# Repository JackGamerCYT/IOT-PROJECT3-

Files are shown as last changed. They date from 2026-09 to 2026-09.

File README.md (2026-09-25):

# ⚡ Smart Energy Monitoring & Intelligent Load Management — IoT Project 03

Hệ thống IoT end-to-end: ESP32-S3 đo dòng DC bằng ACS712, tính công suất và điện năng, tự sa thải tải ưu tiên thấp khi vượt ngưỡng đỉnh, gửi dữ liệu qua MQTT về backend FastAPI + cơ sở dữ liệu chuỗi thời gian, hiển thị trên dashboard web thời gian thực kèm trợ lý dữ liệu.

```
 [Adapter 12V]─[cầu chì 2A]─┬─[LM2596 → 5V]──> ESP32-S3, ACS712, relay, OLED, DS3231
                            └─[ACS712 IP+→IP−]─┬─[Relay1]── Quạt 12V  (ưu tiên CAO)
                                               └─[Relay2]── LED 12V   (ưu tiên THẤP)
 ESP32-S3: đo 4 khối/giây · điều khiển cục bộ 2 s/lần · RTC giữ giờ · đệm 600 bản ghi khi mất mạng
      │ MQTT 1883   smartenergy/node9988/{telemetry,status,state,event,cmd,ack}
      ▼
 Broker MQTT ──WSS 8884──> Dashboard (Vercel): realtime, gửi lệnh, đo độ trễ
      │ MQTT 1883
      ▼
 Backend FastAPI (Render 24/7 hoặc laptop) ── SQLite / PostgreSQL(Neon) ── REST /api/*
                                            └── Trợ lý dữ liệu /api/chat
```

## 1. Đáp ứng yêu cầu đề 3

| Yêu cầu trong đề | Cách làm | Ở đâu |
|---|---|---|
| Đo dòng cách ly, điện áp thấp | ACS712-05B, tải DC 12 V, không chạm điện lưới | §3 |
| ≥ 2 tải điều khiển được | Quạt 12 V (ưu tiên cao) + LED 12 V (ưu tiên thấp) | §3 |
| Ghi rõ định mức và bảo vệ | Cầu chì 2 A, diode flyback, relay 10 A/30 VDC, phân áp ADC | `docs/WIRING.md` |
| Telemetry dòng + công suất/điện năng, nêu công thức, đơn vị, tần số | Trung bình 64 mẫu/250 ms, công suất TB 2 s, tích lũy Wh | §4.1 |
| MQTT topic có cấu trúc, QoS, availability | 6 topic, LWT retained | §5 |
| Time-series DB + REST lịch sử/cấu hình | SQLite hoặc PostgreSQL, 5 bảng, 12 endpoint | §6, §7 |
| Dashboard: công suất tức thời, điện năng tích lũy, lịch sử, chi phí, trạng thái tải, cảnh báo | `index.html` | §7 |
| Quản lý tải theo ưu tiên, khôi phục khi an toàn **ổn định** | Máy trạng thái 3 điều kiện + dự báo công suất | §4.2 |
| Phân biệt trạng thái **yêu cầu** và **đã xác nhận** | `cmd_id` → `ack`, UI hiện Yêu cầu / Xác nhận / độ trễ / timeout | §4.3 |
| **Nâng cao**: phát hiện đỉnh, ngân sách điện năng ngày | `peak_today_w`, `ALARM_OVER_LIMIT`, `budget_wh`, `BUDGET_WARN/EXCEEDED` | §4.2 |
| Hành vi an toàn khi mất mạng | Kết nối lại không chặn, SAFE MODE, RTC giữ giờ, đệm và gửi bù | §4.4 |
| Thí nghiệm: sai số, độ trễ, managed/unmanaged, mất kết nối | `/api/stats`, xuất CSV, bảng kịch bản | §10 |

## 2. Cấu trúc repo

```
firmware/esp32_firmware/
  esp32_firmware.ino        Firmware v20 (ESP32-S3 + ACS712 + relay; DS3231/OLED tuỳ chọn)
  secrets.example.h         Copy thành secrets.h, điền WiFi (đã .gitignore)
backend/
  main.py                   FastAPI + MQTT ingest + SQLite/PostgreSQL + trợ lý dữ liệu
  requirements.txt
index.html                  Dashboard, đặt ở GỐC repo để Vercel phục vụ ngay tại "/"
tools/device_simulator.py   Giả lập ESP32 để test khi chưa có phần cứng
docs/
  WIRING.md                 Sơ đồ đấu nối, an toàn, quy trình hàn
  BAO_CAO_IOT_PROJECT03.docx  Báo cáo đồ án 14 đề mục
  PINOUT.xlsx               Bảng chân + danh mục linh kiện
  TRANG_THAI_TRIEN_KHAI.md  Hiện trạng deploy, cách kiểm chứng, việc còn lại
  KHAC_PHUC_SU_CO.md        Web không nhận dữ liệu: cách đọc Serial và tìm nguyên nhân
render.yaml                 Cấu hình deploy backend lên Render
PUSH.md                     Hướng dẫn đẩy code lên GitHub
```

## 3. Phần cứng

| Linh kiện | Chân | ESP32-S3 | Ghi chú |
|---|---|---|---|
| ACS712-05B | OUT | **GPIO 1** qua phân áp 10 kΩ/20 kΩ | 185 mV/A, 2.5 V tại 0 A |
| Relay 2CH (active LOW) | IN1 / IN2 | **GPIO 12 / 13** | Quạt / LED |
| DS3231 (0x68) | SDA / SCL | **GPIO 8 / 9** | Giữ giờ khi mất WiFi |
| SSD1306 (0x3C) | SDA / SCL | **GPIO 8 / 9** | Chung bus I2C với DS3231 |
| Buzzer qua S8050 | — | **GPIO 14** | `-1` nếu không lắp |
| LM2596 | OUT | 5 V / GND | Chỉnh 5.00 V trước khi cắm chip |

Chi tiết đấu nối, mạch động lực, an toàn: `docs/WIRING.md`.

## 4. Firmware v20

### 4.1 Đo lường
- Mỗi 250 ms đọc 64 mẫu `analogReadMilliVolts()` (dùng hiệu chuẩn eFuse của chip), lấy trung bình → `V_out = mV / DIVIDER_RATIO`
- `I [A] = (V_out − V_zero) / 185`; nếu `I < 0.04 A` coi bằng 0 (nhiễu nền). `V_zero` calib lúc khởi động khi 2 tải tắt, hoặc bằng lệnh `calibrate`
- `P [W] = 12 V × I` (điện áp coi là hằng, đo kiểm bằng VOM — ghi trong phần hạn chế)
- `E [Wh] += P × Δt/3600` mỗi khối, lưu Flash mỗi 60 s, reset lúc 0h theo giờ địa phương
- `power_w` gửi lên là **trung bình 2 s** (8 khối); telemetry và vòng điều khiển cùng chu kỳ 2 s

### 4.2 Máy trạng thái quản lý tải
```
LED_ON ──(P > P_peak liên tục ≥ 4 s)──> SHED_PEAK
SHED_PEAK ──(P < P_peak − H liên tục ≥ 15 s  VÀ  LED đã tắt ≥ 20 s
             VÀ  P + P_LED_ước_lượng < P_peak)──> LED_ON
LED_ON ──(E_hôm_nay ≥ ngân sách)──> SHED_BUDGET ──(sang ngày mới)──> LED_ON
LED đã tắt mà vẫn vượt ngưỡng ≥ 10 s → ALARM_OVER_LIMIT + buzzer (quạt ưu tiên cao KHÔNG bị cắt)
```
`P_LED_ước_lượng` được học từ bước nhảy công suất mỗi lần LED đổi trạng thái, nhờ vậy thiết bị không khôi phục khi biết chắc sẽ vượt ngưỡng lại. Ba điều kiện cùng lúc (trễ theo công suất, thời gian tắt tối thiểu, dự báo) là cơ chế chống đóng cắt liên tục.

### 4.3 Lệnh và xác nhận
Web/backend publish `cmd` kèm `cmd_id`. ESP32 áp dụng, publish `ack` chứa `cmd_id` và **trạng thái thực tế** sau khi áp dụng. Dashboard hiển thị riêng "Yêu cầu" và "Xác nhận", đo độ trễ, báo timeout sau 5 s. Bật/tắt tay khi đang AUTO sẽ chuyển thiết bị về MANUAL và sinh sự kiện `MANUAL_OVERRIDE`.

### 4.4 Khi mất mạng
- Kết nối lại WiFi/MQTT không chặn vòng lặp chính → đo và điều khiển vẫn chạy
- Mất broker > 30 s → `safe_mode = true`, tự bật quản lý tải cục bộ dù đang MANUAL
- DS3231 giữ giờ, nên bản ghi vẫn có mốc thời gian đúng; NTP → RTC mỗi 10 phút khi online
- Bộ đệm vòng 600 bản ghi (~20 phút). Có mạng lại thì gửi bù 5 gói/200 ms, gói bù có cờ `"buffered": true` và backend dùng `ts` của thiết bị làm mốc thời gian
- Kết nối lại sinh sự kiện `RECOVERED` kèm thời gian mất kết nối và số gói gửi bù

### 4.5 Nạp firmware
1. Arduino IDE, board **ESP32S3 Dev Module**
2. Library Manager cài **2 thư viện**: `PubSubClient` và `ArduinoJson`
3. Copy `secrets.example.h` → `secrets.h`, điền WiFi
4. Firmware mặc định `USE_RTC 0` / `USE_OLED 0` — chạy được khi **chưa gắn** DS3231 và OLED. Khi nào gắn thì đổi thành `1` và cài thêm `RTClib`, `Adafruit SSD1306`, `Adafruit GFX Library`
5. Có lắp phân áp thì đặt `DIVIDER_RATIO = 0.6667`
6. Upload, mở Serial 115200, **giữ 2 tải tắt** trong 1 giây đầu để calib điểm 0

## 5. Đặc tả MQTT

Gốc topic `smartenergy/<device_id>/`, mặc định `device_id = node9988`.

| Topic | Hướng | QoS / retain | Nội dung |
|---|---|---|---|
| `telemetry` | ESP32 → | 0 | số liệu đo, 2 s/lần |
| `status` | ESP32 → | LWT QoS 1, retained | `online` / `offline` |
| `state` | ESP32 → | retained | cấu hình + trạng thái tải |
| `event` | ESP32 → | 0 | `{type, detail, power_w, limit_w, ts}` |
| `cmd` | web/backend → ESP32 | 1 | `{cmd_id, ts, src, fan?, led?, auto_mode?, peak_limit_w?, hysteresis_w?, budget_wh?, calibrate?, reset_energy?}` |
| `ack` | ESP32 → | 0 | `{cmd_id, cmd_ts, ok, error?, ...state}` |

```json
{"dev":"node9988","ts":1789550319106,"seq":42,"current_a":0.352,"power_w":4.224,
 "energy_today_wh":0.0931,"energy_total_wh":1.204,"peak_today_w":4.301,
 "fan":true,"led":true,"led_shed":"NONE","auto_mode":true,"safe_mode":false,
 "peak_limit_w":3.5,"hysteresis_w":0.5,"budget_wh":0,"led_est_w":1.8,
 "alarm_over":false,"alarm_budget":false,"sensor_mv":2565.1,"zero_mv":2500.0,
 "rssi":-55,"uptime_s":84,"time_src":"ntp","rtc":true,"buffered_count":0}
```

Lý do chọn QoS: telemetry QoS 0 vì gói sau thay gói trước và mất gói được phát hiện qua `seq`; lệnh QoS 1 để không mất lệnh. PubSubClient chỉ publish được QoS 0, nên độ tin cậy của lệnh được bảo đảm ở tầng ứng dụng bằng ACK + timeout 5 s (ghi trong phần hạn chế).

Các loại sự kiện: `SHED`, `RESTORE`, `ALARM_OVER_LIMIT`, `ALARM_CLEAR`, `BUDGET_WARN`, `BUDGET_EXCEEDED`, `MANUAL_OVERRIDE`, `RECOVERED`.

## 6. Cơ sở dữ liệu

Backend tự chọn: có biến `DATABASE_URL` → PostgreSQL (Neon), không có → SQLite. Schema giống nhau, tạo tự động lần chạy đầu.

| Bảng | Cột chính |
|---|---|
| `telemetry` | ts_device, ts_server, seq, current_a, power_w, energy_today_wh, energy_total_wh, peak_today_w, fan, led, led_shed, auto_mode, safe_mode, peak_limit_w, hysteresis_w, budget_wh, alarm_over, alarm_budget, sensor_mv, rssi |
| `events` | ts_device, ts_server, type, detail, power_w, limit_w |
| `availability` | ts_server, status |
| `commands` | cmd_id, source, payload, ts_client, ts_seen_server, ts_ack_server, ack_ok, ack_error, ack_state, latency_ms |
| `settings` | tariff_vnd_per_kwh |

Dữ liệu cũ hơn `RETENTION_DAYS` (mặc định 60) được xóa tự động mỗi 6 giờ.

## 7. REST API (tài liệu tự sinh tại `/docs`)

| Method | Path | Mô tả |
|---|---|---|
| GET | `/api/health` | Trạng thái backend, broker, loại CSDL |
| GET | `/api/status` | Telemetry mới nhất, online/offline, độ tươi dữ liệu, Wh và chi phí hôm nay |
| GET | `/api/history?minutes=&bucket_s=` | Chuỗi thời gian đã gộp (trung bình/đỉnh) |
| GET | `/api/energy/daily?days=` | Wh, đỉnh, chi phí theo ngày |
| GET | `/api/events`, `/api/availability`, `/api/commands` | Nhật ký |
| POST | `/api/command` | `{"fan":true,"wait_ack_s":3}` → trả `requested` và `confirmed` |
| POST | `/api/config` | Ngưỡng, dải trễ, ngân sách, chế độ auto |
| GET/PUT | `/api/settings` | Đơn giá điện |
| GET | `/api/stats?minutes=` | Đỉnh, Wh, thời gian vượt ngưỡng, số lần đóng cắt, tỉ lệ nhận gói, độ trễ |
| POST | `/api/chat` | Trợ lý dữ liệu (§8) |
| GET | `/api/export/{bảng}.csv` | Xuất dữ liệu cho báo cáo |

Khi đặt biến `API_KEY`, mọi POST/PUT phải kèm header `X-API-Key`.

## 8. Trợ lý dữ liệu (chatbot)

Chạy hoàn toàn cục bộ, không gọi API bên ngoài: câu hỏi được chuẩn hoá (bỏ dấu), phân loại ý định bằng biểu thức chính quy, rồi **truy vấn thẳng cơ sở dữ liệu** và ghép câu trả lời từ số liệu thật. Vì không sinh văn bản tự do nên không có nguy cơ bịa số.

Ví dụ hỏi được: *hôm nay dùng bao nhiêu điện*, *tiền điện 7 ngày qua*, *đỉnh công suất hôm nay*, *sa thải tải mấy lần*, *thiết bị offline lúc nào*, *lệnh điều khiển gần đây*, *trạng thái hiện tại*, *so sánh theo ngày*.

Ra lệnh được: *bật quạt*, *tắt đèn*, *bật chế độ tự động*, *đặt ngưỡng 3.5 W*, *đặt ngân sách 20 Wh*. Những câu này **không tự thực thi**: backend trả về trường `action`, dashboard hiện nút "Xác nhận gửi lệnh", người dùng bấm thì mới gọi `/api/command`. Đây là ràng buộc an toàn bắt buộc khi cho ngôn ngữ tự nhiên điều khiển relay.

## 9. Chạy và triển khai

### 9.1 Chạy trên máy (phát triển và demo)
```bash
cd backend
pip install -r requirements.txt
python main.py                       # http://localhost:8000
python ../tools/device_simulator.py  # tuỳ chọn: giả lập ESP32 khi chưa có mạch
```

### 9.2 Hiện trạng triển khai (cập nhật 23/09/2026)

| Thành phần | Địa chỉ | Trạng thái |
|---|---|---|
| Backend + REST API | https://smart-energy-backend-rrvs.onrender.com | Đang chạy, `"db":"postgres"`, `"mqtt_connected":true` |
| Cơ sở dữ liệu | Neon PostgreSQL (pooled, Singapore) | Đã nối, bảng tạo tự động |
| Broker | broker.hivemq.com — TCP 1883 (thiết bị/backend), WSS 8884 (web) | Công khai, không xác thực |
| Dashboard | Vercel, deploy từ `index.html` ở gốc repo | Đang chạy |
| Repo | https://github.com/JackGamerCYT/IOT-PROJECT3- | — |

Kiểm tra nhanh toàn tuyến: `/api/health` → `/api/status` → `/api/history?minutes=10` → `/api/export/telemetry.csv?minutes=60` → SQL Editor trên Neon.

### 9.3 Các bước triển khai lại từ đầu: Neon + Render + Vercel
1. **Neon**: tạo project, copy chuỗi **pooled connection** (`...-pooler...?sslmode=require`)
2. **Render**: New → Blueprint → chọn repo (đã có `render.yaml`) → điền `DATABASE_URL` và `API_KEY` → Apply. Mở `<url>/api/health`, phải thấy `"db":"postgres"` và `"mqtt_connected":true`
3. **Vercel**: Add New → Project → Import repo → Framework Preset = Other, Root Directory để trống, Build/Output Command để trống → Deploy (file `index.html` nằm ngay ở gốc repo nên Vercel phục vụ được luôn)
4. Sửa `const DEFAULT_API = '...'` trong `index.html` thành URL Render rồi push lại; dán `API_KEY` vào ô API Key trên dashboard
5. **Chống ngủ**: gói free của Render tắt service sau ~15 phút không có request, kéo theo mất kết nối MQTT. Tạo job trên cron-job.org gọi `<url>/api/health` mỗi 10 phút

Vì sao cần Render: Vercel chỉ chạy hàm serverless sống vài giây mỗi request, không giữ được kết nối MQTT liên tục để hứng telemetry. Kiến trúc vì vậy tách **worker ingest** (Render) khỏi **giao diện** (Vercel).

Biến môi trường backend: `DATABASE_URL`, `API_KEY`, `MQTT_HOST`, `MQTT_PORT`, `MQTT_USER`, `MQTT_PASS`, `DEVICE_ID`, `TZ_OFFSET_H`, `RETENTION_DAYS`, `PORT`.

## 10. Kịch bản thí nghiệm

| # | Thí nghiệm | Cách làm | Số liệu thu |
|---|---|---|---|
| E1 | Sai số đo | Đồng hồ vạn năng/DC meter nối tiếp, 4 trường hợp: không tải, quạt, LED, cả hai; mỗi trường hợp 30 mẫu | Sai số tuyệt đối và %, độ lệch chuẩn |
| E2 | Độ trễ thiết bị → dashboard | Bật tải, đọc ô "Thiết bị → Dashboard" và `latency_device_to_backend_ms` | Trung bình, p95, max |
| E3 | Độ trễ lệnh → xác nhận | Bấm BẬT/TẮT 30 lần | Trung bình, p95, số lệnh timeout |
| E4 | Unmanaged vs managed | 10 phút AUTO tắt với cả 2 tải bật, ngưỡng 3.5 W → `/api/stats`; lặp lại với AUTO bật | Đỉnh W, Wh, `over_limit_duration_s`, `led_switch_count` |
| E5 | Chống đóng cắt liên tục | Đặt ngưỡng sát tổng công suất, so sánh với cấu hình `hysteresis_w = 0.1`, `MIN_OFF_MS = 0` | Số lần đóng cắt trong 10 phút |
| E6 | Mất mạng | Tắt router 60 s khi đang vượt ngưỡng | Thời điểm OFFLINE (LWT), LED vẫn bị cắt cục bộ, sự kiện `RECOVERED`, số gói gửi bù, khoảng trống dữ liệu |
| E7 | Ngân sách ngày | Đặt `budget_wh` nhỏ (0.5 Wh) | Thời điểm `BUDGET_WARN`/`BUDGET_EXCEEDED`, LED bị cắt |
| E8 | Độ trôi của RTC | So giờ DS3231 với NTP sau 24 giờ | Sai lệch giây/ngày |

## 11. Hạn chế và bảo mật

- Broker HiveMQ công khai không có xác thực: ai biết topic đều đọc và gửi lệnh được. Khắc phục bằng HiveMQ Cloud/EMQX có TLS + tài khoản (firmware và backend đã có sẵn `MQTT_USER`/`MQTT_PASS`) và ACL tách quyền topic `cmd`
- `API_KEY` chỉ bảo vệ REST API, không bảo vệ topic MQTT
- Không đo điện áp thật, giả định 12 V cố định; ACS712 5 A có độ phân giải hạn chế với tải nhỏ. Muốn chính xác hơn dùng INA219/INA226 đo cả V và I
- Một cảm biến đo tổng dòng nên công suất từng tải chỉ là ước lượng từ bước nhảy khi đóng cắt
- ESP32 chỉ publish QoS 0; bộ đệm offline nằm trong RAM nên mất khi reset (có thể nâng cấp sang LittleFS)

## 12. Thành viên

| STT | Họ tên | MSSV | Nhiệm vụ |
|---|---|---|---|
| 1 | Đặng Đình Mạnh | 24119055 | |
| 2 | | | |
| 3 | | | |
| 4 | | | |

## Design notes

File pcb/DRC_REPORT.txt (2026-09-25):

KHONG CO LOI - khoang cach toi thieu 0.4 mm

--- THONG MACH ---
Tat ca net lien mach.

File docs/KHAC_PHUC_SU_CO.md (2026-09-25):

# Web không nhận dữ liệu — cách tìm nguyên nhân

Trước hết cần hiểu: **web chỉ hiển thị, nó không tự tạo ra dữ liệu.** Chuỗi phải thông suốt:

```
ESP32 publish  →  broker.hivemq.com  →  (1) trình duyệt qua WSS 8884
                                      →  (2) backend Render qua TCP 1883 → Neon
```

Nếu ESP32 không publish thì cả web lẫn backend đều trống, badge **Thiết bị** đứng ở `?`.

## Bước 1 — Mở Serial Monitor, đọc 3 dòng đầu

Arduino IDE → Tools → Serial Monitor → **115200 baud** → nhấn nút EN trên ESP32 để khởi động lại.

Firmware v20 in ra ngay khi khởi động:

```
==========================================================
  SMART ENERGY v20  -  IoT PROJECT 03
  Device ID : node9988
  Broker    : broker.hivemq.com:1883
  Telemetry : smartenergy/node9988/telemetry
  ...
```

**Không thấy gì** → chọn sai cổng COM, sai baud, hoặc firmware chưa nạp được. Nạp lại, nhớ chọn board **ESP32S3 Dev Module**.

**Thấy topic là `smartenergy_node9988/telemetry`** (có gạch dưới, không có dấu `/` sau smartenergy) → bạn đang chạy **firmware cũ**. Đây là nguyên nhân phổ biến nhất: topic cũ khác topic web đang nghe nên hai bên không gặp nhau. Nạp lại file `firmware/esp32_firmware/esp32_firmware.ino` mới.

## Bước 2 — Đọc dòng CHẨN ĐOÁN, cứ 5 giây một lần

| Dòng trên Serial | Nghĩa là | Cách sửa |
|---|---|---|
| `WiFi "YOUR_WIFI": KHONG TIM THAY TEN WIFI` | Chưa tạo file `secrets.h` | Copy `secrets.example.h` thành `secrets.h`, điền đúng tên và mật khẩu WiFi, nạp lại |
| `SAI MAT KHAU WIFI` | Sai mật khẩu | Sửa `secrets.h` |
| `KHONG TIM THAY TEN WIFI` dù đã điền đúng | ESP32 chỉ bắt được WiFi **2.4 GHz** | Đổi sang băng tần 2.4 GHz, hoặc phát 4G từ điện thoại |
| `WiFi OK, IP 192.168.x.x ... MQTT chua noi duoc` | Vào mạng được nhưng không ra broker | Xem bước 3 |
| `MQTT loi rc=-2 (KHONG KET NOI DUOC TCP)` | Mạng chặn cổng 1883 | Mạng trường hay chặn. Phát 4G điện thoại thử lại |
| `>>> MQTT DA KET NOI <<<` | Đã lên broker | Sang bước 4 |

## Bước 3 — Mạng trường chặn cổng 1883

Đây là tình huống rất hay gặp ở mạng WiFi trường học. Cách kiểm tra nhanh: phát 4G từ điện thoại, đổi `secrets.h` sang WiFi đó, nạp lại. Nếu chạy được thì chắc chắn do mạng cũ chặn.

Lúc demo trước lớp nên chủ động dùng 4G điện thoại cho ESP32, đừng phụ thuộc WiFi trường.

## Bước 4 — MQTT đã kết nối mà web vẫn trống

Serial sẽ in mỗi 2 giây:

```
[#12 14:32:05] 2501.3mV I=0.000A P=0.00W E=0.000Wh | FAN:OFF LED:OFF(NONE) | MANUAL | MQTT:DA GUI buf=0
```

- `MQTT:DA GUI` → ESP32 đang phát thật. Nếu web vẫn trống thì lỗi nằm ở phía web:
  - Mở trang Vercel, nhìn badge **MQTT** trên đầu trang. Nếu đỏ thì trình duyệt không nối được broker (mạng chặn cổng 8884 hoặc dùng mạng công ty). Thử mở bằng 4G điện thoại.
  - Kéo xuống khung **MQTT LOG** ở cuối trang, nó in ra đúng topic đang nghe. So với dòng `Telemetry :` trên Serial, **hai chuỗi phải giống hệt nhau từng ký tự**.
- `MQTT:CHUA GUI` → mất kết nối broker giữa chừng, quay lại bước 2.

## Bước 5 — Kiểm tra bằng backend

Mở `https://smart-energy-backend-rrvs.onrender.com/api/status`

- `"latest": null` → backend chưa nhận gói nào. ESP32 chưa publish, hoặc publish sai topic.
- Có dữ liệu nhưng web trống → lỗi hiển thị phía trình duyệt, không phải phần cứng.

Backend nghe cùng một broker nhưng qua cổng 1883 từ máy chủ Render, không bị mạng trường ảnh hưởng. Nên nếu backend thấy dữ liệu mà trình duyệt không thấy, gần như chắc chắn mạng chỗ bạn chặn cổng 8884.

## Chưa gắn OLED và DS3231 thì sao?

Không sao cả. Firmware v20 đã đặt sẵn:

```cpp
#define USE_RTC  0
#define USE_OLED 0
```

Với cấu hình này chỉ cần **2 thư viện**: `PubSubClient` và `ArduinoJson`. Không cần RTClib, Adafruit SSD1306, Adafruit GFX — thiếu chúng là lỗi biên dịch chứ không phải lỗi chạy, và cũng là một nguyên nhân khiến "nạp mãi không được".

Mất RTC thì giờ lấy từ NTP khi có mạng; lúc mất mạng thiết bị vẫn cắt tải bình thường, chỉ là dữ liệu đệm không có mốc thời gian nên bỏ qua. Mất OLED thì chỉ mất phần hiển thị tại chỗ.

Khi nào mua module về, đổi hai dòng đó thành `1`, cài đủ 5 thư viện, nối SDA→GPIO 8, SCL→GPIO 9, VCC→3V3, GND→GND rồi nạp lại.

## Phần cứng tối thiểu để web chạy

Chỉ cần: **ESP32-S3 + cáp USB + WiFi**. Không cần ACS712, không cần relay, không cần OLED.

Firmware vẫn publish đều 2 giây một gói, chỉ là dòng điện đọc ra 0 A. Đủ để chứng minh toàn tuyến ESP32 → broker → backend → Neon → web hoạt động. Cắm thêm cảm biến và relay sau.

## Không có mạch thì test bằng giả lập

Trên laptop, tại thư mục dự án:

```powershell
pip install paho-mqtt
python tools/device_simulator.py
```

Giả lập gửi đúng topic và đúng định dạng như ESP32 thật. Nếu **giả lập hiện lên web mà ESP32 thì không**, lỗi chắc chắn nằm ở ESP32 hoặc mạng của nó, không phải ở web hay backend. Đây là phép thử phân định nhanh nhất.

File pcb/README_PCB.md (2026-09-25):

# Mạch in 1 lớp cho Project 03 — hướng dẫn ủi đồng

Board **100 × 80 mm**, **chỉ 1 lớp đồng mặt dưới (BOTTOM)**, toàn bộ linh kiện là loại **cắm (through-hole)**, module relay **để ngoài**, trên mạch chỉ có hàng rào cắm.

File trong thư mục này:

| File | Dùng để làm gì |
|---|---|
| `BOTTOM_mirrored_iron.pdf` | **Bản in để ủi** — đã lật gương sẵn, tỉ lệ 1:1 |
| `BOTTOM_normal_check.pdf` | Bản không lật, dùng đối chiếu khi dò mạch bằng đồng hồ |
| `TOP_placement.pdf` | Sơ đồ cắm linh kiện, nhìn từ mặt linh kiện |
| `smart_energy.kicad_pcb` | Mở bằng KiCad 7/8/9 nếu muốn sửa |
| `make_pcb.py` | Script sinh lại toàn bộ (sửa toạ độ rồi chạy `python3 make_pcb.py`) |
| `ASSEMBLY_SHEET.pdf` | **Phiếu lắp ráp 3 trang**: sơ đồ vị trí, thứ tự lắp có ô tick, bảng đấu dây ra module ngoài, danh sách đo kiểm |
| `BOM_DRILL.md` | Danh sách linh kiện + mũi khoan |
| `DRC_REPORT.txt` | Kết quả tự kiểm tra khoảng cách và thông mạch |

Thông số thiết kế: đường tín hiệu 0.6 mm, đường nguồn 1.0 mm, khe cách điện tối thiểu 0.4 mm, phủ đồng GND toàn mặt dưới, pad 2.0 mm (domino 2.6 mm).

Vùng phủ đồng GND có **thermal relief**: mỗi chân GND nối với vùng đồng bằng 4 nan rộng 0.9 mm thay vì dính liền cả mảng. Nhờ vậy mỏ hàn không bị hút nhiệt, mối hàn ăn thiếc dễ hơn nhiều. Script cũng tự bỏ các mảnh đồng mảnh hơn 0.6 mm và các mảnh đồng cô lập không nối GND, nên bản in không còn sợi đồng vụn khó ăn mòn.

## 1. Bảng nối chân

| Rào | Chân trên mạch | Nối tới |
|---|---|---|
| **J1** (1×22) | hàng **trái** ESP32-S3 DevKitC-1 | 3V3, IO8, IO9, IO12, IO13, IO14, 5V, GND |
| **J3** (1×22) | hàng **phải** ESP32-S3 DevKitC-1 | IO1 (ADC), GND |
| **J4** (1×4) | 3V3 · SDA · SCL · GND | module DS3231 |
| **J5** (1×4) | 3V3 · SDA · SCL · GND | module OLED SSD1306 |
| **J6** (1×5) | IN1 · IN2 · 3V3 · 5V · GND | **module relay 2 kênh để ngoài** |
| **J7** (1×3) | 5V · OUT · GND | module ACS712-05B |
| **J9** | GND · 12V+ | nguồn adapter 12 V vào |
| **F1** | IN · OUT | cầu chì 2 A (đế 5×20 hoặc đoạn dây) |
| **J8** | 12V+ · GND | 12 V **đã qua cầu chì**, đi ra ACS712 IP+ và cọc COM của relay |
| **J10** | IN+ · IN− | ngõ vào module LM2596 |
| **J11** | OUT+ · OUT− | ngõ ra 5 V của LM2596 |

Cách đấu module relay: tháo jumper JD-VCC trên module, nối **JD-VCC ↔ chân 5V của J6**, **VCC ↔ chân 3V3 của J6**, GND/IN1/IN2 theo tên. Nhờ vậy cuộn dây relay chạy 5 V còn opto chạy mức 3.3 V của ESP32, tắt dứt khoát.

Mạch động lực (12 V qua ACS712 rồi qua tiếp điểm relay tới quạt và đèn) đi **dây ngoài**, không chạy trên mạch in. Trên board chỉ có dòng nuôi mạch điều khiển, nên đường 12 V rộng 1 mm là đủ.

## 2. Hai dây nối trên mặt linh kiện (JW1, JW2)

Mạch 1 lớp không tránh được vài chỗ giao nhau. Thiết kế này chỉ cần **2 đoạn dây đồng** hàn ở **mặt linh kiện**:

- **JW1** — nối GND bắc qua đường 5 V, dài 4.8 mm
- **JW2** — nối GND bắc qua hai đường IN1/IN2, dài 7 mm

Dùng chân điện trở cắt ra là vừa. Thiếu 2 dây này thì phần GND của DS3231, OLED, relay và tụ lọc sẽ hở mạch.

## 3. Quy trình ủi đồng

1. **In** file `BOTTOM_mirrored_iron.pdf` bằng máy in laser lên giấy in chuyển nhiệt (hoặc giấy ảnh bóng). Trong hộp thoại in phải chọn **Scale 100% / Actual size**, tuyệt đối không chọn Fit to page. In xong đo lại board trên giấy phải đúng 100 × 80 mm.
2. **Cắt phíp** đồng 1 mặt đúng 100 × 80 mm, chà mặt đồng bằng giấy nhám mịn rồi lau cồn cho sạch dầu mỡ.
3. **Ủi**: úp mặt mực xuống đồng, bàn ủi để mức cotton (khoảng 160–180 °C), ủi đều 5–8 phút, miết kỹ mép board.
4. **Ngâm nước** ấm 10 phút rồi bóc giấy thật từ từ. Chỗ nào mực thiếu thì tô lại bằng bút lông dầu.
5. **Ăn mòn**: FeCl₃ hoặc hỗn hợp HCl + H₂O₂ (3:1), lắc nhẹ 10–20 phút. **Đeo găng và kính, làm nơi thoáng.**
6. **Rửa sạch**, lau mực bằng cồn hoặc axeton.
7. **Khoan**: mũi 0.9 mm cho điện trở/transistor, 1.0 mm cho hàng rào và tụ, 1.3 mm cho domino và cầu chì, 3.2 mm cho 4 lỗ bắt ốc.
8. **Kiểm tra trước khi hàn**: đồng hồ nấc thông mạch, đo 12V–GND, 5V–GND, 3V3–GND, **không được kêu**. Soi đèn tìm đường đứt hoặc dính.
9. **Hàn** theo thứ tự: dây nối JW1/JW2 → điện trở, diode → transistor, tụ → hàng rào → domino → cuối cùng là cầu chì và còi.
10. **Chỉnh LM2596 ra đúng 5.00 V trước khi cắm ESP32.** Cấp 12 V vào J9, đo tại J11 OUT+ và GND.

## 4. Kiểm tra sau khi hàn

| Bước | Cách đo | Đạt khi |
|---|---|---|
| Ngắn mạch nguồn | Đo trở giữa 12V–GND, 5V–GND, 3V3–GND khi chưa cắm module | Không kêu tít, trở > vài trăm Ω |
| Điện áp | Cấp 12 V, đo J11 OUT+ | 5.00 V ± 0.05 |
| 3V3 | Cắm ESP32, đo chân 3V3 của J4 | 3.3 V |
| I2C | Đo thông mạch J4.SDA ↔ J5.SDA ↔ chân IO8 của J1 | Kêu tít |
| Relay | Đo J6.IN1 ↔ IO12 của J1, J6.IN2 ↔ IO13 | Kêu tít |
| ADC | Đo J7.OUT ↔ R1, và R1 ↔ IO1 của J3 | Kêu tít |
| GND | Đo GND của J4, J5, J6, J7 với GND của J9 | Tất cả đều thông (nhờ JW1, JW2) |

## 5. Ghi chú thiết kế

- Cầu phân áp **R1 10 kΩ / R2 20 kΩ** hạ mức ra của ACS712 từ 0–5 V xuống 0–3.33 V cho ADC. Sau khi lắp nhớ đặt `DIVIDER_RATIO = 0.6667` trong firmware.
- **C2 100 nF** song song R2 lọc nhiễu cho đường ADC, **C1 100 µF** lọc 5 V, **C3 100 nF** lọc 3V3.
- **Q1 S8050** lái còi, **R3 1 kΩ** hạn dòng cực nền. Chân theo thứ tự **E–B–C** từ trên xuống, mặt phẳng quay ra ngoài board; kiểm tra lại datasheet transistor bạn mua.
- LM2596 lấy nguồn **trước** ACS712, nên dòng của mạch điều khiển không bị tính vào phép đo tải.
- Thứ tự chân của J1/J3 lấy theo tài liệu ESP32-S3-DevKitC-1 v1.1 của Espressif. Nếu board bạn mua khác thứ tự, sửa `J1_NETS`/`J3_NETS` trong `make_pcb.py` rồi chạy lại script.

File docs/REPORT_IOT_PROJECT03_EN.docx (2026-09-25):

HO CHI MINH CITY UNIVERSITY OF TECHNOLOGY AND EDUCATION

FACULTY OF ELECTRICAL AND ELECTRONICS ENGINEERING

FINAL COURSE PROJECT REPORT

COURSE: IOT FOUNDATIONS AND APPLICATIONS

PROJECT 03: SMART ENERGY MONITORING AND INTELLIGENT LOAD MANAGEMENT

Team members:

Dang Dinh Manh – 24119055

……………………… – …………

……………………… – …………

……………………… – …………

Supervisor: ………………………

Ho Chi Minh City, September 2026

# TABLE OF CONTENTS

(Open in Word, right-click the table of contents, choose Update Field → Update entire table to generate page numbers.)

# 1. INTRODUCTION AND PROBLEM STATEMENT

Household and small laboratory electrical demand frequently exceeds a safe threshold for short intervals when several appliances run at the same time. The consequences are nuisance breaker trips, wasted energy and shortened wiring life. Users, however, rarely know how much power they are drawing at a given moment, or which device should be disconnected before the limit is crossed.

This project builds a complete IoT system that addresses the problem at a safe model scale: it measures the current and power of two 12 V DC loads in real time, stores the history in a time-series database, displays it on a web interface, automatically sheds the low-priority load when demand exceeds a peak limit, and restores it only when conditions have been stably safe.

Specific objectives:

- Measure current and power with a quantified error; raw ADC counts are not accepted as a final measurement.
- Transmit data over MQTT with a structured topic hierarchy and detect device online/offline state through the Last Will and Testament mechanism.
- Store time-series data and expose REST APIs for history, configuration and statistics.
- Manage loads by priority, with an anti-chattering mechanism, and keep operating when the network is lost.
- Provide a real-time dashboard that clearly separates the requested state from the state the device has actually confirmed.
- Add an advanced component: peak demand detection and a daily energy budget.

Scope: the entire power circuit operates at 12 VDC and no part touches the mains supply, in accordance with the safety requirement of the assignment.

# 2. REQUIREMENTS AND THEORETICAL BACKGROUND

## 2.1. Requirement mapping

Requirement | Implementation in this project
Isolated, low-voltage current measurement | ACS712-05B Hall-effect sensor, 12 V DC loads
At least two controllable loads | 12 V fan (high priority) and 12 V LED lamp (low priority)
MQTT with structured topics, QoS, availability | Six topics under smartenergy/node9988, retained LWT
Time-series database and REST API | SQLite or PostgreSQL, five tables, twelve endpoints
Dashboard with full metrics and alarms | Real-time web interface, charts, event log
Priority-based load management, anti-chattering | State machine with hysteresis, minimum time and power prediction
Requested state distinct from acknowledged state | cmd_id and ack message pair
Advanced component | Peak demand detection and daily energy budget
Safe behaviour during network loss | Local safe mode, RTC timekeeping, store-and-forward buffer

Table 2.1. Mapping between assignment requirements and the implemented solution

## 2.2. Hall-effect current sensing

The ACS712 routes the load current through an integrated copper conduction path. The magnetic field produced is proportional to the current, is sensed by a Hall element and converted into an output voltage. The 5 A variant has a sensitivity of 185 mV/A and an output of half the supply voltage at zero current, that is 2.5 V on a 5 V rail. The conduction path is galvanically isolated from the signal circuit with a nominal withstand voltage of 2.1 kV, which is why this device satisfies the isolated-measurement requirement of the assignment.

I [A] = (V_out - V_zero) / 0.185

V_out : voltage at the sensor OUT pin (V)

V_zero: output voltage at zero current, obtained by calibration

Because the load is DC, the mean of many samples reflects the true load current and no RMS computation is required. Conversely, applying an RMS formula to a noisy DC signal adds the noise in quadrature and biases the result upwards; this was an actual defect found and corrected during development, described in chapter 12.

## 2.3. Power and energy

P [W] = U x I (U = 12 V, treated as constant)

E [Wh] = sum of P x dt / 3600

Cost = E/1000 x tariff [currency per kWh]

The backend recomputes energy by trapezoidal integration over the telemetry series in order to cross-check the accumulator kept on the device. Gaps longer than ten seconds are excluded from the integral so that a loss of connectivity does not produce a fabricated value.

## 2.4. Hysteresis control and anti-chattering theory

A controller with a single threshold oscillates continuously whenever the measured quantity sits near that threshold. The classical remedy is a hysteresis band: shed the load when P exceeds P_peak but restore it only when P falls below P_peak minus H. For this system hysteresis alone is still insufficient, because restoring the load itself raises the demand and may immediately exceed the limit again. The project therefore applies three simultaneous conditions: a hysteresis band in power, a minimum dwell time, and a prediction step for the demand after restoration.

## 2.5. The MQTT protocol

MQTT is a publish/subscribe protocol over TCP, well suited to embedded devices because of its small packets and long-lived connections. It defines three quality-of-service levels: QoS 0 delivers at most once, QoS 1 at least once and QoS 2 exactly once. The Last Will and Testament mechanism lets the broker publish a predefined message when it loses contact with a device, so failures are detected without polling. The retained flag makes a newly subscribed client receive the most recent message on a topic immediately.

# 3. SYSTEM ARCHITECTURE

[12V adapter]-[2A fuse]-+-[LM2596 -> 5V]-> ESP32-S3, ACS712,

| relays, OLED, DS3231

+-[ACS712]-+-[Relay 1]- 12V fan (HIGH priority)

+-[Relay 2]- 12V LED (LOW priority)

ESP32-S3: 4 sample blocks/s, local control loop every 2 s,

RTC timekeeping, 600-record store-and-forward buffer

| MQTT 1883 smartenergy/node9988/{telemetry,status,state,event,cmd,ack}

v

MQTT broker --WSS 8884--> Dashboard (Vercel): live data, commands,

latency measurement

| MQTT 1883

v

FastAPI backend (Render, 24/7) -- SQLite / PostgreSQL (Neon)

-- REST /api/* + data assistant /api/chat

Figure 3.1. Overall system architecture

The system has four layers. The device layer (ESP32-S3) performs measurement and real-time control; every switching decision is taken here, so protection does not depend on the network. The communication layer is the MQTT broker, which mediates between device, backend and interface. The data layer is the FastAPI backend: it subscribes to every topic, writes to the database and exposes REST APIs. The application layer is the web dashboard, which receives live values directly from the broker over WebSocket Secure and fetches history from the REST API.

One design point deserves emphasis. The dashboard is deployed on Vercel, a platform that serves static files and serverless functions whose lifetime is a few seconds per request. Such a platform cannot hold a persistent MQTT connection to ingest telemetry, so the ingest process must run on an always-on service (Render, or a local computer). Separating the ingest worker from the interface is therefore a technical consequence, not an arbitrary choice.

Main data flow: the ESP32 measures and publishes telemetry every two seconds; the backend writes it into the telemetry table with two timestamps, the instant the device created the packet and the instant the server received it, which makes end-to-end latency measurable. The control flow runs in the opposite direction: the dashboard or the REST API publishes a command on the cmd topic, the device applies it and publishes an ack message; the backend records both the command and the acknowledgement and computes the latency between them.

# 4. HARDWARE

## 4.1. Bill of materials

No. | Component | Key specification | Role
1 | ESP32-S3 DevKitC-1 N16R8 | Xtensa LX7 dual-core 240 MHz, Wi-Fi, 12-bit ADC | Main controller
2 | ACS712-05B | ±5 A, 185 mV/A, 2.1 kV isolation | Load current sensing
3 | 2-channel 5 V relay module | Opto-isolated, active low, 10 A/30 VDC contacts | Load switching
4 | LM2596 buck converter | 4–35 V in, 5.0 V out, 3 A | Supply for the control circuit
5 | DS3231 | I2C RTC, ±2 ppm, battery backup | Timekeeping without network
6 | SSD1306 OLED | 0.96 inch, 128×64, I2C | Local display
7 | 12 V DC fan | about 0.2–0.4 A | Load 1, high priority
8 | 12 V LED bar | about 0.1–0.3 A | Load 2, low priority
9 | 12 V – 2 A adapter | | Main supply
10 | 2 A fuse, 1N4007 diode, 10 kΩ/20 kΩ resistors | | Protection and ADC divider

Table 4.1. Bill of materials

## 4.2. Pin assignment

Component | Pin | ESP32-S3 | Function
ACS712 | OUT (through 10 kΩ/20 kΩ divider) | GPIO 1 (ADC1_CH0) | Analogue current signal
Relay module | IN1 | GPIO 12 | Load 1 – 12 V fan
Relay module | IN2 | GPIO 13 | Load 2 – 12 V LED
DS3231 (0x68) | SDA / SCL | GPIO 8 / GPIO 9 | Real-time clock
SSD1306 (0x3C) | SDA / SCL | GPIO 8 / GPIO 9 | Display, shared I2C bus
Buzzer via S8050 | Base through 1 kΩ | GPIO 14 | Over-limit alarm
LM2596 | OUT+ / OUT− | 5V / GND | 5 V supply

Table 4.2. Pin connection table

## 4.3. Protection design and engineering decisions

- A 10 kΩ/20 kΩ divider at the ACS712 output: at 5 A the sensor output reaches 3.43 V, beyond the safe ADC range of the ESP32-S3. The ratio of 0.667 maps the 0–5 V range onto 0–3.33 V.
- A 2 A fuse on the +12 V line, placed ahead of the sensor, protects the entire power circuit.
- A 1N4007 diode in reverse parallel with the fan suppresses the back-EMF produced when the inductive load is switched off.
- Relay contacts rated 10 A/30 VDC, many times the actual load current of under 1 A, provide a wide safety margin.
- Removing the JD-VCC jumper on the relay module and supplying VCC from 3.3 V ensures the ESP32 logic high fully turns the optocoupler off.
- The ESP32-S3 was chosen over the classic ESP32 because GPIO 12 on the latter is the MTDI strapping pin; a high level at boot selects the wrong flash voltage and prevents start-up.
- The LM2596 is fed upstream of the sensor so that the control circuit current is not counted in the load measurement.

# 5. PROTOCOL AND NETWORKING

## 5.1. Topic hierarchy and quality of service

Topic | Direction | QoS / retain | Content
smartenergy/node9988/telemetry | Device → system | QoS 0 | Measurements, every 2 s
smartenergy/node9988/status | Device → system | QoS 1, retained, LWT | online / offline
smartenergy/node9988/state | Device → system | retained | Configuration and load state
smartenergy/node9988/event | Device → system | QoS 0 | Shedding, restoration, alarms
smartenergy/node9988/cmd | Web/backend → device | QoS 1 | Commands carrying cmd_id
smartenergy/node9988/ack | Device → system | QoS 0 | Command acknowledgement and actual state

Table 5.1. MQTT topic specification

Telemetry uses QoS 0 because each message completely supersedes the previous one; loss is detected through the monotonically increasing seq field, which also yields a packet success rate without the handshake overhead of QoS 1. Commands are subscribed at QoS 1. The PubSubClient library on the ESP32 only publishes at QoS 0, so command reliability is guaranteed at application level by the cmd_id/ack pair with a five second timeout; this is a known limitation stated in chapter 13.

## 5.2. Message format

{"dev":"node9988","ts":1789550319106,"seq":42,

"current_a":0.352,"power_w":4.224,"energy_today_wh":0.0931,

"energy_total_wh":1.204,"peak_today_w":4.301,

"fan":true,"led":true,"led_shed":"NONE","auto_mode":true,"safe_mode":false,

"peak_limit_w":3.5,"hysteresis_w":0.5,"budget_wh":0,"led_est_w":1.8,

"alarm_over":false,"alarm_budget":false,"sensor_mv":2565.1,"zero_mv":2500.0,

"diff_mv":65.1,"rssi":-55,"uptime_s":84,"time_src":"ntp","buffered_count":0}

The ts field is Unix time in milliseconds, taken from NTP or from the DS3231. Every message carries the device identifier, so the system scales to multiple nodes without changing the structure.

## 5.3. Availability detection

On connection the device registers an "offline" will on the status topic with the retained flag, then publishes "online" itself. If the device loses power or drops off the network, the broker publishes "offline" once the fifteen second keepalive expires, so the dashboard and the backend learn exactly when the device stopped working. The dashboard additionally tracks data freshness: if no new packet arrives within six seconds, that is three telemetry periods, it displays a stale-data warning.

# 6. BACKEND AND DATA

## 6.1. Database schema

Table | Main columns | Purpose
telemetry | ts_device, ts_server, seq, current_a, power_w, energy_today_wh, peak_today_w, fan, led, led_shed, auto_mode, safe_mode, peak_limit_w, alarm_over, sensor_mv, rssi | Measurement time series
events | ts_device, ts_server, type, detail, power_w, limit_w | Shedding, restoration, alarms
availability | ts_server, status | Online/offline history
commands | cmd_id, source, payload, ts_client, ts_seen_server, ts_ack_server, ack_ok, latency_ms | Command log and acknowledgement latency
settings | key, value | Electricity tariff

Table 6.1. Database schema

The backend supports SQLite (local development) and PostgreSQL (the Neon service for 24/7 deployment) simultaneously. The data access layer converts the syntax between the two engines, so a single code base runs in both environments. Data older than the configured retention period is purged every six hours.

## 6.2. REST endpoints

Endpoint | Function
GET /api/status | Latest telemetry, availability, data freshness, energy and cost for the day
GET /api/history?minutes=&bucket_s= | Aggregated time series, capped at 300 points
GET /api/energy/daily?days= | Energy, peak and cost per day
GET /api/events | /api/availability | /api/commands | Logs
POST /api/command | Send a command, wait for acknowledgement, return requested and confirmed state
POST /api/config | Peak limit, hysteresis, budget, automatic mode
GET /api/stats?minutes= | Statistics for the experimental chapter
POST /api/chat | Data assistant
GET /api/export/{table}.csv | Data export for the report

Table 6.2. REST API list

The /api/stats endpoint aggregates, over a time window: peak power, mean power, energy, total time above the limit, load switching count, packet success rate derived from gaps in seq, and both device-to-server and command-to-acknowledgement latency as mean, 95th percentile and maximum. This is exactly the data set used in the experimental chapter.

# 7. APPLICATION AND USER INTERFACE

The dashboard is a single web page. It receives live values directly from the broker over WebSocket Secure and fetches history from the REST API, so the interface keeps showing real-time data even when the backend is temporarily unavailable; only the history section is lost.

- Six metric cards: instantaneous power with its limit, current, energy for the day with a budget progress bar, estimated cost, peak power for the day, and load management mode.
- A real-time chart with a selectable window of 1, 5, 15 or 60 minutes and three series: power, peak limit and current; power on the left axis in watts, current on the right axis in amperes.
- A load control panel that separates the requested state from the state confirmed by the device, with acknowledgement latency and a timeout warning.
- A configuration panel: automatic mode, peak limit, hysteresis, daily budget, zero-point calibration, energy reset and electricity tariff.
- An alarm and event log that merges live messages with history fetched from the backend.
- A history panel: power charts over 1 hour, 6 hours, 24 hours and 7 days, plus a bar chart of daily energy for the last seven days, refreshed automatically every thirty seconds.
- An experiment panel: latency in both directions, packet success rate, unacknowledged command count, a statistics button and CSV export.
- A data assistant and an MQTT log window for troubleshooting during the live demonstration.

The local OLED shows the time from the DS3231, power, current, energy for the day, the state of both loads, Wi-Fi and MQTT icons and the number of buffered records. This demonstrates during the presentation that the device operates independently of the network.

## 7.1. Data assistant

The assistant runs entirely inside the backend. A question is normalised by stripping Vietnamese diacritics, classified into an intent by regular expressions, and then answered by querying the database directly and formatting the real figures. Because no free text is generated, there is no possibility of fabricated numbers, unlike an approach based on a large language model.

For control phrasings the system does not execute anything by itself; it returns an action descriptor, the interface shows a confirmation button, and only a user click sends the command. This is a mandatory safety constraint when natural language is allowed to operate relays.

## 7.2. Backend ingest code

The backend subscribes to all six topics. For telemetry messages the noteworthy detail is the handling of buffered packets: a packet carrying the "buffered" flag uses the device timestamp as its storage timestamp, so data forwarded after a network outage lands at the correct position on the history chart instead of piling up at the moment of reception.

def on_message(client, userdata, msg):

ts = now_ms()

kind = msg.topic.rsplit("/", 1)[-1]

raw = msg.payload.decode("utf-8", "replace")

try:

if kind == "status":

status = raw.strip().lower()

if status != live["status"]:

exec_("INSERT INTO availability(ts_server,status) VALUES(?,?)", (ts, status))

live.update(status=status, status_ts=ts)

return

data = json.loads(raw)

if kind == "telemetry":

vals = [int(v) if isinstance(v, bool) else v for v in (data.get(c) for c in TEL_COLS)]

# Gói gửi bù sau khi mất mạng: lấy mốc thời gian của thiết bị làm ts_server

ts_row = int(data["ts"]) if data.get("buffered") and data.get("ts") else ts

exec_(f"INSERT INTO telemetry(dev,ts_device,ts_server,seq,{','.join(TEL_COLS)}) "

f"VALUES(?,?,?,?,{','.join('?' * len(TEL_COLS))})",

(data.get("dev"), data.get("ts") or None, ts_row, data.get("seq"), *vals))

if not data.get("buffered") and live["status"] != "online":

live.update(status="online", status_ts=ts)

elif kind == "state":

live["state"] = data

elif kind == "event":

exec_("INSERT INTO events(dev,ts_device,ts_server,type,detail,power_w,limit_w) VALUES(?,?,?,?,?,?,?)",

(data.get("dev"), data.get("ts") or None, ts, data.get("type"), data.get("detail"),

data.get("power_w"), data.get("limit_w")))

elif kind == "cmd":

cidv = data.get("cmd_id") or f"anon-{ts}"

db.insert_ignore("commands", ["cmd_id", "dev", "source", "payload", "ts_client", "ts_seen_server"],

(cidv, DEVICE_ID, data.get("src", "unknown"), raw, data.get("ts"), ts), "cmd_id")

exec_("UPDATE commands SET ts_seen_server=COALESCE(ts_seen_server,?) WHERE cmd_id=?", (ts, cidv))

elif kind == "ack":

cidv = data.get("cmd_id", "")

row = q("SELECT ts_seen_server FROM commands WHERE cmd_id=?", (cidv,), one=True)

lat = ts - row["ts_seen_server"] if row and row["ts_seen_server"] else None

exec_("UPDATE commands SET ts_ack_server=?, ack_ok=?, ack_error=?, ack_state=?, latency_ms=? WHERE cmd_id=?",

(ts, int(bool(data.get("ok"))), data.get("error"), raw, lat, cidv))

live["state"] = {k: v for k, v in data.items() if k not in ("cmd_id", "cmd_ts", "ok", "error")}

if cidv in ack_waiters:

ack_waiters[cidv].set()

except Exception as e:

print(f"[MQTT] bad message on {msg.topic}: {e} | {raw[:120]}")

## 7.3. Database access layer

The DB class lets the same source run on SQLite during development and on PostgreSQL in production by translating parameter markers and conditional insert syntax:

class DB:

def __init__(self, url: str, sqlite_path: str):

self.pg = url.startswith(("postgres://", "postgresql://"))

if self.pg:

import psycopg

from psycopg.rows import dict_row

from psycopg_pool import ConnectionPool

self.pool = ConnectionPool(url, min_size=1, max_size=5, timeout=15,

kwargs={"row_factory": dict_row, "autocommit": True})

self.pool.wait(timeout=30)

print(f"[DB] PostgreSQL: {url.split('@')[-1].split('?')[0]}")

else:

self.conn = sqlite3.connect(sqlite_path, check_same_thread=False)

self.conn.row_factory = sqlite3.Row

self.lock = threading.Lock()

print(f"[DB] SQLite: {sqlite_path}")

def _sql(self, sql: str) -> str:

return sql.replace("?", "%s") if self.pg else sql

def query(self, sql, args=(), one=False):

if self.pg:

with self.pool.connection() as c:

rows = c.execute(self._sql(sql), args).fetchall()

else:

with self.lock:

rows = [dict(r) for r in self.conn.execute(sql, args).fetchall()]

return (rows[0] if rows else None) if one else rows

def execute(self, sql, args=()):

if self.pg:

with self.pool.connection() as c:

c.execute(self._sql(sql), args)

else:

with self.lock:

self.conn.execute(sql, args)

self.conn.commit()

def insert_ignore(self, table, cols, args, key):

ph = ",".join("?" * len(cols))

tail = f" ON CONFLICT ({key}) DO NOTHING" if self.pg else ""

head = "INSERT INTO" if self.pg else "INSERT OR IGNORE INTO"

self.execute(f"{head} {table}({','.join(cols)}) VALUES({ph}){tail}", args)

def upsert_setting(self, key, value):

if self.pg:

self.execute("INSERT INTO settings VALUES(?,?) ON CONFLICT (key) DO UPDATE SET value=EXCLUDED.value", (key, value))

else:

self.execute("INSERT OR REPLACE INTO settings VALUES(?,?)", (key, value))

def init_schema(self):

## 7.4. Real-time chart code

The browser keeps a WebSocket connection to the broker and appends a point as soon as a message arrives, rather than polling the server. The buffer is trimmed by time rather than by point count, so changing the display window does not distort the horizontal axis:

function rtRedraw() {

const cut = Date.now() - RT_WINDOW_MIN * 60000;

while (rtBuf.length && rtBuf[0].t < cut) rtBuf.shift();

while (rtBuf.length > RT_MAX_POINTS) rtBuf.shift();

rt.data.labels = rtBuf.map(d => timeStr(d.t));

rt.data.datasets[0].data = rtBuf.map(d => d.p);

rt.data.datasets[1].data = rtBuf.map(d => d.lim);

rt.data.datasets[2].data = rtBuf.map(d => d.i);

rt.update('none');

$('rt-n').textContent = rtBuf.length;

}

function rtPush(t, p, limit, i) {

rtBuf.push({ t, p, lim: limit, i });

if (!S.paused) rtRedraw();

}

$('rt-range').onchange = e => {

RT_WINDOW_MIN = Number(e.target.value);

rtBuf.length = 0; // nạp lại từ backend cho đủ cửa sổ mới

if (S.apiOk) prefillChart(); else rtRedraw();

};

$('rt-pause').onclick = () => {

# 8. CONTROL AND SYSTEM INTELLIGENCE

## 8.1. Priority-based load shedding algorithm

Every 2 seconds, with P the 2-second mean power:

IF managed AND LED is on AND (P > P_peak continuously >= 4 s)

-> SHED the LED, state SHED_PEAK, emit event SHED

ELSE IF managed AND LED is off AND state = SHED_PEAK

AND (P < P_peak - H continuously >= 15 s)

AND (LED has been off >= 20 s)

AND (P + estimated P_LED < P_peak)

-> RESTORE the LED, emit event RESTORE

IF LED is off AND P still > P_peak continuously >= 10 s

-> ALARM_OVER_LIMIT + buzzer (the high-priority fan is never shed)

The three restoration conditions complement one another. The hysteresis band prevents oscillation caused by measurement noise around the threshold. The minimum dwell time prevents oscillation caused by rapidly varying loads. The prediction condition is the most important: the power of the LED lamp is estimated from the power step observed each time the lamp changes state, using an exponential moving average with weights 0.7 and 0.3. If the present demand plus the estimated lamp power exceeds the limit, the system does not restore, because it knows the load would have to be shed again immediately.

The fan is the high-priority load and is never shed automatically. When demand remains above the limit after the lamp has been shed, the system raises an alarm and leaves the decision to the operator instead of disconnecting an important appliance on its own.

## 8.2. Advanced component: peak detection and daily energy budget

The device continuously records the peak power of the day and publishes it in telemetry. When demand stays above the limit while the low-priority load has already been shed, the system raises a peak alarm, that is, it detects a situation in which the available shedding measure is insufficient.

The daily energy budget allows a watt-hour quota per day. At eighty per cent of the quota the system issues an early warning. Once the quota is exceeded the low-priority load is shed and is only re-enabled on the following day. This policy is fully explainable in terms of rules, which makes it convenient to defend and to verify, unlike a black-box approach.

## 8.3. Requested state versus confirmed state

Every command carries a randomly generated cmd_id. The device applies the command and then publishes an ack message containing the same cmd_id together with the actual state of both relays after application. The interface displays two separate lines, measures the latency with the browser clock and reports an error if no acknowledgement arrives within five seconds. This mechanism exposes the true nature of a distributed system: a command that has been sent is not a command that has been executed.

One case deserves attention: a user switching a load by hand while automatic mode is active. The device switches to manual mode and emits a MANUAL_OVERRIDE event, rather than letting two mechanisms fight over the same relay.

## 8.4. Measurement code

The following function runs four times per second on the ESP32. Three technical points are worth noting: averaging 64 samples to suppress noise, taking the absolute value of the deviation so that the measurement does not depend on the sensor wiring polarity, and automatically re-calibrating the zero point while both loads are off.

void measureBlock() {

unsigned long now = millis();

float dt_h = (last_block ? (now - last_block) : BLOCK_MS) / 3600000.0;

last_block = now;

last_mv = readMvAvg(SAMPLES_PER_BLOCK);

diff_mv = last_mv - zero_mv;

// TRỊ TUYỆT ĐỐI: tải một chiều, nếu lỡ đấu ngược IP+/IP- thì vẫn đo đúng độ lớn

float i = fabs(diff_mv) / ACS_MV_PER_A;

if (i < I_DEADBAND_A) i = 0;

current_a = i;

power_w = V_NOMINAL * current_a;

// TỰ HIỆU CHỈNH ĐIỂM 0: khi cả 2 tải đang TẮT, kéo zero_mv bám theo mức thực tế

// (bù trôi do đổi nguồn USB <-> LM2596, do nhiệt độ). Hằng số thời gian ~12 giây.

if (!fan_on && !led_on) {

if (!zero_track_ms) zero_track_ms = now;

if (now - zero_track_ms > 3000 && fabs(diff_mv) < 400)

zero_mv += (last_mv - zero_mv) * 0.02f;

} else {

zero_track_ms = 0;

}

energy_today_wh += power_w * dt_h;

energy_total_wh += power_w * dt_h;

sum_block_p += power_w; n_block++;

The absolute value arises from a real defect: the first version wrote "if (i < deadband) i = 0", which forced every negative value to zero. When the IP+ and IP− terminals of the sensor were connected the other way round, the output voltage fell below the 2.5 V reference, the computed current became negative and was discarded entirely; the system reported 0 A while the load was running. Chapter 12 records the full account.

The automatic zero tracking addresses reference drift when the supply changes. Measurements recorded a drift of about 30 mV between USB powering and LM2596 powering, equivalent to an error of 0.17 A if left uncompensated.

## 8.5. Load management state machine code

void controlStep() {

unsigned long now = millis();

if (learn_pending && now - led_switch_ms >= TELEMETRY_MS) {

float delta = fabs(demand_w - p_before_switch);

if (delta > 0.2) led_est_w = (led_est_w <= 0) ? delta : 0.7 * led_est_w + 0.3 * delta;

learn_pending = false;

}

bool over = demand_w > peak_limit_w;

bool safe = demand_w < peak_limit_w - hysteresis_w;

over_since = over ? (over_since ? over_since : now) : 0;

safe_since = safe ? (safe_since ? safe_since : now) : 0;

if (demand_w > peak_today_w) peak_today_w = demand_w;

long k = todayKey();

if (k && k != day_key) {

if (day_key) { energy_today_wh = 0; peak_today_w = 0; budget_warned = false; alarm_budget = false; }

day_key = k;

if (led_shed == SHED_BUDGET && (auto_mode || safe_mode)) switchLed(true, SHED_NONE);

}

bool managed = auto_mode || safe_mode;

if (budget_wh > 0) {

if (!budget_warned && energy_today_wh >= 0.8 * budget_wh) { budget_warned = true; publishEvent("BUDGET_WARN", "80% ngan sach ngay"); }

if (!alarm_budget && energy_today_wh >= budget_wh) { alarm_budget = true; publishEvent("BUDGET_EXCEEDED", "vuot ngan sach ngay"); }

}

if (managed && alarm_budget && led_on) {

switchLed(false, SHED_BUDGET);

publishEvent("SHED", "LED - vuot ngan sach ngay");

}

if (managed && led_on && over_since && now - over_since >= T_OVER_MS) {

switchLed(false, SHED_PEAK);

publishEvent("SHED", "LED - vuot nguong dinh");

} else if (managed && !led_on && led_shed == SHED_PEAK && !alarm_budget &&

safe_since && now - safe_since >= T_SAFE_MS &&

now - led_switch_ms >= MIN_OFF_MS &&

demand_w + led_est_w < peak_limit_w) {

switchLed(true, SHED_NONE);

publishEvent("RESTORE", "LED - dieu kien an toan on dinh");

}

bool should_alarm = over_since && now - over_since >= T_ALARM_MS && !led_on;

if (should_alarm && !alarm_over) { alarm_over = true; publishEvent("ALARM_OVER_LIMIT", "van vuot nguong sau khi sa thai"); }

if (!over && alarm_over) { alarm_over = false; publishEvent("ALARM_CLEAR", "cong suat da ve duoi nguong"); }

buzzer(alarm_over);

## 8.6. Command acknowledgement code

The device receives a command, applies it, then publishes an acknowledgement carrying the same command identifier and the actual state of both relays:

void onMqtt(char* topic, byte* payload, unsigned int len) {

StaticJsonDocument<512> in;

if (deserializeJson(in, (const char*)payload, len)) return;

char cmd_id[40] = "";

strlcpy(cmd_id, in["cmd_id"] | "", sizeof(cmd_id));

uint64_t t_cmd = in["ts"] | (uint64_t)0;

bool ok = true; String err = "";

if (in["fan"].is<bool>() || in["led"].is<bool>()) {

if (auto_mode) { auto_mode = false; publishEvent("MANUAL_OVERRIDE", "lenh tay -> chuyen MANUAL"); }

if (in["fan"].is<bool>()) { fan_on = in["fan"]; setRelay(PIN_RELAY_FAN, fan_on); }

if (in["led"].is<bool>()) switchLed(in["led"].as<bool>(), SHED_NONE);

}

if (in["auto_mode"].is<bool>()) auto_mode = in["auto_mode"];

if (!in["peak_limit_w"].isNull()) {

float v = in["peak_limit_w"]; if (v >= 0.5 && v <= 60) peak_limit_w = v; else { ok = false; err += "peak_limit_w ngoai [0.5,60]; "; }

}

if (!in["hysteresis_w"].isNull()) {

float v = in["hysteresis_w"]; if (v >= 0.1 && v <= 10) hysteresis_w = v; else { ok = false; err += "hysteresis_w ngoai [0.1,10]; "; }

}

if (!in["budget_wh"].isNull()) {

float v = in["budget_wh"]; if (v >= 0 && v <= 10000) { budget_wh = v; alarm_budget = false; budget_warned = false; }

else { ok = false; err += "budget_wh ngoai [0,10000]; "; }

}

if (in["reset_energy"] == true) { energy_today_wh = 0; peak_today_w = 0; alarm_budget = false; budget_warned = false; }

if (in["calibrate"] == true) {

if (fan_on || led_on) { ok = false; err += "tat ca 2 tai truoc khi calib; "; } else calibrateZero();

}

prefs.putFloat("limit", peak_limit_w); prefs.putFloat("hyst", hysteresis_w);

prefs.putFloat("budget", budget_wh); prefs.putBool("auto", auto_mode);

StaticJsonDocument<512> ack;

ack["cmd_id"] = cmd_id; ack["cmd_ts"] = t_cmd; ack["ok"] = ok;

if (!ok) ack["error"] = err;

fillState(ack);

publishJson(T_ACK, ack);

publishState();

Serial.printf("[CMD] id=%s ok=%d %s\n", cmd_id, ok, err.c_str());

# 9. SECURITY AND RELIABILITY

## 9.1. Behaviour during network loss

- Wi-Fi and MQTT reconnection never blocks the main loop; measurement and control keep running on their two-second cycle while reconnection is attempted.
- If the broker is unreachable for more than thirty seconds the device enters safe mode: local load management is activated even if the device was in manual mode.
- The DS3231 keeps time without Wi-Fi, so records created during an outage carry correct timestamps; when the network returns, NTP time is written back to the RTC every ten minutes.
- A 600-record circular buffer, about twenty minutes, stores data during an outage and forwards it at five packets per 200 ms on reconnection. Forwarded packets carry the buffered flag and the backend uses the device timestamp, so the history chart is not distorted.
- Reconnection emits a RECOVERED event carrying the outage duration and the number of forwarded packets, which is used as evidence in the experiments.
- Critical configuration is stored in flash, so thresholds and mode survive a power cycle.

## 9.2. Security

Threat | Impact | Current mitigation | Planned improvement
A stranger publishes on the cmd topic | Unauthorised load switching | Hard-to-guess topic name; every command is logged with its source | Authenticated broker with per-topic ACL
Telemetry eavesdropping | Usage patterns disclosed | No personal data in the messages | MQTT over TLS on port 8883
Arbitrary REST calls | Remote configuration changes | X-API-Key header required on every POST and PUT | Per-user authentication, separate view and control rights
Wi-Fi password exposed in source | Unauthorised access to the local network | Moved to secrets.h and excluded from Git | Provisioning through a first-boot access point
The assistant misreads an intent | Unintended switching | Manual confirmation required before any command is sent | Per-user audit log

Table 9.1. Risk analysis and mitigations

The main security limitation is the public broker without authentication. This was a conscious choice so that the system works under the network conditions available at the university, and the source is already prepared for a switch to an authenticated broker through configuration only.

# 10. EXPERIMENTAL METHOD

ID | Experiment | Procedure | Quantities collected
E1 | Measurement error | A reference ammeter in series; four cases: no load, fan, lamp, both; 30 samples each | Absolute and percentage error, standard deviation
E2 | Device to dashboard latency | Compare the packet timestamp with the display instant over 100 consecutive packets | Mean, 95th percentile, maximum
E3 | Command to acknowledgement latency | Thirty on/off operations, read from the interface and the commands table | Mean, 95th percentile, timeouts
E4 | Managed versus unmanaged operation | Two ten-minute runs with identical loads and limit, automatic mode off then on | Peak power, energy, time above limit, switching count
E5 | Anti-chattering | Set the limit close to the combined load; compare the full configuration against one without hysteresis and minimum time | Switching operations per ten minutes
E6 | Network loss and recovery | Disconnect the router for sixty seconds while above the limit | Offline detection instant, local behaviour, forwarded packets, residual data gap
E7 | Daily energy budget | Set a small quota and observe the warning and shedding behaviour | Time of the 80 % warning and of the quota breach
E8 | RTC drift | Compare DS3231 time against NTP after 24 hours | Seconds of drift per day

Table 10.1. Experiment matrix

Instrumentation: the interface displays latency and packet success rate directly; the /api/stats endpoint aggregates them over a window; CSV export allows the raw data to be reprocessed in a spreadsheet. Every figure in the results chapter comes from these three sources and none is entered by hand.

# 11. RESULTS AND DISCUSSION

The tables below are completed after running the experiments on the physical prototype.

## 11.1. Measurement error (E1)

Case | Reference (A) | System (A) | Error (A) | Error (%) | Std. dev. (A)
No load
Fan only
LED lamp only
Both loads

Table 11.1. Measurement error results

## 11.2. Latency (E2, E3)

Metric | Samples | Mean (ms) | 95th percentile (ms) | Maximum (ms)
Device → backend
Device → dashboard
Command → acknowledgement

Table 11.2. Latency results

## 11.3. Managed versus unmanaged operation (E4)

Metric over 10 minutes | Unmanaged | Managed | Difference
Peak power (W)
Energy consumed (Wh)
Time above limit (s)
Load switching operations
Packet success rate (%)

Table 11.3. Effectiveness of load management

## 11.4. Anti-chattering (E5) and network loss (E6)

Configuration | Switching operations / 10 min | Comment
All three conditions (H = 0.5 W, 15 s, 20 s, with prediction)
Single threshold, no hysteresis, no minimum time

Table 11.4. Effectiveness of the anti-chattering mechanism

Observation (E6) | Result
Offline detected after disconnection (s)
Local shedding behaviour during the outage
Records forwarded after recovery
Residual gap on the chart (s)
Time from reconnection to continuous data (s)

Table 11.5. Network loss experiment results

## 11.5. Discussion

The discussion should answer four questions: whether the measurement error is small enough relative to the control threshold; whether the end-to-end latency is compatible with the two-second control cycle; by what percentage load management reduces the time spent above the limit compared with unmanaged operation; and how the system behaves when the network is lost. If the measurement error exceeds roughly one tenth of the threshold, the voltage divider, the quality of the 5 V rail and the zero-point calibration should be reviewed.

# 12. DEVELOPMENT PROCESS AND DEFECTS RESOLVED

The system went through several rounds of debugging. This chapter records the defects with technical value, because they illustrate the characteristic traps of a multi-layer IoT system: a fault rarely sits in one place, it hides at the boundary between layers.

Defect | Symptom | Root cause | Resolution
Chart never plotted | Metric cards updated but the curve stayed flat at zero | chart.data.datasets.data written instead of datasets[0].data; the exception was swallowed by a try/catch block | Fixed the array index and moved to a time-based buffer
Current always zero | Loads were running but power read 0 W | A clamp forced negative values to zero, so a reversed IP+/IP− connection discarded the entire measurement | Take the absolute value of the voltage deviation
Zero point drift | Sensor read 2499 mV while the stored zero was 2530 mV | The reference level changed when the supply moved from USB to the LM2596 | Automatic zero tracking while both loads are off, time constant of twelve seconds
Protection stopped during outage | Load shedding ceased when the broker was unreachable | The reconnection routine used a blocking loop with delay, which stalled the control loop | Non-blocking reconnection; the control loop was decoupled from network tasks
Fundamentally wrong current computation | Readings biased high at small loads | An RMS formula applied to a DC signal adds noise in quadrature | Use the sample mean, which is correct for a DC load
Device and web never met | Both reported a successful broker connection yet no data appeared | The old topic tree used an underscore while the new one used a slash | A single topic tree, with the topic name printed to the serial port for comparison
Web deployment returned 404 | The deployed page would not open | The interface file lived in a subdirectory while the platform looked for it at the repository root | Moved the interface file to the repository root
Continuous switching | The auxiliary load cycled rapidly around the threshold | A single threshold; after restoration the limit was exceeded again immediately | Three simultaneous conditions: hysteresis, minimum time, predicted power after restoration

Table 12.1. Defects found and how they were resolved

The lesson is that in a distributed system a layer reporting success does not mean the system is working. The device reported a successful publish, the browser reported a successful connection, yet with two different topic names the data could never meet. The team therefore added observation points at every layer: the topic name printed to the serial port, the data freshness indicator on the interface, the backend status endpoint, and direct database queries.

# 13. LIMITATIONS

- The public MQTT broker has no authentication; anyone who knows the topic names can read the data and send commands.
- The supply voltage is assumed to be a constant 12 V rather than measured, so the accuracy of the power figure depends on the stability of the supply.
- The 5 A ACS712 has limited resolution for loads below about 0.3 A; an INA219 or INA226 would perform considerably better in that range.
- A single sensor measures the total current, so the power of an individual load is only an estimate derived from the step observed at switching.
- The PubSubClient library only publishes at QoS 0; command reliability relies on the application-level acknowledgement mechanism.
- The offline buffer lives in RAM and is lost on reset; it could be upgraded to LittleFS storage.
- The free tier of the hosting service suspends the instance without traffic, so a periodic keep-alive task is required and short data gaps remain possible.

# 14. CONCLUSION

The project delivers a complete IoT system for energy monitoring and intelligent load management, working end to end from the sensor to the web interface. It measures current and power with a documented calibration procedure, transmits data over MQTT with a structured topic hierarchy and availability detection, stores history in a time-series database with REST access, and provides a real-time dashboard that distinguishes requested state from confirmed state.

The most substantial technical contribution lies in control and reliability. The restoration mechanism based on three simultaneous conditions, including a prediction of the power after restoration, fully resolves the continuous switching that a single threshold cannot address. Decoupling the local control loop from network tasks, combined with a real-time clock and a store-and-forward buffer, preserves both the safety function and data integrity during a network outage.

Future work: migrate to an authenticated broker with TLS; replace the ACS712 with an INA226 to measure both voltage and current at higher resolution; extend the design to several measurement nodes with load coordination between them; and add short-term load forecasting so that shedding becomes anticipatory rather than reactive.

# 15. REFERENCES

[1] Allegro MicroSystems, "ACS712: Fully Integrated, Hall Effect-Based Linear Current Sensor IC", Datasheet, Rev. 18.

[2] Espressif Systems, "ESP32-S3 Technical Reference Manual", 2024.

[3] Espressif Systems, "ESP32-S3 Series Datasheet — ADC Characteristics and Calibration", 2024.

[4] Espressif Systems, "ESP32-S3-DevKitC-1 v1.1 User Guide", esp-dev-kits documentation.

[5] OASIS, "MQTT Version 5.0 — OASIS Standard", 2019.

[6] Analog Devices, "DS3231 Extremely Accurate I2C-Integrated RTC/TCXO/Crystal", Datasheet.

[7] Solomon Systech, "SSD1306 Advance Information — 128x64 Dot Matrix OLED/PLED Driver".

[8] S. Ramirez, "FastAPI Documentation", https://fastapi.tiangolo.com

[9] Eclipse Foundation, "Eclipse Paho MQTT Python Client Documentation".

[10] N. O'Leary, "PubSubClient — Arduino Client for MQTT", https://pubsubclient.knolleary.net

[11] B. Blanchon, "ArduinoJson Documentation", https://arduinojson.org

[12] K. Ogata, "Modern Control Engineering", 5th ed., Prentice Hall, 2010 (on-off control and hysteresis).

# 16. TEAM CONTRIBUTIONS

No. | Full name | Student ID | Responsibilities | Contribution
1 | Dang Dinh Manh | 24119055 | Circuit design, ESP32-S3 firmware, load management algorithm
2 | | | FastAPI backend, database, service deployment
3 | | | Web dashboard, data assistant, user interface
4 | | | Experiments, error and latency measurement, report writing

Table 16.1. Task allocation

Full source code: https://github.com/JackGamerCYT/IOT-PROJECT3-

# APPENDIX A. COMPLETE ESP32-S3 FIRMWARE SOURCE

File firmware/esp32_firmware/esp32_firmware.ino. Built with the Arduino IDE, board ESP32S3 Dev Module, two libraries: PubSubClient and ArduinoJson. Wi-Fi credentials live in a separate secrets.h file and are therefore absent from the public repository.

1 | /*

2 | * =====================================================================================

3 | * PROJECT 03 - SMART ENERGY MONITORING & INTELLIGENT LOAD MANAGEMENT

4 | * Firmware v21 - ESP32-S3 (N16R8)

5 | *

6 | * v19 thêm so với v17/v18:

7 | * - DS3231 (I2C): giữ giờ khi mất WiFi; NTP -> RTC khi online, RTC -> hệ thống khi offline

8 | * - SSD1306 OLED 128x64 (I2C): hiện giờ, công suất, điện năng, trạng thái tải, mạng

9 | * - Bộ đệm vòng 600 bản ghi (~20 phút): mất broker thì lưu lại, có mạng gửi bù

10 | * (gói gửi bù có "buffered":true, backend dùng ts thiết bị làm mốc thời gian)

11 | *

12 | * Thư viện cần cài (Library Manager):

13 | * PubSubClient · ArduinoJson · RTClib · Adafruit SSD1306 · Adafruit GFX Library

14 | * Không lắp module nào thì đặt USE_RTC / USE_OLED = 0, firmware vẫn chạy đầy đủ.

15 | * =====================================================================================

16 | */

17 |

18 | #define ARDUINOJSON_USE_LONG_LONG 1

19 |

20 | // ======================================================

21 | // CHUA GAN DS3231 / OLED thi de nguyen 0 (chi can 2 thu vien PubSubClient + ArduinoJson).

22 | // Khi nao gan module roi thi doi thanh 1 va cai them RTClib, Adafruit SSD1306, Adafruit GFX.

23 | // ======================================================

24 | #define USE_RTC 0

25 | #define USE_OLED 0

26 |

27 | #include <WiFi.h>

28 | #include <PubSubClient.h>

29 | #include <ArduinoJson.h>

30 | #include <Preferences.h>

31 | #include <time.h>

32 | #include <sys/time.h>

33 | #if USE_RTC || USE_OLED

34 | #include <Wire.h>

35 | #endif

36 | #if USE_RTC

37 | #include <RTClib.h>

38 | #endif

39 | #if USE_OLED

40 | #include <Adafruit_GFX.h>

41 | #include <Adafruit_SSD1306.h>

42 | #endif

43 |

44 | // -------------------------------------------------------------------------------------

45 | // 1. BÍ MẬT (tạo secrets.h cạnh file .ino, KHÔNG commit)

46 | // -------------------------------------------------------------------------------------

47 | #if __has_include("secrets.h")

48 | #include "secrets.h"

49 | #else

50 | #define WIFI_SSID "YOUR_WIFI"

51 | #define WIFI_PASSWORD "YOUR_PASSWORD"

52 | #define MQTT_USER ""

53 | #define MQTT_PASS ""

54 | #endif

55 |

56 | // -------------------------------------------------------------------------------------

57 | // 2. MQTT - cây topic: smartenergy/<device_id>/<kênh>

58 | // -------------------------------------------------------------------------------------

59 | const char* DEVICE_ID = "node9988";

60 | const char* MQTT_BROKER = "broker.hivemq.com";

61 | const int MQTT_PORT = 1883;

62 |

63 | const char* T_TELEMETRY = "smartenergy/node9988/telemetry";

64 | const char* T_STATUS = "smartenergy/node9988/status";

65 | const char* T_STATE = "smartenergy/node9988/state";

66 | const char* T_EVENT = "smartenergy/node9988/event";

67 | const char* T_CMD = "smartenergy/node9988/cmd";

68 | const char* T_ACK = "smartenergy/node9988/ack";

69 |

70 | // -------------------------------------------------------------------------------------

71 | // 3. PHẦN CỨNG

72 | // -------------------------------------------------------------------------------------

73 | const int PIN_ACS712 = 1; // ADC1_CH0, nên qua cầu phân áp 10k/20k

74 | const int PIN_RELAY_FAN = 12; // Tải 1 - Quạt 12V (ưu tiên CAO), relay active LOW

75 | const int PIN_RELAY_LED = 13; // Tải 2 - LED 12V (ưu tiên THẤP), relay active LOW

76 | const int PIN_BUZZER = 14; // -1 nếu không lắp

77 | const int PIN_I2C_SDA = 8; // DS3231 + SSD1306 dùng chung

78 | const int PIN_I2C_SCL = 9;

79 | const uint8_t ADDR_OLED = 0x3C;

80 |

81 | const float ACS_MV_PER_A = 185.0;

82 | const float DIVIDER_RATIO = 1.0; // 0.6667 nếu dùng phân áp 10k (trên) / 20k (dưới)

83 | const float V_NOMINAL = 12.0;

84 | const float I_DEADBAND_A = 0.04;

85 |

86 | // -------------------------------------------------------------------------------------

87 | // 4. THÔNG SỐ ĐO / ĐIỀU KHIỂN

88 | // -------------------------------------------------------------------------------------

89 | const unsigned long BLOCK_MS = 250;

90 | const int SAMPLES_PER_BLOCK = 64;

91 | const unsigned long TELEMETRY_MS = 2000;

92 | const unsigned long T_OVER_MS = 4000;

93 | const unsigned long T_SAFE_MS = 15000;

94 | const unsigned long MIN_OFF_MS = 20000;

95 | const unsigned long T_ALARM_MS = 10000;

96 | const unsigned long OFFLINE_SAFE_MS = 30000;

97 | const unsigned long SAVE_MS = 60000;

98 | const unsigned long OLED_MS = 500;

99 | const int BUF_SIZE = 600; // ~20 phút dữ liệu đệm

100 |

101 | float peak_limit_w = 3.0;

102 | float hysteresis_w = 0.5;

103 | float budget_wh = 0.0;

104 | bool auto_mode = false;

105 |

106 | // -------------------------------------------------------------------------------------

107 | // 5. BIẾN TRẠNG THÁI

108 | // -------------------------------------------------------------------------------------

109 | enum ShedReason { SHED_NONE = 0, SHED_PEAK, SHED_BUDGET };

110 | const char* shedName(int r) { return r == SHED_PEAK ? "PEAK" : r == SHED_BUDGET ? "BUDGET" : "NONE"; }

111 |

112 | bool fan_on = false, led_on = false;

113 | int led_shed = SHED_NONE;

114 | unsigned long led_switch_ms = 0;

115 |

116 | float zero_mv = 2500.0, last_mv = 0, diff_mv = 0;

117 | unsigned long zero_track_ms = 0;

118 | float current_a = 0, power_w = 0, demand_w = 0;

119 | double sum_block_p = 0; int n_block = 0;

120 | double energy_today_wh = 0, energy_total_wh = 0;

121 | float peak_today_w = 0;

122 | long day_key = 0;

123 |

124 | unsigned long over_since = 0, safe_since = 0;

125 | float led_est_w = 0, p_before_switch = -1;

126 | bool learn_pending = false;

127 | bool alarm_over = false, alarm_budget = false, budget_warned = false;

128 |

129 | bool safe_mode = false;

130 | unsigned long mqtt_lost_ms = 0;

131 | unsigned long last_block = 0, last_tele = 0, last_save = 0, last_mqtt_try = 0,

132 | last_wifi_try = 0, last_oled = 0, last_flush = 0;

133 | unsigned long seq = 0;

134 |

135 | // Bộ đệm vòng khi mất kết nối

136 | struct Rec { uint32_t ts; float i, p, e; uint8_t flags; };

137 | Rec buf[BUF_SIZE];

138 | int buf_head = 0, buf_count = 0;

139 |

140 | bool have_rtc = false, have_oled = false;

141 | const char* time_src = "none";

142 |

143 | WiFiClient net;

144 | PubSubClient mqtt(net);

145 | Preferences prefs;

146 | String client_id;

147 | #if USE_RTC

148 | RTC_DS3231 rtc;

149 | #endif

150 | #if USE_OLED

151 | Adafruit_SSD1306 oled(128, 64, &Wire, -1);

152 | #endif

153 |

154 | // -------------------------------------------------------------------------------------

155 | uint64_t epochMs() {

156 | struct timeval tv; gettimeofday(&tv, nullptr);

157 | if (tv.tv_sec < 1700000000) return 0;

158 | return (uint64_t)tv.tv_sec * 1000ULL + tv.tv_usec / 1000;

159 | }

160 | uint32_t epochS() { time_t t = time(nullptr); return t > 1700000000 ? (uint32_t)t : 0; }

161 |

162 | long todayKey() {

163 | time_t now = time(nullptr); if (now < 1700000000) return 0;

164 | struct tm t; localtime_r(&now, &t);

165 | return (t.tm_year + 1900) * 10000L + (t.tm_mon + 1) * 100L + t.tm_mday;

166 | }

167 | void clockStr(char* out, size_t n) {

168 | time_t now = time(nullptr);

169 | if (now < 1700000000) { snprintf(out, n, "--:--:--"); return; }

170 | struct tm t; localtime_r(&now, &t);

171 | snprintf(out, n, "%02d:%02d:%02d", t.tm_hour, t.tm_min, t.tm_sec);

172 | }

173 |

174 | const char* mqttErr(int rc) {

175 | switch (rc) {

176 | case -4: return "het thoi gian cho broker tra loi";

177 | case -3: return "mat ket noi mang";

178 | case -2: return "KHONG KET NOI DUOC TCP (mang chan cong 1883?)";

179 | case -1: return "broker tu choi / ngat ket noi";

180 | case 0: return "OK";

181 | case 1: return "broker khong ho tro phien ban MQTT";

182 | case 2: return "client_id bi tu choi";

183 | case 3: return "broker dang ban";

184 | case 4: return "sai user/password";

185 | case 5: return "khong duoc phep ket noi";

186 | default: return "khong ro";

187 | }

188 | }

189 |

190 | const char* wifiErr(int st) {

191 | switch (st) {

192 | case WL_NO_SSID_AVAIL: return "KHONG TIM THAY TEN WIFI (sai SSID?)";

193 | case WL_CONNECT_FAILED: return "SAI MAT KHAU WIFI";

194 | case WL_CONNECTION_LOST: return "mat song";

195 | case WL_DISCONNECTED: return "dang ket noi...";

196 | case WL_IDLE_STATUS: return "dang cho";

197 | case WL_CONNECTED: return "da ket noi";

198 | default: return "khong ro";

199 | }

200 | }

201 |

202 | void setRelay(int pin, bool on) { digitalWrite(pin, on ? LOW : HIGH); }

203 | void buzzer(bool on) { if (PIN_BUZZER >= 0) digitalWrite(PIN_BUZZER, on ? HIGH : LOW); }

204 |

205 | void publishJson(const char* topic, JsonDocument& doc, bool retained = false) {

206 | if (!mqtt.connected()) return;

207 | char b[768];

208 | size_t n = serializeJson(doc, b, sizeof(b));

209 | mqtt.publish(topic, (const uint8_t*)b, n, retained);

210 | }

211 |

212 | void publishEvent(const char* type, const char* detail) {

213 | Serial.printf("[EVENT] %s %s | P=%.2fW limit=%.2fW\n", type, detail, demand_w, peak_limit_w);

214 | StaticJsonDocument<384> d;

215 | d["dev"] = DEVICE_ID; d["ts"] = epochMs(); d["type"] = type; d["detail"] = detail;

216 | d["power_w"] = demand_w; d["limit_w"] = peak_limit_w; d["energy_today_wh"] = energy_today_wh;

217 | publishJson(T_EVENT, d);

218 | }

219 |

220 | void fillState(JsonDocument& d) {

221 | d["dev"] = DEVICE_ID; d["ts"] = epochMs();

222 | d["fan"] = fan_on; d["led"] = led_on; d["led_shed"] = shedName(led_shed);

223 | d["auto_mode"] = auto_mode; d["safe_mode"] = safe_mode;

224 | d["peak_limit_w"] = peak_limit_w; d["hysteresis_w"] = hysteresis_w; d["budget_wh"] = budget_wh;

225 | }

226 | void publishState() { StaticJsonDocument<384> d; fillState(d); publishJson(T_STATE, d, true); }

227 |

228 | void switchLed(bool on, int reason) {

229 | if (on == led_on) { led_shed = on ? SHED_NONE : reason; return; }

230 | p_before_switch = demand_w; learn_pending = true;

231 | led_on = on; led_shed = on ? SHED_NONE : reason; led_switch_ms = millis();

232 | setRelay(PIN_RELAY_LED, on);

233 | publishState();

234 | }

235 |

236 | // -------------------------------------------------------------------------------------

237 | // 6. ĐỒNG HỒ THỜI GIAN THỰC

238 | // -------------------------------------------------------------------------------------

239 | void initRTC() {

240 | #if USE_RTC

241 | if (!rtc.begin(&Wire)) { Serial.println("[RTC] khong tim thay DS3231"); return; }

242 | have_rtc = true;

243 | if (rtc.lostPower()) Serial.println("[RTC] mat nguon, gio chua dung - se chinh lai khi co NTP");

244 | DateTime n = rtc.now();

245 | if (n.unixtime() > 1700000000) { // lấy giờ RTC làm giờ hệ thống ngay khi khởi động

246 | struct timeval tv; tv.tv_sec = (time_t)n.unixtime(); tv.tv_usec = 0;

247 | settimeofday(&tv, nullptr);

248 | time_src = "rtc";

249 | Serial.printf("[RTC] gio tu DS3231: %04d-%02d-%02d %02d:%02d:%02d\n",

250 | n.year(), n.month(), n.day(), n.hour(), n.minute(), n.second());

251 | }

252 | #endif

253 | }

254 |

255 | void syncRtcFromNtp() {

256 | #if USE_RTC

257 | if (!have_rtc) return;

258 | uint32_t s = epochS();

259 | if (!s) return;

260 | DateTime cur = rtc.now();

261 | long diff = (long)cur.unixtime() - (long)s;

262 | if (diff > 2 || diff < -2) { // lệch quá 2 s mới ghi lại

263 | rtc.adjust(DateTime(s));

264 | Serial.println("[RTC] da dong bo DS3231 theo NTP");

265 | }

266 | #endif

267 | }

268 |

269 | // -------------------------------------------------------------------------------------

270 | // 7. OLED

271 | // -------------------------------------------------------------------------------------

272 | void initOLED() {

273 | #if USE_OLED

274 | if (!oled.begin(SSD1306_SWITCHCAPVCC, ADDR_OLED)) { Serial.println("[OLED] khong tim thay SSD1306"); return; }

275 | have_oled = true;

276 | oled.clearDisplay(); oled.setTextColor(SSD1306_WHITE); oled.setTextSize(1);

277 | oled.setCursor(0, 24); oled.println(" SMART ENERGY v19"); oled.display();

278 | #endif

279 | }

280 |

281 | void drawOLED() {

282 | #if USE_OLED

283 | if (!have_oled) return;

284 | char t[16]; clockStr(t, sizeof(t));

285 | oled.clearDisplay();

286 |

287 | oled.setTextSize(1); oled.setCursor(0, 0); oled.print(t);

288 | oled.setCursor(70, 0);

289 | oled.print(WiFi.status() == WL_CONNECTED ? "W" : "-");

290 | oled.print(mqtt.connected() ? "M" : "-");

291 | if (buf_count) { oled.print(" B"); oled.print(buf_count); }

292 | else { oled.print(auto_mode ? " AUT" : " MAN"); }

293 |

294 | oled.drawFastHLine(0, 10, 128, SSD1306_WHITE);

295 |

296 | oled.setTextSize(2); oled.setCursor(0, 15);

297 | oled.print(demand_w, 2); oled.setTextSize(1); oled.print(" W");

298 |

299 | oled.setCursor(0, 34);

300 | oled.print(current_a, 3); oled.print("A ");

301 | oled.print(energy_today_wh, 2); oled.print("Wh");

302 |

303 | oled.setCursor(0, 45);

304 | oled.print("Lim "); oled.print(peak_limit_w, 1); oled.print("W");

305 | if (alarm_over) oled.print(" !OVER");

306 | else if (alarm_budget) oled.print(" !BUDG");

307 | else if (safe_mode) oled.print(" SAFE");

308 |

309 | oled.setCursor(0, 56);

310 | oled.print("FAN:"); oled.print(fan_on ? "ON " : "OFF");

311 | oled.print(" LED:"); oled.print(led_on ? "ON" : "OFF");

312 | if (!led_on && led_shed != SHED_NONE) { oled.print("/"); oled.print(shedName(led_shed)); }

313 | oled.display();

314 | #endif

315 | }

316 |

317 | // -------------------------------------------------------------------------------------

318 | // 8. ĐO LƯỜNG

319 | // -------------------------------------------------------------------------------------

320 | float readMvAvg(int n) {

321 | uint32_t s = 0;

322 | for (int i = 0; i < n; i++) s += analogReadMilliVolts(PIN_ACS712);

323 | return (float)s / n / DIVIDER_RATIO;

324 | }

325 |

326 | void calibrateZero() {

327 | float s = 0;

328 | for (int i = 0; i < 20; i++) { s += readMvAvg(50); delay(10); }

329 | zero_mv = s / 20.0;

330 | Serial.printf("[CAL] zero = %.1f mV (ly thuyet ~2500 mV khi VCC = 5.0 V)\n", zero_mv);

331 | }

332 |

333 | void measureBlock() {

334 | unsigned long now = millis();

335 | float dt_h = (last_block ? (now - last_block) : BLOCK_MS) / 3600000.0;

336 | last_block = now;

337 |

338 | last_mv = readMvAvg(SAMPLES_PER_BLOCK);

339 | diff_mv = last_mv - zero_mv;

340 |

341 | // TRỊ TUYỆT ĐỐI: tải một chiều, nếu lỡ đấu ngược IP+/IP- thì vẫn đo đúng độ lớn

342 | float i = fabs(diff_mv) / ACS_MV_PER_A;

343 | if (i < I_DEADBAND_A) i = 0;

344 | current_a = i;

345 | power_w = V_NOMINAL * current_a;

346 |

347 | // TỰ HIỆU CHỈNH ĐIỂM 0: khi cả 2 tải đang TẮT, kéo zero_mv bám theo mức thực tế

348 | // (bù trôi do đổi nguồn USB <-> LM2596, do nhiệt độ). Hằng số thời gian ~12 giây.

349 | if (!fan_on && !led_on) {

350 | if (!zero_track_ms) zero_track_ms = now;

351 | if (now - zero_track_ms > 3000 && fabs(diff_mv) < 400)

352 | zero_mv += (last_mv - zero_mv) * 0.02f;

353 | } else {

354 | zero_track_ms = 0;

355 | }

356 |

357 | energy_today_wh += power_w * dt_h;

358 | energy_total_wh += power_w * dt_h;

359 | sum_block_p += power_w; n_block++;

360 | }

361 |

362 | // -------------------------------------------------------------------------------------

363 | // 9. MÁY TRẠNG THÁI QUẢN LÝ TẢI (chạy cả khi mất mạng)

364 | // -------------------------------------------------------------------------------------

365 | void controlStep() {

366 | unsigned long now = millis();

367 |

368 | if (learn_pending && now - led_switch_ms >= TELEMETRY_MS) {

369 | float delta = fabs(demand_w - p_before_switch);

370 | if (delta > 0.2) led_est_w = (led_est_w <= 0) ? delta : 0.7 * led_est_w + 0.3 * delta;

371 | learn_pending = false;

372 | }

373 |

374 | bool over = demand_w > peak_limit_w;

375 | bool safe = demand_w < peak_limit_w - hysteresis_w;

376 | over_since = over ? (over_since ? over_since : now) : 0;

377 | safe_since = safe ? (safe_since ? safe_since : now) : 0;

378 | if (demand_w > peak_today_w) peak_today_w = demand_w;

379 |

380 | long k = todayKey();

381 | if (k && k != day_key) {

382 | if (day_key) { energy_today_wh = 0; peak_today_w = 0; budget_warned = false; alarm_budget = false; }

383 | day_key = k;

384 | if (led_shed == SHED_BUDGET && (auto_mode || safe_mode)) switchLed(true, SHED_NONE);

385 | }

386 |

387 | bool managed = auto_mode || safe_mode;

388 |

389 | if (budget_wh > 0) {

390 | if (!budget_warned && energy_today_wh >= 0.8 * budget_wh) { budget_warned = true; publishEvent("BUDGET_WARN", "80% ngan sach ngay"); }

391 | if (!alarm_budget && energy_today_wh >= budget_wh) { alarm_budget = true; publishEvent("BUDGET_EXCEEDED", "vuot ngan sach ngay"); }

392 | }

393 | if (managed && alarm_budget && led_on) {

394 | switchLed(false, SHED_BUDGET);

395 | publishEvent("SHED", "LED - vuot ngan sach ngay");

396 | }

397 |

398 | if (managed && led_on && over_since && now - over_since >= T_OVER_MS) {

399 | switchLed(false, SHED_PEAK);

400 | publishEvent("SHED", "LED - vuot nguong dinh");

401 | } else if (managed && !led_on && led_shed == SHED_PEAK && !alarm_budget &&

402 | safe_since && now - safe_since >= T_SAFE_MS &&

403 | now - led_switch_ms >= MIN_OFF_MS &&

404 | demand_w + led_est_w < peak_limit_w) {

405 | switchLed(true, SHED_NONE);

406 | publishEvent("RESTORE", "LED - dieu kien an toan on dinh");

407 | }

408 |

409 | bool should_alarm = over_since && now - over_since >= T_ALARM_MS && !led_on;

410 | if (should_alarm && !alarm_over) { alarm_over = true; publishEvent("ALARM_OVER_LIMIT", "van vuot nguong sau khi sa thai"); }

411 | if (!over && alarm_over) { alarm_over = false; publishEvent("ALARM_CLEAR", "cong suat da ve duoi nguong"); }

412 | buzzer(alarm_over);

413 | }

414 |

415 | // -------------------------------------------------------------------------------------

416 | // 10. TELEMETRY + BỘ ĐỆM OFFLINE

417 | // -------------------------------------------------------------------------------------

418 | void bufferPush() {

419 | uint32_t ts = epochS();

420 | if (!ts) return; // không có mốc thời gian đáng tin thì không đệm

421 | buf[buf_head] = { ts, current_a, demand_w, (float)energy_today_wh,

422 | (uint8_t)((fan_on ? 1 : 0) | (led_on ? 2 : 0) | (auto_mode ? 4 : 0) | (safe_mode ? 8 : 0)) };

423 | buf_head = (buf_head + 1) % BUF_SIZE;

424 | if (buf_count < BUF_SIZE) buf_count++;

425 | }

426 |

427 | void bufferFlush(int max_msgs) {

428 | while (buf_count > 0 && max_msgs-- > 0 && mqtt.connected()) {

429 | int idx = (buf_head - buf_count + BUF_SIZE) % BUF_SIZE;

430 | Rec& r = buf[idx];

431 | StaticJsonDocument<384> d;

432 | d["dev"] = DEVICE_ID; d["ts"] = (uint64_t)r.ts * 1000ULL; d["buffered"] = true;

433 | d["current_a"] = serialized(String(r.i, 3));

434 | d["power_w"] = serialized(String(r.p, 3));

435 | d["energy_today_wh"] = serialized(String(r.e, 4));

436 | d["fan"] = (bool)(r.flags & 1); d["led"] = (bool)(r.flags & 2);

437 | d["auto_mode"] = (bool)(r.flags & 4); d["safe_mode"] = (bool)(r.flags & 8);

438 | d["peak_limit_w"] = peak_limit_w;

439 | publishJson(T_TELEMETRY, d);

440 | buf_count--;

441 | }

442 | }

443 |

444 | void publishTelemetry() {

445 | seq++;

446 | StaticJsonDocument<768> d;

447 | d["dev"] = DEVICE_ID; d["ts"] = epochMs(); d["seq"] = seq;

448 | d["current_a"] = serialized(String(current_a, 3));

449 | d["power_w"] = serialized(String(demand_w, 3));

450 | d["energy_today_wh"] = serialized(String(energy_today_wh, 4));

451 | d["energy_total_wh"] = serialized(String(energy_total_wh, 3));

452 | d["peak_today_w"] = serialized(String(peak_today_w, 3));

453 | d["fan"] = fan_on; d["led"] = led_on; d["led_shed"] = shedName(led_shed);

454 | d["auto_mode"] = auto_mode; d["safe_mode"] = safe_mode;

455 | d["peak_limit_w"] = peak_limit_w; d["hysteresis_w"] = hysteresis_w; d["budget_wh"] = budget_wh;

456 | d["led_est_w"] = serialized(String(led_est_w, 2));

457 | d["alarm_over"] = alarm_over; d["alarm_budget"] = alarm_budget;

458 | d["sensor_mv"] = serialized(String(last_mv, 1)); d["zero_mv"] = serialized(String(zero_mv, 1));

459 | d["diff_mv"] = serialized(String(diff_mv, 1));

460 | d["rssi"] = WiFi.RSSI(); d["uptime_s"] = millis() / 1000;

461 | d["time_src"] = time_src; d["rtc"] = have_rtc; d["buffered_count"] = buf_count;

462 | bool sent = mqtt.connected();

463 | publishJson(T_TELEMETRY, d);

464 |

465 | char t[16]; clockStr(t, sizeof(t));

466 | Serial.printf("[#%lu %s] %.1fmV (lech %+.1fmV) I=%.3fA P=%.2fW E=%.3fWh | FAN:%s LED:%s(%s) | %s%s | MQTT:%s buf=%d\n",

467 | seq, t, last_mv, diff_mv, current_a, demand_w, energy_today_wh, fan_on ? "ON" : "OFF", led_on ? "ON" : "OFF",

468 | shedName(led_shed), auto_mode ? "AUTO" : "MANUAL", safe_mode ? " SAFE" : "",

469 | sent ? "DA GUI" : "CHUA GUI", buf_count);

470 | }

471 |

472 | // -------------------------------------------------------------------------------------

473 | // 11. XỬ LÝ LỆNH

474 | // -------------------------------------------------------------------------------------

475 | void onMqtt(char* topic, byte* payload, unsigned int len) {

476 | StaticJsonDocument<512> in;

477 | if (deserializeJson(in, (const char*)payload, len)) return;

478 |

479 | char cmd_id[40] = "";

480 | strlcpy(cmd_id, in["cmd_id"] | "", sizeof(cmd_id));

481 | uint64_t t_cmd = in["ts"] | (uint64_t)0;

482 | bool ok = true; String err = "";

483 |

484 | if (in["fan"].is<bool>() || in["led"].is<bool>()) {

485 | if (auto_mode) { auto_mode = false; publishEvent("MANUAL_OVERRIDE", "lenh tay -> chuyen MANUAL"); }

486 | if (in["fan"].is<bool>()) { fan_on = in["fan"]; setRelay(PIN_RELAY_FAN, fan_on); }

487 | if (in["led"].is<bool>()) switchLed(in["led"].as<bool>(), SHED_NONE);

488 | }

489 | if (in["auto_mode"].is<bool>()) auto_mode = in["auto_mode"];

490 | if (!in["peak_limit_w"].isNull()) {

491 | float v = in["peak_limit_w"]; if (v >= 0.5 && v <= 60) peak_limit_w = v; else { ok = false; err += "peak_limit_w ngoai [0.5,60]; "; }

492 | }

493 | if (!in["hysteresis_w"].isNull()) {

494 | float v = in["hysteresis_w"]; if (v >= 0.1 && v <= 10) hysteresis_w = v; else { ok = false; err += "hysteresis_w ngoai [0.1,10]; "; }

495 | }

496 | if (!in["budget_wh"].isNull()) {

497 | float v = in["budget_wh"]; if (v >= 0 && v <= 10000) { budget_wh = v; alarm_budget = false; budget_warned = false; }

498 | else { ok = false; err += "budget_wh ngoai [0,10000]; "; }

499 | }

500 | if (in["reset_energy"] == true) { energy_today_wh = 0; peak_today_w = 0; alarm_budget = false; budget_warned = false; }

501 | if (in["calibrate"] == true) {

502 | if (fan_on || led_on) { ok = false; err += "tat ca 2 tai truoc khi calib; "; } else calibrateZero();

503 | }

504 |

505 | prefs.putFloat("limit", peak_limit_w); prefs.putFloat("hyst", hysteresis_w);

506 | prefs.putFloat("budget", budget_wh); prefs.putBool("auto", auto_mode);

507 |

508 | StaticJsonDocument<512> ack;

509 | ack["cmd_id"] = cmd_id; ack["cmd_ts"] = t_cmd; ack["ok"] = ok;

510 | if (!ok) ack["error"] = err;

511 | fillState(ack);

512 | publishJson(T_ACK, ack);

513 | publishState();

514 | Serial.printf("[CMD] id=%s ok=%d %s\n", cmd_id, ok, err.c_str());

515 | }

516 |

517 | // -------------------------------------------------------------------------------------

518 | // 12. MẠNG (không chặn)

519 | // -------------------------------------------------------------------------------------

520 | void networkTask() {

521 | unsigned long now = millis();

522 |

523 | static unsigned long last_diag = 0;

524 | if (!mqtt.connected() && now - last_diag > 5000) { // nhac trang thai moi 5 giay

525 | last_diag = now;

526 | if (WiFi.status() != WL_CONNECTED)

527 | Serial.printf("[CHAN DOAN] WiFi \"%s\": %s (ma %d)\n", WIFI_SSID,

528 | wifiErr(WiFi.status()), WiFi.status());

529 | else

530 | Serial.printf("[CHAN DOAN] WiFi OK, IP %s, RSSI %d dBm | MQTT chua noi duoc %s:%d\n",

531 | WiFi.localIP().toString().c_str(), WiFi.RSSI(), MQTT_BROKER, MQTT_PORT);

532 | }

533 |

534 | if (WiFi.status() != WL_CONNECTED) {

535 | if (now - last_wifi_try > 15000) {

536 | last_wifi_try = now; WiFi.disconnect(); WiFi.begin(WIFI_SSID, WIFI_PASSWORD);

537 | Serial.println("[NET] Thu ket noi WiFi lai...");

538 | }

539 | } else if (!mqtt.connected()) {

540 | if (now - last_mqtt_try > 5000) {

541 | last_mqtt_try = now;

542 | bool auth = strlen(MQTT_USER) > 0;

543 | bool c = mqtt.connect(client_id.c_str(), auth ? MQTT_USER : nullptr, auth ? MQTT_PASS : nullptr,

544 | T_STATUS, 1, true, "offline");

545 | if (c) {

546 | mqtt.publish(T_STATUS, "online", true);

547 | mqtt.subscribe(T_CMD, 1);

548 | if (safe_mode) {

549 | char b[80];

550 | snprintf(b, sizeof(b), "mat ket noi %lus, gui bu %d goi", (now - mqtt_lost_ms) / 1000, buf_count);

551 | safe_mode = false; publishEvent("RECOVERED", b);

552 | }

553 | mqtt_lost_ms = 0;

554 | publishState();

555 | Serial.printf("[NET] >>> MQTT DA KET NOI. Publish len: %s <<<\n", T_TELEMETRY);

556 | } else {

557 | Serial.printf("[NET] MQTT loi rc=%d (%s)\n", mqtt.state(), mqttErr(mqtt.state()));

558 | }

559 | }

560 | }

561 |

562 | if (mqtt.connected()) {

563 | mqtt.loop();

564 | if (buf_count && now - last_flush > 200) { last_flush = now; bufferFlush(5); } // gửi bù từ từ

565 | } else {

566 | if (!mqtt_lost_ms) mqtt_lost_ms = now ? now : 1;

567 | if (!safe_mode && now - mqtt_lost_ms > OFFLINE_SAFE_MS) {

568 | safe_mode = true;

569 | Serial.println("[SAFE] Mat broker > 30s -> quan ly tai cuc bo, bat dau dem du lieu");

570 | }

571 | }

572 |

573 | // NTP -> RTC mỗi 10 phút khi online

574 | static unsigned long last_sync = 0;

575 | if (WiFi.status() == WL_CONNECTED && epochS() && (!last_sync || now - last_sync > 600000)) {

576 | last_sync = now; time_src = "ntp"; syncRtcFromNtp();

577 | }

578 | }

579 |

580 | // -------------------------------------------------------------------------------------

581 | void setup() {

582 | Serial.begin(115200);

583 | delay(500);

584 | pinMode(PIN_RELAY_FAN, OUTPUT); setRelay(PIN_RELAY_FAN, false);

585 | pinMode(PIN_RELAY_LED, OUTPUT); setRelay(PIN_RELAY_LED, false);

586 | if (PIN_BUZZER >= 0) { pinMode(PIN_BUZZER, OUTPUT); buzzer(false); }

587 |

588 | analogReadResolution(12);

589 | analogSetPinAttenuation(PIN_ACS712, ADC_11db);

590 |

591 | #if USE_RTC || USE_OLED

592 | Wire.begin(PIN_I2C_SDA, PIN_I2C_SCL);

593 | Wire.setClock(400000);

594 | initRTC();

595 | initOLED();

596 | #endif

597 |

598 | prefs.begin("energy", false);

599 | peak_limit_w = prefs.getFloat("limit", peak_limit_w);

600 | hysteresis_w = prefs.getFloat("hyst", hysteresis_w);

601 | budget_wh = prefs.getFloat("budget", budget_wh);

602 | auto_mode = prefs.getBool("auto", auto_mode);

603 | energy_today_wh = prefs.getDouble("e_today", 0);

604 | energy_total_wh = prefs.getDouble("e_total", 0);

605 | day_key = prefs.getLong("day", 0);

606 |

607 | Serial.println("\n==========================================================");

608 | Serial.println(" SMART ENERGY v21 - IoT PROJECT 03");

609 | Serial.printf(" Device ID : %s\n", DEVICE_ID);

610 | Serial.printf(" Broker : %s:%d\n", MQTT_BROKER, MQTT_PORT);

611 | Serial.printf(" Telemetry : %s\n", T_TELEMETRY);

612 | Serial.printf(" Status : %s\n", T_STATUS);

613 | Serial.printf(" Lenh : %s\n", T_CMD);

614 | Serial.printf(" WiFi SSID : %s\n", WIFI_SSID);

615 | Serial.printf(" RTC: %s | OLED: %s\n", USE_RTC ? "BAT" : "TAT", USE_OLED ? "BAT" : "TAT");

616 | Serial.println(" Topic tren web PHAI trung voi dong Telemetry o tren!");

617 | Serial.println("==========================================================");

618 | Serial.println("Giu 2 tai TAT trong 1 giay de calib diem 0...");

619 | calibrateZero();

620 |

621 | uint64_t mac = ESP.getEfuseMac();

622 | client_id = String("SE_") + DEVICE_ID + "_" + String((uint32_t)(mac & 0xFFFFFFFF), HEX);

623 |

624 | WiFi.mode(WIFI_STA);

625 | WiFi.setAutoReconnect(true);

626 | WiFi.begin(WIFI_SSID, WIFI_PASSWORD);

627 | last_wifi_try = millis();

628 | configTime(7 * 3600, 0, "pool.ntp.org", "time.google.com");

629 |

630 | mqtt.setServer(MQTT_BROKER, MQTT_PORT);

631 | mqtt.setBufferSize(1024);

632 | mqtt.setKeepAlive(15);

633 | mqtt.setSocketTimeout(3);

634 | mqtt.setCallback(onMqtt);

635 | }

636 |

637 | void loop() {

638 | unsigned long now = millis();

639 |

640 | if (now - last_block >= BLOCK_MS) measureBlock();

641 |

642 | if (now - last_tele >= TELEMETRY_MS) {

643 | last_tele = now;

644 | demand_w = n_block ? sum_block_p / n_block : 0;

645 | sum_block_p = 0; n_block = 0;

646 | controlStep(); // điều khiển cục bộ trước

647 | if (mqtt.connected()) publishTelemetry();

648 | else bufferPush(); // mất mạng: đệm lại để gửi bù

649 | }

650 |

651 | if (now - last_oled >= OLED_MS) { last_oled = now; drawOLED(); }

652 |

653 | if (now - last_save >= SAVE_MS) {

654 | last_save = now;

655 | prefs.putDouble("e_today", energy_today_wh);

656 | prefs.putDouble("e_total", energy_total_wh);

657 | prefs.putLong("day", day_key);

658 | }

659 |

660 | networkTask();

661 | }

662 |
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

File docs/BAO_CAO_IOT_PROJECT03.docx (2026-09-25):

TRƯỜNG ĐẠI HỌC SƯ PHẠM KỸ THUẬT TP. HỒ CHÍ MINH

KHOA ĐIỆN – ĐIỆN TỬ

BÁO CÁO ĐỒ ÁN CUỐI KỲ

MÔN: IOT FOUNDATIONS AND APPLICATIONS

ĐỀ TÀI 03: GIÁM SÁT ĐIỆN NĂNG VÀ QUẢN LÝ TẢI THÔNG MINH

(Smart Energy Monitoring and Intelligent Load Management)

Nhóm sinh viên thực hiện:

Đặng Đình Mạnh – 24119055

……………………… – …………

……………………… – …………

……………………… – …………

Giảng viên hướng dẫn: ………………………

TP. Hồ Chí Minh, tháng 9 năm 2026

# MỤC LỤC

(Mở file trong Word, bấm chuột phải vào mục lục → Update Field → Update entire table để sinh số trang.)

# 1. GIỚI THIỆU VÀ BÀI TOÁN

Nhu cầu điện của hộ gia đình và phòng thí nghiệm nhỏ thường vượt ngưỡng an toàn trong những khoảng ngắn, khi nhiều thiết bị cùng hoạt động. Hệ quả là nhảy aptomat, hao phí điện năng và rút ngắn tuổi thọ dây dẫn. Người dùng lại hiếm khi biết chính xác mình đang tiêu thụ bao nhiêu, vào lúc nào, và thiết bị nào nên được cắt trước khi vượt ngưỡng.

Đồ án xây dựng một hệ thống IoT hoàn chỉnh giải quyết bài toán trên ở quy mô mô hình an toàn: đo dòng điện và công suất của hai tải một chiều 12 V theo thời gian thực, lưu lịch sử vào cơ sở dữ liệu chuỗi thời gian, hiển thị trên giao diện web, tự động sa thải tải ưu tiên thấp khi công suất vượt ngưỡng đỉnh và khôi phục khi điều kiện đã an toàn ổn định.

Mục tiêu cụ thể:

- Đo dòng và công suất với sai số được định lượng, không chấp nhận giá trị ADC thô làm kết quả cuối.
- Truyền số liệu bằng MQTT với cây topic có cấu trúc, phát hiện thiết bị online/offline bằng cơ chế Last Will and Testament.
- Lưu trữ chuỗi thời gian và cung cấp REST API cho lịch sử, cấu hình và thống kê.
- Quản lý tải theo mức ưu tiên, có cơ chế chống đóng cắt liên tục và vẫn hoạt động khi mất kết nối mạng.
- Cung cấp dashboard thời gian thực, phân biệt rõ trạng thái được yêu cầu và trạng thái đã được thiết bị xác nhận.
- Bổ sung thành phần nâng cao: phát hiện đỉnh công suất và ngân sách điện năng theo ngày.

Phạm vi: toàn bộ mạch động lực làm việc ở 12 VDC, không có phần nào tiếp xúc điện lưới, phù hợp yêu cầu an toàn của đề bài.

# 2. YÊU CẦU VÀ CƠ SỞ LÝ THUYẾT

## 2.1. Bảng đối chiếu yêu cầu

Yêu cầu của đề | Giải pháp trong đồ án
Đo dòng/điện năng cách ly, điện áp thấp | Cảm biến Hall ACS712-05B, tải DC 12 V
Ít nhất hai tải điều khiển được | Quạt 12 V (ưu tiên cao) và đèn LED 12 V (ưu tiên thấp)
MQTT có cấu trúc topic, QoS, trạng thái sẵn sàng | Sáu topic dưới smartenergy/node9988, LWT retained
CSDL chuỗi thời gian và REST API | SQLite hoặc PostgreSQL, năm bảng, mười hai endpoint
Dashboard đầy đủ chỉ số và cảnh báo | Giao diện web thời gian thực, biểu đồ, nhật ký sự kiện
Quản lý tải theo ưu tiên, chống đóng cắt liên tục | Máy trạng thái với trễ, thời gian tối thiểu và dự báo công suất
Phân biệt lệnh yêu cầu và trạng thái xác nhận | Cơ chế cmd_id và bản tin ack
Thành phần nâng cao | Phát hiện đỉnh công suất và ngân sách điện năng ngày
Hành vi an toàn khi mất mạng | Chế độ an toàn cục bộ, RTC giữ giờ, bộ đệm gửi bù

Bảng 2.1. Đối chiếu yêu cầu đề bài và giải pháp

## 2.2. Nguyên lý cảm biến dòng hiệu ứng Hall

ACS712 dẫn dòng tải qua một đường dẫn đồng tích hợp. Từ trường sinh ra tỉ lệ với dòng điện được cảm nhận bởi phần tử Hall và chuyển thành điện áp ra. Bản 5 A có độ nhạy 185 mV/A và điện áp ra ở 0 A bằng một nửa điện áp nguồn, tức 2.5 V khi cấp 5 V. Đường dẫn dòng cách ly về điện với mạch tín hiệu, điện áp chịu đựng danh định 2.1 kV, đây là lý do cảm biến này phù hợp với yêu cầu "isolated measurement" của đề.

Dòng điện được suy ra theo công thức:

I [A] = (V_out − V_zero) / 0.185

V_out : điện áp tại chân OUT (V)

V_zero: điện áp ra khi dòng bằng 0, xác định bằng hiệu chuẩn

Vì tải là một chiều, giá trị trung bình của nhiều mẫu phản ánh đúng dòng tải; không cần tính hiệu dụng RMS như với tải xoay chiều. Trái lại, nếu áp dụng công thức RMS cho tín hiệu một chiều có nhiễu, nhiễu sẽ cộng theo bình phương và làm kết quả cao hơn giá trị thật, đây là lỗi đã được phát hiện và sửa trong quá trình thực hiện đồ án.

## 2.3. Công suất và điện năng

P [W] = U × I (U = 12 V, coi là hằng số)

E [Wh] = Σ P × Δt / 3600

Chi phí [đ] = E/1000 × đơn giá [đ/kWh]

Backend tính lại điện năng bằng tích phân hình thang trên chuỗi telemetry để đối chiếu với giá trị tích lũy trên thiết bị; khoảng mất dữ liệu dài hơn 10 giây không được tính vào tích phân nhằm tránh suy diễn sai khi mất kết nối.

## 2.4. Lý thuyết điều khiển có trễ và chống đóng cắt liên tục

Một bộ điều khiển chỉ dùng một ngưỡng duy nhất sẽ dao động liên tục khi đại lượng đo nằm quanh ngưỡng đó. Cách khắc phục kinh điển là thêm dải trễ (hysteresis): cắt tải khi P > P_peak nhưng chỉ khôi phục khi P < P_peak − H. Với hệ thống này, riêng dải trễ vẫn chưa đủ, vì bản thân việc khôi phục tải làm công suất tăng trở lại và có thể vượt ngưỡng ngay lập tức. Đồ án vì vậy áp dụng đồng thời ba điều kiện: dải trễ theo công suất, thời gian duy trì tối thiểu theo thời gian, và một bước dự báo công suất sau khi khôi phục.

## 2.5. Giao thức MQTT

MQTT là giao thức publish/subscribe chạy trên TCP, phù hợp cho thiết bị nhúng nhờ gói tin nhỏ và kết nối duy trì lâu dài. Ba mức chất lượng dịch vụ: QoS 0 gửi tối đa một lần, QoS 1 bảo đảm ít nhất một lần, QoS 2 bảo đảm đúng một lần. Cơ chế Last Will and Testament cho phép broker tự công bố một bản tin định trước khi mất kết nối với thiết bị, nhờ đó phát hiện được sự cố mà không cần thăm dò định kỳ. Cờ retained giúp một client vừa đăng ký nhận ngay bản tin gần nhất của topic.

# 3. KIẾN TRÚC HỆ THỐNG

[Adapter 12V]-[cầu chì 2A]-+-[LM2596 -> 5V]-> ESP32-S3, ACS712,

| relay, OLED, DS3231

+-[ACS712]-+-[Relay 1]- Quạt 12V (ưu tiên CAO)

+-[Relay 2]- LED 12V (ưu tiên THẤP)

ESP32-S3: đo 4 khối/giây, điều khiển cục bộ 2 s/lần,

RTC giữ giờ, đệm 600 bản ghi khi mất mạng

| MQTT 1883 smartenergy/node9988/{telemetry,status,state,event,cmd,ack}

v

Broker MQTT --WSS 8884--> Dashboard (Vercel): realtime, gửi lệnh,

đo độ trễ

| MQTT 1883

v

Backend FastAPI (Render 24/7) -- SQLite / PostgreSQL (Neon)

-- REST /api/* + trợ lý dữ liệu /api/chat

Hình 3.1. Kiến trúc tổng thể hệ thống

Hệ thống gồm bốn lớp. Lớp thiết bị (ESP32-S3) chịu trách nhiệm đo lường và điều khiển thời gian thực; mọi quyết định đóng cắt đều được thực hiện tại đây nên không phụ thuộc vào mạng. Lớp truyền thông là broker MQTT, đóng vai trò trung gian giữa thiết bị, backend và giao diện. Lớp dữ liệu là backend FastAPI: đăng ký nhận mọi topic, ghi vào cơ sở dữ liệu và cung cấp REST API. Lớp ứng dụng là dashboard web, nhận số liệu tức thời trực tiếp từ broker qua WebSocket Secure và lấy dữ liệu lịch sử từ REST API.

Một điểm thiết kế cần nhấn mạnh: dashboard được triển khai trên Vercel, là nền tảng chỉ phục vụ tệp tĩnh và hàm serverless có vòng đời vài giây cho mỗi yêu cầu. Nền tảng này không thể duy trì một kết nối MQTT liên tục để hứng telemetry, do đó tiến trình ingest bắt buộc phải chạy ở một dịch vụ luôn hoạt động (Render hoặc máy tính cục bộ). Việc tách worker ingest khỏi giao diện là hệ quả kỹ thuật chứ không phải lựa chọn tùy ý.

Luồng dữ liệu chính: ESP32 đo và publish telemetry mỗi 2 giây; backend ghi vào bảng telemetry kèm hai mốc thời gian (thời điểm thiết bị tạo gói và thời điểm máy chủ nhận), nhờ đó đo được độ trễ đầu cuối. Luồng điều khiển đi theo chiều ngược lại: dashboard hoặc REST API publish lệnh lên topic cmd, thiết bị áp dụng rồi publish bản tin ack; backend ghi lại cả lệnh lẫn xác nhận, tính độ trễ giữa hai mốc.

# 4. PHẦN CỨNG

## 4.1. Danh mục linh kiện

STT | Linh kiện | Thông số chính | Vai trò
1 | ESP32-S3 DevKitC N16R8 | Xtensa LX7 dual-core 240 MHz, WiFi, ADC 12-bit | Vi điều khiển trung tâm
2 | ACS712-05B | ±5 A, 185 mV/A, cách ly 2.1 kV | Đo dòng tải
3 | Module relay 2 kênh 5 V | Opto cách ly, kích mức thấp, 10 A/30 VDC | Đóng cắt hai tải
4 | LM2596 | Vào 4–35 V, ra 5.0 V, 3 A | Hạ áp nuôi mạch điều khiển
5 | DS3231 | RTC I2C, ±2 ppm, pin dự phòng | Giữ giờ khi mất mạng
6 | OLED SSD1306 | 0.96 inch, 128×64, I2C | Hiển thị tại chỗ
7 | Quạt DC 12 V | khoảng 0.2–0.4 A | Tải 1, ưu tiên cao
8 | LED bar 12 V | khoảng 0.1–0.3 A | Tải 2, ưu tiên thấp
9 | Adapter 12 V – 2 A | | Nguồn chính
10 | Cầu chì 2 A, diode 1N4007, R 10 kΩ/20 kΩ | | Bảo vệ và phân áp ADC

Bảng 4.1. Danh mục linh kiện

## 4.2. Sơ đồ chân

Linh kiện | Chân | ESP32-S3 | Chức năng
ACS712 | OUT (qua phân áp 10 kΩ/20 kΩ) | GPIO 1 (ADC1_CH0) | Tín hiệu analog đo dòng
Relay 2CH | IN1 | GPIO 12 | Tải 1 – Quạt 12 V
Relay 2CH | IN2 | GPIO 13 | Tải 2 – LED 12 V
DS3231 (0x68) | SDA / SCL | GPIO 8 / GPIO 9 | Đồng hồ thời gian thực
SSD1306 (0x3C) | SDA / SCL | GPIO 8 / GPIO 9 | Hiển thị, chung bus I2C
Buzzer qua S8050 | Base qua R 1 kΩ | GPIO 14 | Báo động vượt ngưỡng
LM2596 | OUT+ / OUT− | 5V / GND | Cấp nguồn 5 V

Bảng 4.2. Bảng kết nối chân

## 4.3. Thiết kế bảo vệ và các quyết định kỹ thuật

- Cầu phân áp 10 kΩ/20 kΩ tại đầu ra ACS712: tại 5 A điện áp ra đạt 3.43 V, vượt dải đo an toàn của ADC ESP32-S3. Hệ số 0.667 đưa dải 0–5 V về 0–3.33 V.
- Cầu chì 2 A trên đường +12 V, đặt trước cảm biến, bảo vệ toàn bộ mạch động lực.
- Diode 1N4007 mắc ngược song song với quạt để triệt sức điện động ngược khi ngắt tải cảm.
- Tiếp điểm relay 10 A/30 VDC, lớn hơn nhiều lần dòng tải thực tế dưới 1 A, bảo đảm biên an toàn.
- Tháo jumper JD-VCC của module relay và cấp VCC 3.3 V để mức logic cao của ESP32 tắt được opto hoàn toàn.
- Chọn ESP32-S3 thay cho ESP32 classic vì GPIO 12 trên bản classic là chân strapping MTDI, mức cao lúc khởi động sẽ đặt sai điện áp flash và gây lỗi nạp.
- Module LM2596 lấy nguồn ở phía trước cảm biến để dòng tiêu thụ của mạch điều khiển không bị tính vào kết quả đo của tải.

# 5. GIAO THỨC VÀ MẠNG

## 5.1. Cây topic và chất lượng dịch vụ

Topic | Hướng | QoS / retain | Nội dung
smartenergy/node9988/telemetry | Thiết bị → hệ thống | QoS 0 | Số liệu đo, chu kỳ 2 giây
smartenergy/node9988/status | Thiết bị → hệ thống | QoS 1, retained, LWT | online / offline
smartenergy/node9988/state | Thiết bị → hệ thống | retained | Cấu hình và trạng thái tải
smartenergy/node9988/event | Thiết bị → hệ thống | QoS 0 | Sa thải, khôi phục, cảnh báo
smartenergy/node9988/cmd | Web/Backend → thiết bị | QoS 1 | Lệnh kèm cmd_id
smartenergy/node9988/ack | Thiết bị → hệ thống | QoS 0 | Xác nhận lệnh và trạng thái thực tế

Bảng 5.1. Đặc tả cây topic MQTT

Telemetry dùng QoS 0 vì bản tin sau thay thế hoàn toàn bản tin trước; mất mát được phát hiện qua trường seq tăng đơn điệu, từ đó tính được tỉ lệ nhận gói mà không cần chi phí bắt tay của QoS 1. Lệnh điều khiển dùng QoS 1 ở chiều đăng ký. Thư viện PubSubClient trên ESP32 chỉ hỗ trợ publish ở QoS 0, vì vậy độ tin cậy của lệnh được bảo đảm ở tầng ứng dụng bằng cặp cmd_id/ack kèm thời gian chờ 5 giây, đây là một hạn chế đã biết và được nêu ở mục 12.

## 5.2. Định dạng bản tin

{"dev":"node9988","ts":1789550319106,"seq":42,

"current_a":0.352,"power_w":4.224,"energy_today_wh":0.0931,

"energy_total_wh":1.204,"peak_today_w":4.301,

"fan":true,"led":true,"led_shed":"NONE","auto_mode":true,"safe_mode":false,

"peak_limit_w":3.5,"hysteresis_w":0.5,"budget_wh":0,"led_est_w":1.8,

"alarm_over":false,"alarm_budget":false,"sensor_mv":2565.1,"zero_mv":2500.0,

"rssi":-55,"uptime_s":84,"time_src":"ntp","rtc":true,"buffered_count":0}

Trường ts là thời gian Unix theo mili giây lấy từ NTP hoặc DS3231. Mọi bản tin đều mang định danh thiết bị, nhờ đó hệ thống mở rộng cho nhiều node mà không phải đổi cấu trúc.

## 5.3. Phát hiện trạng thái sẵn sàng

Khi kết nối, thiết bị đăng ký di chúc "offline" trên topic status với cờ retained, rồi tự publish "online". Nếu thiết bị mất điện hoặc rớt mạng, broker tự công bố "offline" sau khi hết thời gian keepalive 15 giây. Dashboard và backend nhờ đó biết chính xác thời điểm thiết bị ngừng hoạt động. Ngoài ra dashboard còn theo dõi độ tươi của dữ liệu: quá 6 giây, tức ba chu kỳ telemetry, mà không nhận được gói mới thì hiển thị cảnh báo dữ liệu cũ.

# 6. BACKEND VÀ DỮ LIỆU

## 6.1. Lược đồ cơ sở dữ liệu

Bảng | Cột chính | Ý nghĩa
telemetry | ts_device, ts_server, seq, current_a, power_w, energy_today_wh, peak_today_w, fan, led, led_shed, auto_mode, safe_mode, peak_limit_w, alarm_over, sensor_mv, rssi | Chuỗi thời gian số liệu đo
events | ts_device, ts_server, type, detail, power_w, limit_w | Sa thải, khôi phục, cảnh báo
availability | ts_server, status | Lịch sử online/offline
commands | cmd_id, source, payload, ts_client, ts_seen_server, ts_ack_server, ack_ok, latency_ms | Nhật ký lệnh và độ trễ xác nhận
settings | key, value | Đơn giá điện

Bảng 6.1. Lược đồ cơ sở dữ liệu

Backend hỗ trợ đồng thời SQLite (chạy trên máy cá nhân) và PostgreSQL (dịch vụ Neon khi triển khai 24/7). Lớp truy cập dữ liệu tự chuyển đổi cú pháp giữa hai hệ quản trị, nhờ đó cùng một mã nguồn chạy được ở cả hai môi trường. Dữ liệu cũ hơn số ngày cấu hình được dọn định kỳ để phù hợp dung lượng miễn phí của Neon.

## 6.2. Các endpoint REST chính

Endpoint | Chức năng
GET /api/status | Telemetry mới nhất, trạng thái online, độ tươi dữ liệu, điện năng và chi phí trong ngày
GET /api/history?minutes=&bucket_s= | Chuỗi thời gian đã gộp theo khoảng, giới hạn 300 điểm
GET /api/energy/daily?days= | Điện năng, đỉnh và chi phí theo từng ngày
GET /api/events | /api/availability | /api/commands | Các nhật ký
POST /api/command | Gửi lệnh, chờ xác nhận, trả về cả trạng thái yêu cầu và đã xác nhận
POST /api/config | Ngưỡng đỉnh, dải trễ, ngân sách, chế độ tự động
GET /api/stats?minutes= | Thống kê phục vụ thực nghiệm
POST /api/chat | Trợ lý dữ liệu
GET /api/export/{bảng}.csv | Xuất dữ liệu phục vụ báo cáo

Bảng 6.2. Danh mục REST API

Endpoint /api/stats tổng hợp trong một khoảng thời gian: đỉnh công suất, công suất trung bình, điện năng, tổng thời gian vượt ngưỡng, số lần đóng cắt tải, tỉ lệ nhận gói suy ra từ khoảng trống của seq, độ trễ thiết bị đến máy chủ và độ trễ lệnh đến xác nhận theo giá trị trung bình, phân vị 95 và giá trị lớn nhất. Đây chính là bộ số liệu dùng cho chương thực nghiệm.

# 7. ỨNG DỤNG VÀ GIAO DIỆN

Dashboard là một trang web đơn, nhận số liệu tức thời trực tiếp từ broker qua WebSocket Secure và lấy lịch sử từ REST API. Cách này giúp giao diện vẫn hiển thị thời gian thực ngay cả khi backend tạm ngừng, chỉ mất phần lịch sử.

- Sáu thẻ chỉ số: công suất tức thời kèm ngưỡng, dòng điện, điện năng trong ngày kèm thanh tiến độ ngân sách, chi phí ước tính, đỉnh công suất trong ngày, chế độ quản lý tải.
- Đồ thị thời gian thực năm phút gần nhất với ba đường: công suất, ngưỡng đỉnh và dòng điện; trục trái theo W, trục phải theo A.
- Khung điều khiển hai tải, hiển thị tách bạch trạng thái được yêu cầu và trạng thái đã được thiết bị xác nhận, kèm độ trễ xác nhận và cảnh báo khi quá thời gian chờ.
- Khung cấu hình: chế độ tự động, ngưỡng đỉnh, dải trễ, ngân sách ngày, hiệu chuẩn điểm không, đặt lại điện năng, đơn giá điện.
- Nhật ký cảnh báo và sự kiện, hợp nhất dữ liệu thời gian thực với lịch sử lấy từ backend.
- Khung lịch sử: biểu đồ công suất theo 1 giờ, 6 giờ, 24 giờ, 7 ngày và biểu đồ cột điện năng bảy ngày gần nhất.
- Khung đo đạc thực nghiệm: độ trễ hai chiều, tỉ lệ nhận gói, số lệnh chưa xác nhận, nút lấy thống kê và xuất CSV.
- Trợ lý dữ liệu và cửa sổ nhật ký MQTT phục vụ gỡ lỗi khi trình diễn.

Màn hình OLED tại chỗ hiển thị giờ lấy từ DS3231, công suất, dòng điện, điện năng trong ngày, ngưỡng, trạng thái hai tải, biểu tượng WiFi và MQTT, số bản ghi đang nằm trong bộ đệm. Nhờ vậy khi trình diễn vẫn chứng minh được thiết bị hoạt động độc lập với mạng.

## 7.1. Trợ lý dữ liệu

Trợ lý chạy hoàn toàn cục bộ trong backend. Câu hỏi được chuẩn hóa bằng cách bỏ dấu tiếng Việt, phân loại ý định bằng biểu thức chính quy, sau đó truy vấn trực tiếp cơ sở dữ liệu và ghép câu trả lời từ số liệu thật. Vì không sinh văn bản tự do nên không tồn tại nguy cơ bịa số, khác với cách gọi mô hình ngôn ngữ lớn.

Với câu mang tính điều khiển, hệ thống không tự thực thi mà trả về mô tả hành động; giao diện hiện nút xác nhận, người dùng bấm thì lệnh mới được gửi. Đây là ràng buộc an toàn bắt buộc khi cho phép ngôn ngữ tự nhiên tác động lên relay.
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

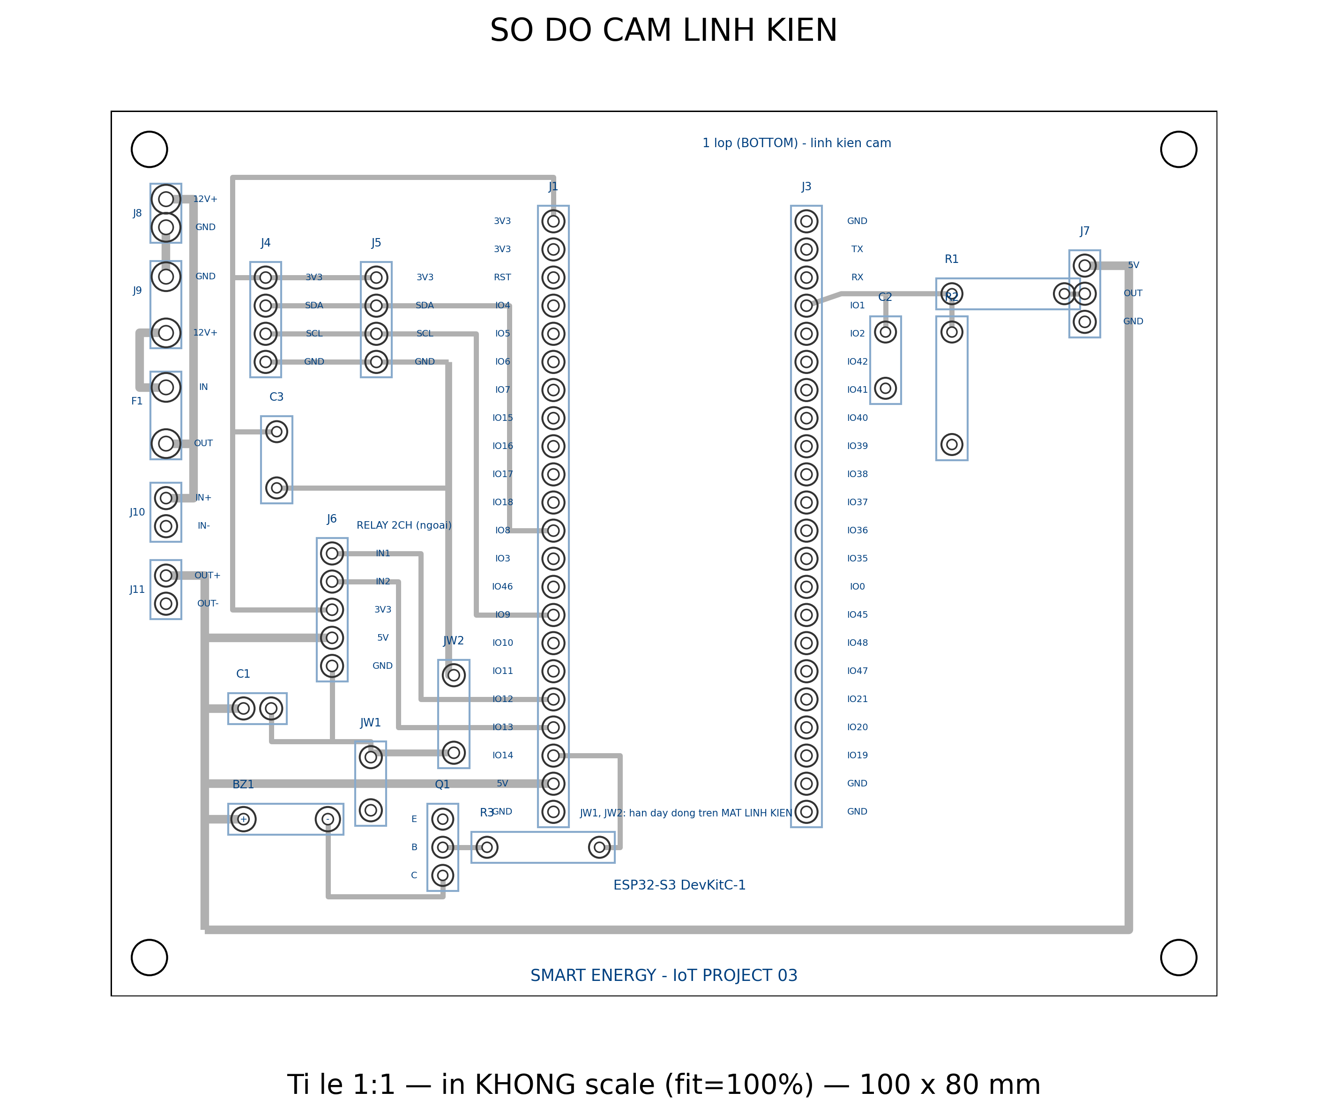
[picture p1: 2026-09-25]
pcb/preview.png

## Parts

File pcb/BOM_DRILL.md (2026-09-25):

# Danh sách linh kiện và mũi khoan

| Ref | Giá trị | Mô tả | Số chân | Mũi khoan (mm) |
|---|---|---|---|---|
| J1 | 1x22 | ESP32-S3 DevKitC hàng TRÁI | 22 | 1.0 |
| J3 | 1x22 | ESP32-S3 DevKitC hàng PHẢI | 22 | 1.0 |
| J4 | 1x4 | DS3231 (RTC) | 4 | 1.0 |
| J5 | 1x4 | OLED SSD1306 | 4 | 1.0 |
| J6 | 1x5 | Relay 2 kênh (module ngoài) | 5 | 1.0 |
| J7 | 1x3 | ACS712-05B | 3 | 1.0 |
| R1 | 10k | Phân áp trên | 2 | 0.9 |
| R2 | 20k | Phân áp dưới | 2 | 0.9 |
| C2 | 100nF | Lọc nhiễu ADC | 2 | 0.9 |
| J8 | DOMINO | Ngõ ra 12V đã qua cầu chì | 2 | 1.3 |
| J9 | DOMINO | Nguồn 12V vào | 2 | 1.3 |
| F1 | 2A | Cầu chì (đế 5x20 hoặc dây) | 2 | 1.3 |
| J10 | 1x2 | LM2596 ngõ VÀO (IN+/IN-) | 2 | 1.0 |
| J11 | 1x2 | LM2596 ngõ RA (OUT+/OUT-) | 2 | 1.0 |
| C1 | 100uF | Lọc nguồn 5V | 2 | 1.0 |
| C3 | 100nF | Lọc nguồn 3V3 | 2 | 0.9 |
| JW1 | DAY NOI | Dây nối GND bắc qua đường 5V | 2 | 1.0 |
| JW2 | DAY NOI | Dây nối GND bắc qua 2 đường IN1/IN2 | 2 | 1.0 |
| BZ1 | BUZZER 5V | Còi chíp 5V active | 2 | 1.0 |
| Q1 | S8050 | NPN lái còi (E-B-C) | 3 | 0.9 |
| R3 | 1k | Điện trở cực nền | 2 | 0.9 |
| — | — | Lỗ bắt ốc (4 góc) | 4 | 3.2 |

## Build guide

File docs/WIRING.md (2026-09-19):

# Sơ đồ kết nối phần cứng — Project 03 (ESP32-S3)

## 1. Danh mục linh kiện

| STT | Linh kiện | Thông số | SL |
|---|---|---|---|
| 1 | ESP32-S3 DevKitC (N16R8) | 16 MB flash, 8 MB PSRAM, ADC 12-bit | 1 |
| 2 | Cảm biến dòng ACS712-05B | Hall cách ly, ±5 A, 185 mV/A, Vout = 2.5 V tại 0 A | 1 |
| 3 | Module relay 2 kênh 5 V | Opto cách ly, kích mức thấp, tiếp điểm 10 A/30 VDC | 1 |
| 4 | Module hạ áp LM2596 | 4–35 V vào, ra chỉnh 5.0 V, 3 A | 1 |
| 5 | DS3231 | RTC I2C, pin CR2032, sai số ±2 ppm | 1 |
| 6 | OLED SSD1306 | 0.96", 128×64, I2C | 1 |
| 7 | Quạt DC 12 V (Tải 1 — ưu tiên cao) | ~0.2–0.4 A | 1 |
| 8 | LED bar 12 V (Tải 2 — ưu tiên thấp) | ~0.1–0.3 A | 1 |
| 9 | Adapter 12 V – 2 A | | 1 |
| 10 | Điện trở 10 kΩ, 20 kΩ | cầu phân áp cho ADC | 1 cặp |
| 11 | Cầu chì 2 A + đế | bảo vệ đường 12 V | 1 |
| 12 | Diode 1N4007 | chống sức điện động ngược của quạt | 1 |
| 13 | Buzzer 5 V active + transistor S8050 + R 1 kΩ | báo động (tuỳ chọn) | 1 |

## 2. Bảng chân (Pinout)

### Khối nguồn
| Từ | Đến | Ghi chú |
|---|---|---|
| Adapter 12 V (+) | Cầu chì 2 A → Domino 12V+ | Toàn bộ dòng tải đi qua cầu chì |
| Domino 12V+ | LM2596 IN+ | |
| Domino 12V− | LM2596 IN−, GND chung | Nối chung mass 12 V và 5 V |
| LM2596 OUT+ | Chân 5V ESP32, VCC relay, VCC ACS712 | Chỉnh đúng 5.00 V **trước khi** cắm ESP32 |

### Khối tín hiệu
| Linh kiện | Chân | ESP32-S3 | Chức năng |
|---|---|---|---|
| ACS712 | OUT | **GPIO 1** (ADC1_CH0) qua phân áp 10 kΩ/20 kΩ | Đo dòng tải DC |
| Relay 2CH | IN1 | **GPIO 12** | Tải 1 — Quạt 12 V |
| Relay 2CH | IN2 | **GPIO 13** | Tải 2 — LED 12 V |
| DS3231 | SDA / SCL | **GPIO 8 / GPIO 9** | RTC, địa chỉ 0x68 |
| SSD1306 | SDA / SCL | **GPIO 8 / GPIO 9** | OLED, địa chỉ 0x3C |
| DS3231, SSD1306 | VCC | **3V3** | Hai module dùng chung bus I2C |
| Buzzer (qua S8050) | Base qua R 1 kΩ | **GPIO 14** | Báo động, đặt `PIN_BUZZER = -1` nếu không lắp |

Cầu phân áp ADC: `OUT ACS712 → R 10 kΩ → nút đo (vào GPIO 1) → R 20 kΩ → GND`. Hệ số 20/(10+20) = 0.667, đưa dải 0–5 V về 0–3.33 V. Khai báo `DIVIDER_RATIO = 0.6667` trong firmware. Nếu không lắp phân áp thì để `1.0`, nhưng chỉ an toàn khi dòng tải luôn dưới ~3 A.

### Mạch động lực
```
+12V (sau cầu chì) ──> ACS712 IP+ ; ACS712 IP- ──┬── COM1 (relay 1) ── NO1 ── Quạt 12V (+)
                                                 └── COM2 (relay 2) ── NO2 ── LED 12V (+)
Quạt 12V (−), LED 12V (−) ──> GND 12V
Diode 1N4007: catot về (+) quạt, anot về (−) quạt
LM2596 lấy nguồn TRƯỚC ACS712 để không tính dòng của mạch điều khiển vào phép đo
```
Relay kích mức thấp: `digitalWrite(pin, LOW)` = đóng tiếp điểm = tải BẬT.

## 3. Lưu ý an toàn và độ chính xác

- **Mức logic relay**: module 5 V điều khiển bằng GPIO 3.3 V có thể không tắt hẳn opto. Tháo jumper JD-VCC rồi cấp JD-VCC = 5 V, VCC = 3.3 V.
- **Không dùng ESP32 classic với GPIO 12**: đó là chân strapping MTDI, mức cao lúc khởi động làm sai điện áp flash. Dự án dùng ESP32-S3 nên GPIO 12/13 an toàn.
- **Không dùng GPIO 35–37** trên bản N16R8 (dành cho PSRAM octal).
- **Calib điểm 0**: lúc khởi động firmware đo trung bình điện áp khi cả 2 tải tắt. Phải giữ tải tắt trong ~1 giây đầu, hoặc bấm "Calib điểm 0" trên dashboard sau này.
- **Kiểm tra trước khi cắm chip**: đo thông mạch 12V–GND và 5V–GND bằng đồng hồ ở nấc còi, không được kêu.
- **Toàn bộ mạch chỉ làm việc với 12 VDC**, không có phần nào chạm điện lưới, đúng yêu cầu "cấm mạch đo điện áp lưới tự chế" của đề.

## 4. Quy trình hàn trên phíp lỗ

1. Hàn hàng rào cái cho ESP32, DS3231, OLED, relay trước; hàn 2 chân chéo để định vị rồi mới hàn hết.
2. Rút hết module ra khỏi rào cái trước khi hàn các đường dây còn lại.
3. Đường 12 V và GND đi dây đồng 0.5–1.0 mm phủ thiếc dày, chịu được 2–3 A.
4. Đo ngắn mạch, cấp 12 V, chỉnh LM2596 ra đúng 5.00 V.
5. Ngắt nguồn, cắm module, cấp lại điện, kiểm tra OLED sáng và Serial in `[CAL] zero = ...`.

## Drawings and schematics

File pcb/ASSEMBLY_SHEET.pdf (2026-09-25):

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

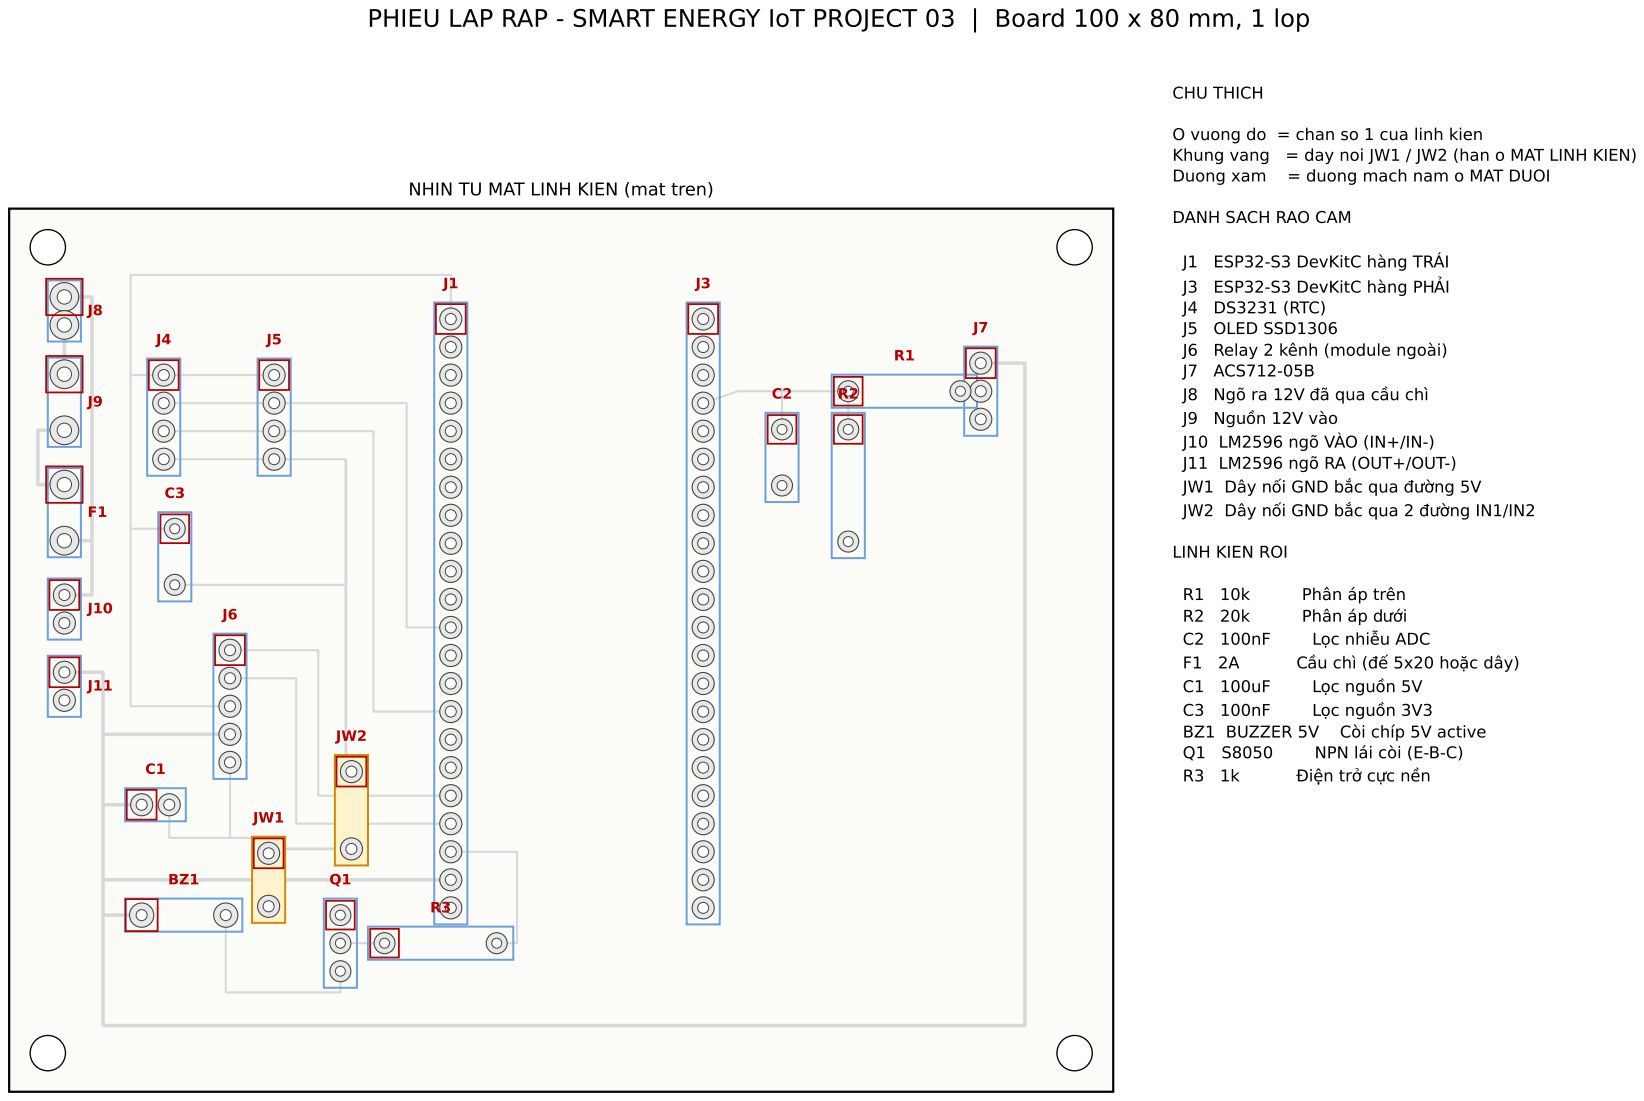
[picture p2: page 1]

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

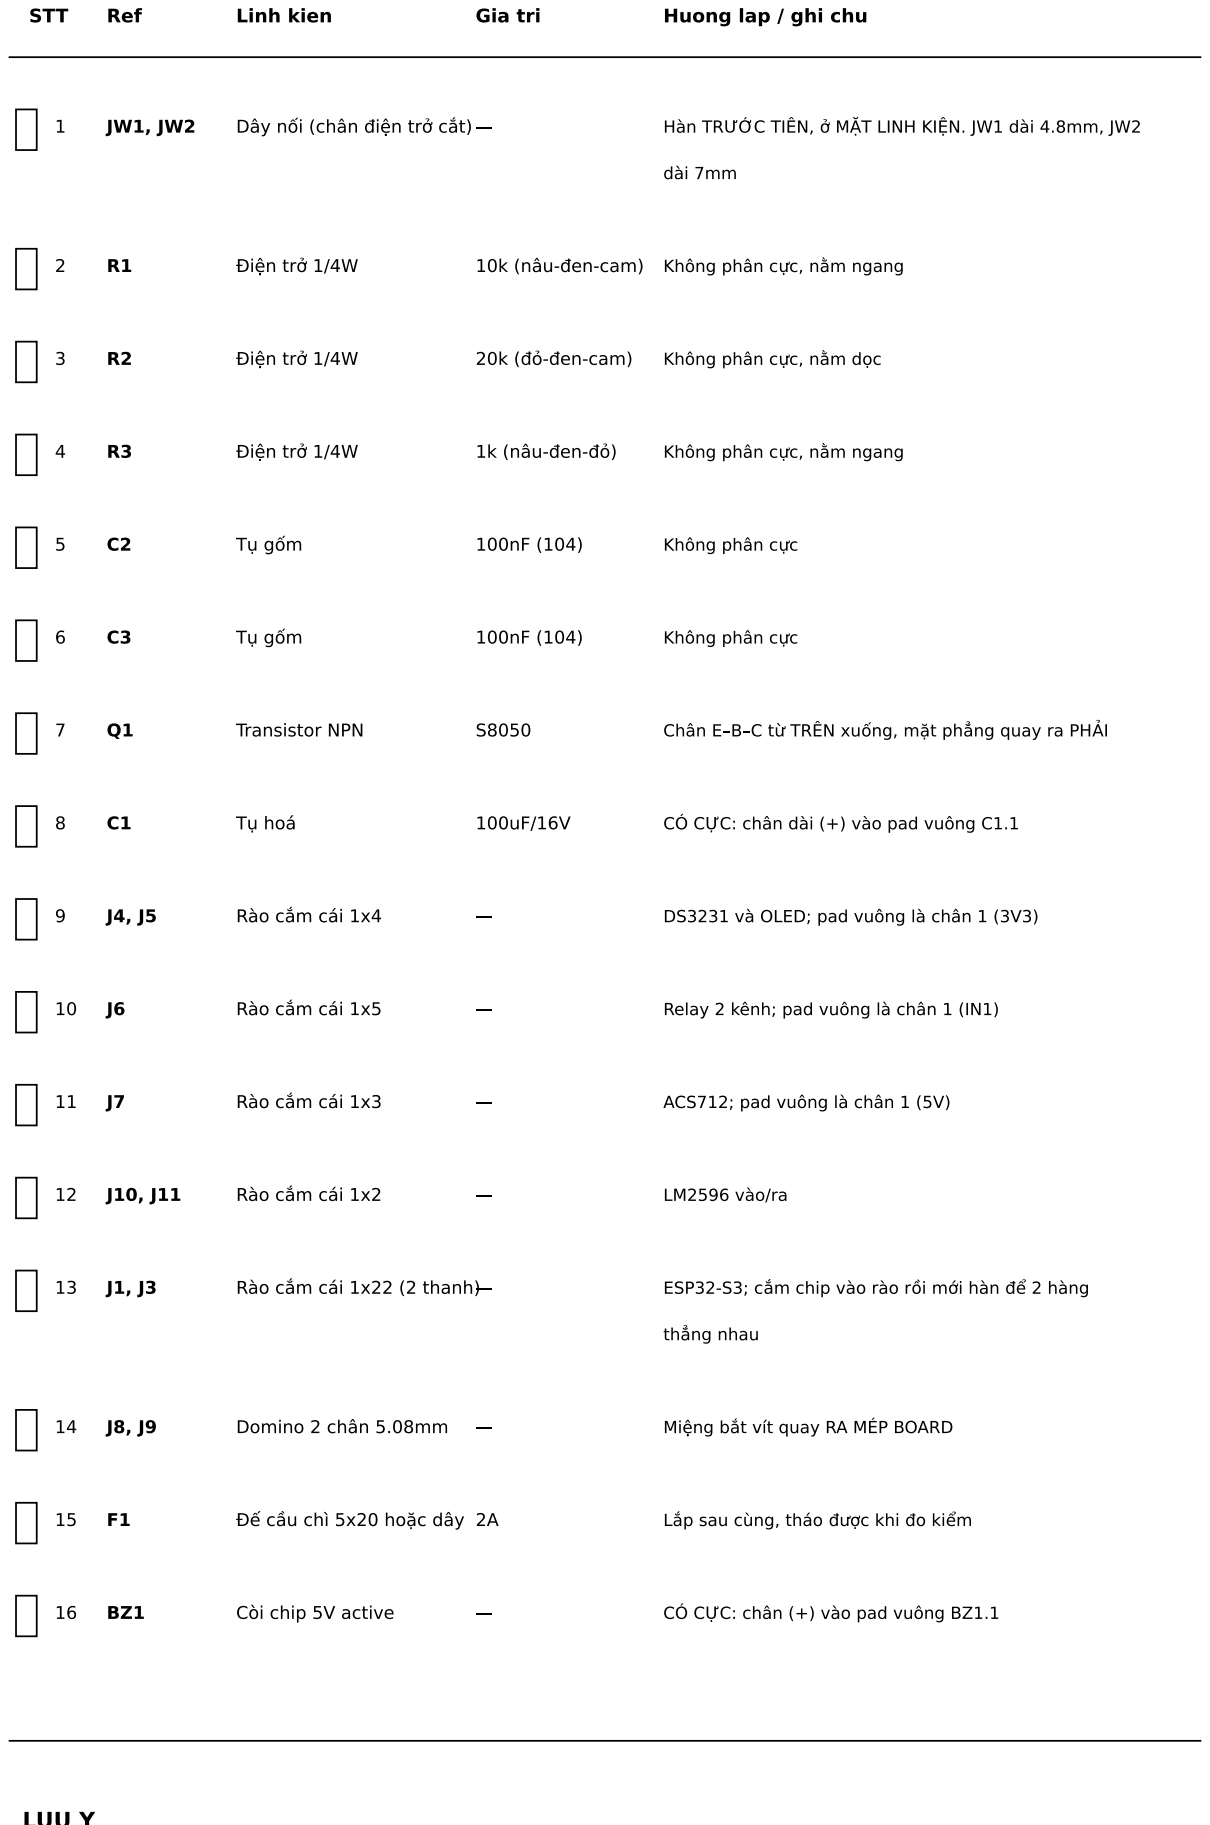
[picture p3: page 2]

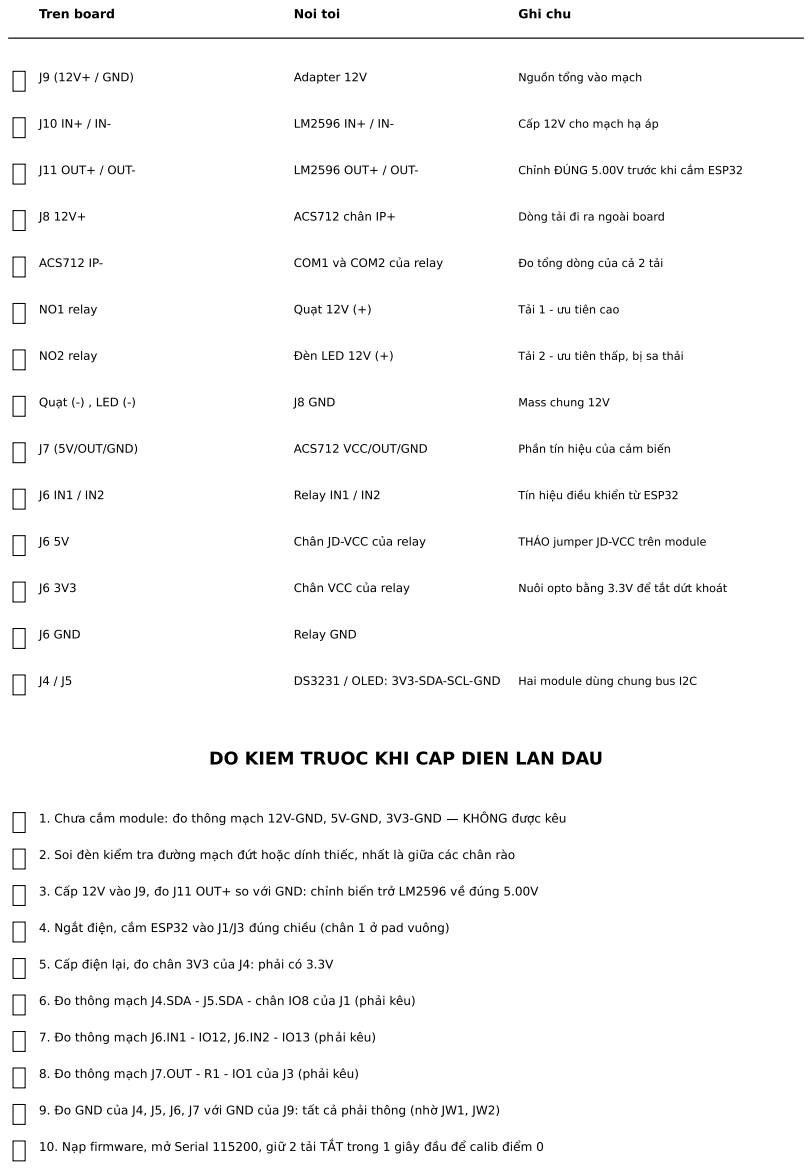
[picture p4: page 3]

DO KIEM TRUOC KHI CAP DIEN LAN DAU

6. o thông m ch J4.SDA - J5.SDA - chân IO8 c a J1 (ph i kêu)

7. o thông m ch J6.IN1 - IO12, J6.IN2 - IO13 (ph i kêu)

8. o thông m ch J7.OUT - R1 - IO1 c a J3 (ph i kêu)

9. o GND c a J4, J5, J6, J7 v i GND c a J9: t t c ph i thông (nh JW1, JW2)
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

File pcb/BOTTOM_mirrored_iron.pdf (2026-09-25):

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

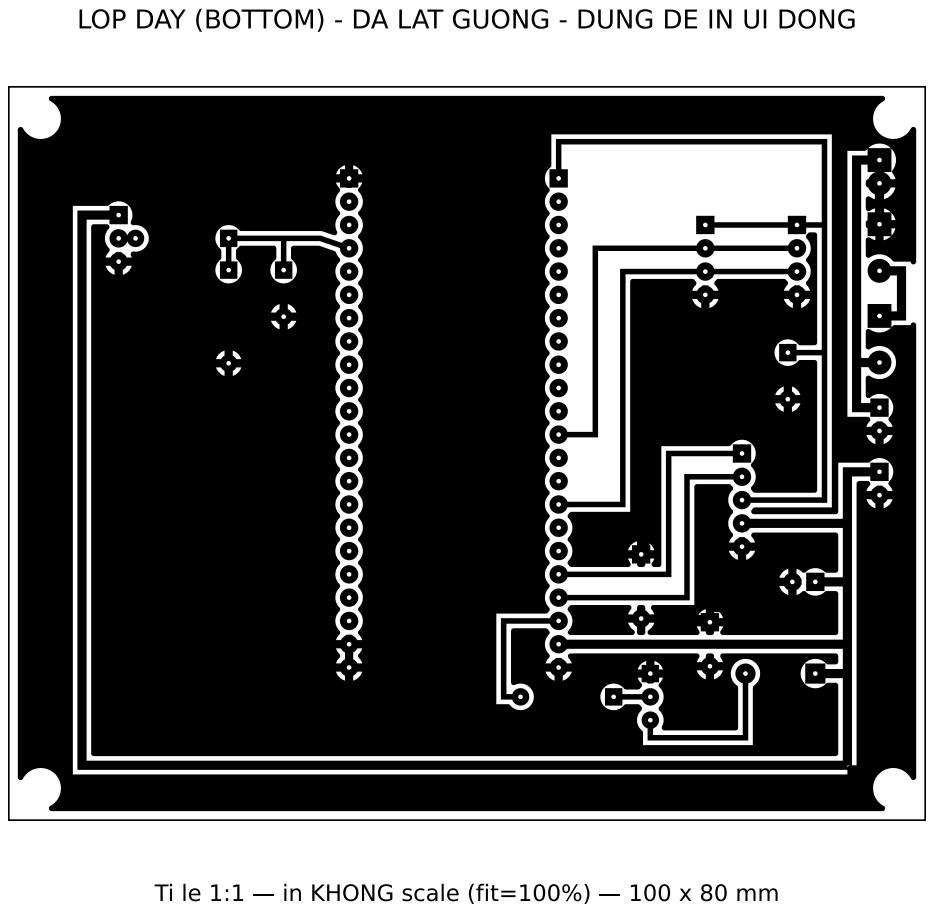
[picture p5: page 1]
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

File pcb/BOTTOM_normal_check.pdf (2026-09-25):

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

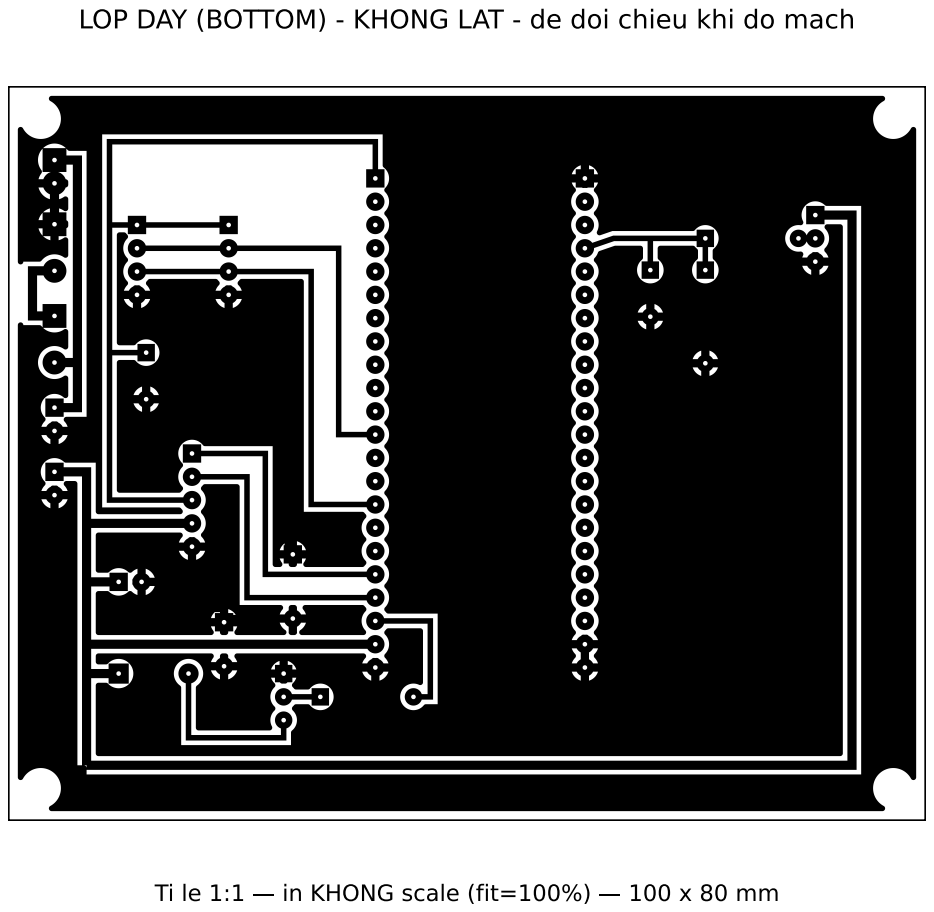
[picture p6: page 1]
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

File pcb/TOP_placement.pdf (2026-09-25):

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

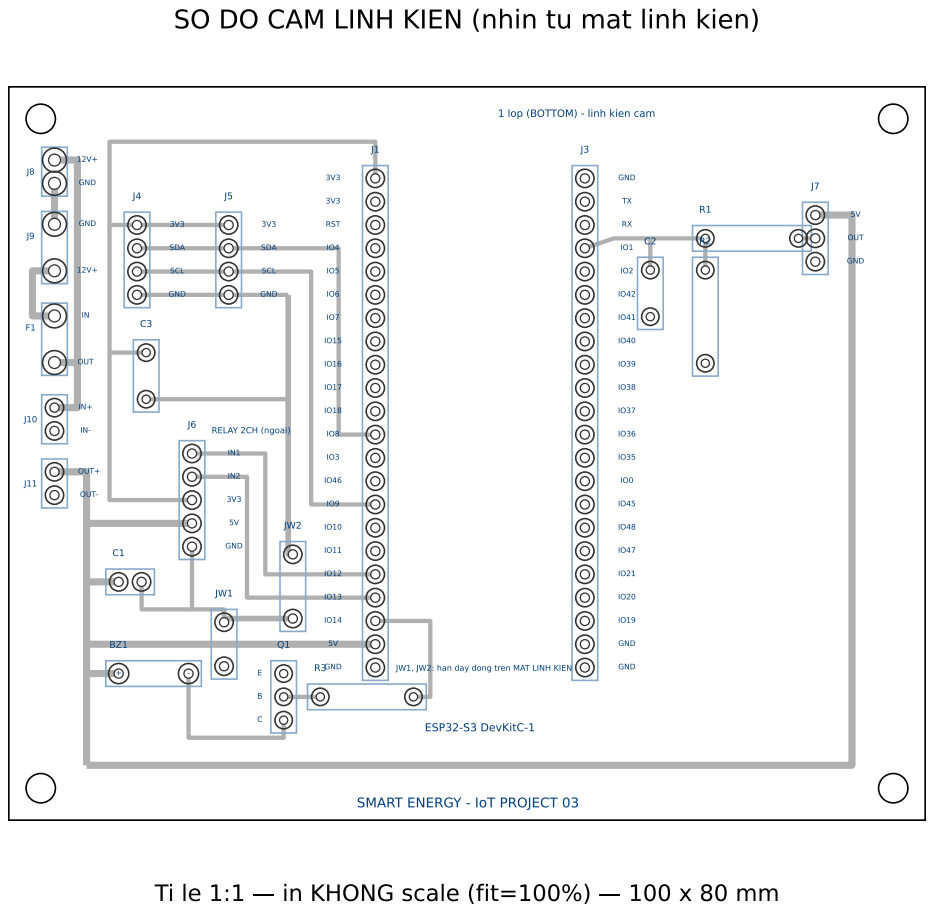
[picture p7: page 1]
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

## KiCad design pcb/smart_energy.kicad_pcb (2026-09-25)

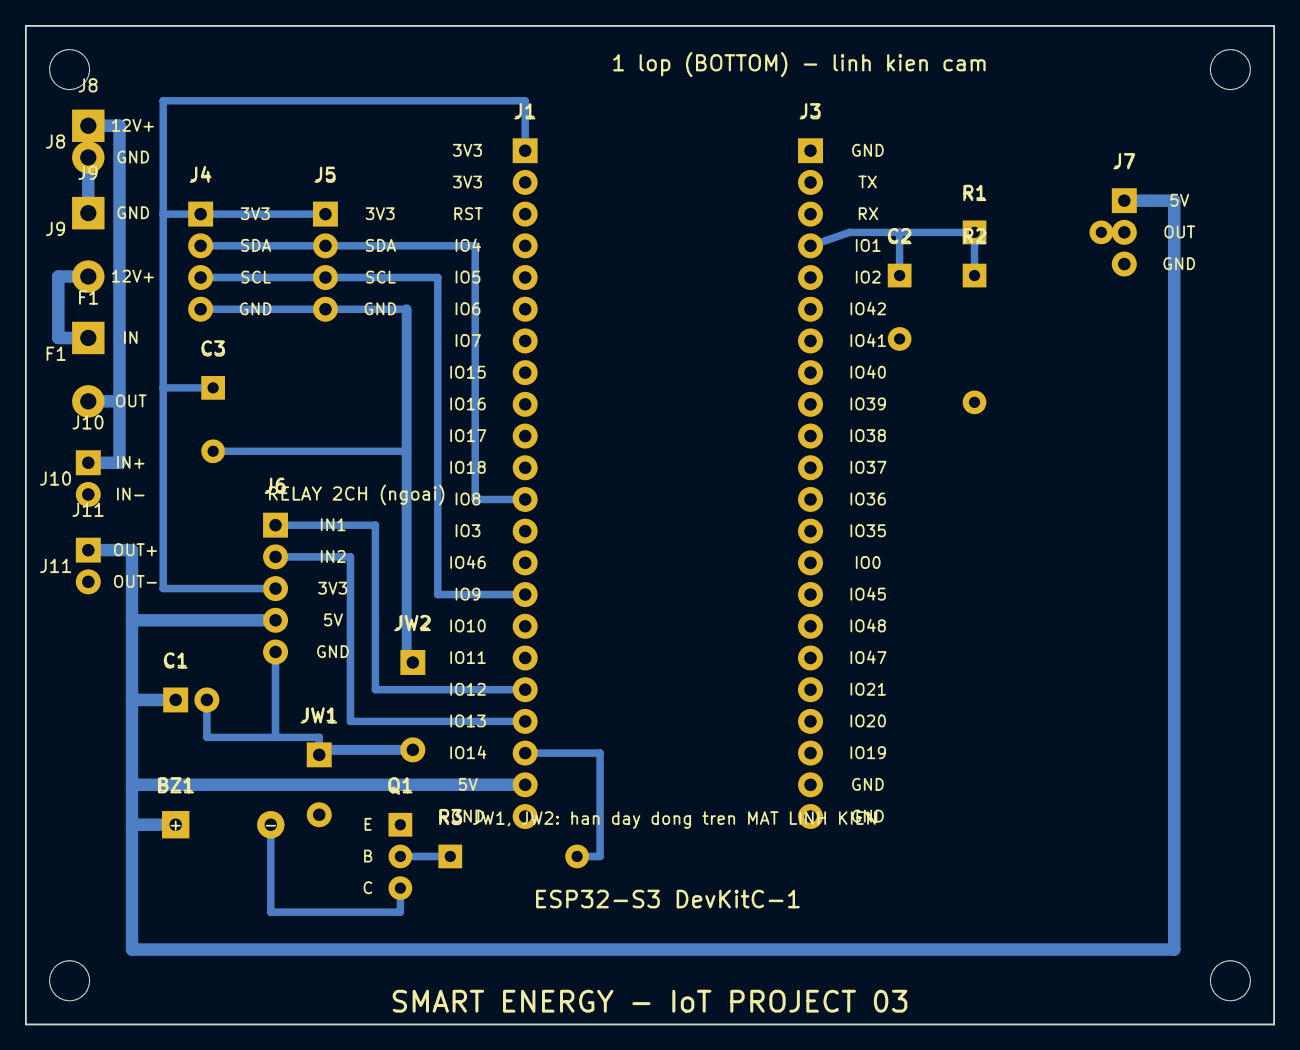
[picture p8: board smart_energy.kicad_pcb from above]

Board: 2 copper layers, 100.0 x 80.0 mm, 21 parts (0 on the bottom side), 14 nets.

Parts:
BZ1: BUZZER 5V; BZ1
C1: 100uF; C1
C2: 100nF; C2
C3: 100nF; C3
F1: 2A; F1
J1: 1x22; J1
J3: 1x22; J3
J4: 1x4; J4
J5: 1x4; J5
J6: 1x5; J6
J7: 1x3; J7
J8: DOMINO; J8
J9: DOMINO; J9
J10: 1x2; J10
J11: 1x2; J11
JW1: DAY NOI; JW1
JW2: DAY NOI; JW2
Q1: S8050; Q1
R1: 10k; R1
R2: 20k; R2
R3: 1k; R3

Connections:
+3V3: C3.1, J1.1, J4.1, J5.1, J6.3
+5V: BZ1.1, C1.1, J1.21, J6.4, J7.1, J11.1
+12F: F1.2, J8.1, J10.1
+12V: F1.1, J9.2
ACS_OUT: J7.2, R1.2
ADC: C2.1, J3.4, R1.1, R2.1
BUZZ: J1.20, R3.2
BZC: BZ1.2, Q1.3
GND: C1.2, C2.2, C3.2, J1.22, J3.1, J3.21, J3.22, J4.4, J5.4, J6.5, J7.3, J8.2, J9.1, J10.2, J11.2, JW1.1, JW1.2, JW2.1, JW2.2, Q1.1, R2.2
IN1: J1.18, J6.1
IN2: J1.19, J6.2
QB: Q1.2, R3.1
SCL: J1.15, J4.3, J5.3
SDA: J1.12, J4.2, J5.2

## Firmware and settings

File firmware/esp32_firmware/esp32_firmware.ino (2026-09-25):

/*
 * =====================================================================================
 *  PROJECT 03 - SMART ENERGY MONITORING & INTELLIGENT LOAD MANAGEMENT
 *  Firmware v22 - ESP32-S3 (N16R8)
 *
 *  v19 thêm so với v17/v18:
 *   - DS3231 (I2C): giữ giờ khi mất WiFi; NTP -> RTC khi online, RTC -> hệ thống khi offline
 *   - SSD1306 OLED 128x64 (I2C): hiện giờ, công suất, điện năng, trạng thái tải, mạng
 *   - Bộ đệm vòng 600 bản ghi (~20 phút): mất broker thì lưu lại, có mạng gửi bù
 *     (gói gửi bù có "buffered":true, backend dùng ts thiết bị làm mốc thời gian)
 *
 *  Thư viện cần cài (Library Manager):
 *    PubSubClient · ArduinoJson · RTClib · Adafruit SSD1306 · Adafruit GFX Library
 *  Không lắp module nào thì đặt USE_RTC / USE_OLED = 0, firmware vẫn chạy đầy đủ.
 * =====================================================================================
 */

#define ARDUINOJSON_USE_LONG_LONG 1

// ======================================================
//  CHUA GAN DS3231 / OLED thi de nguyen 0 (chi can 2 thu vien PubSubClient + ArduinoJson).
//  Khi nao gan module roi thi doi thanh 1 va cai them RTClib, Adafruit SSD1306, Adafruit GFX.
// ======================================================
#define USE_RTC  0     // chua gan DS3231 -> 0
#define USE_OLED 1     // DA GAN OLED SSD1306 -> 1

#include <WiFi.h>
#include <PubSubClient.h>
#include <ArduinoJson.h>
#include <Preferences.h>
#include <time.h>
#include <sys/time.h>
#if USE_RTC || USE_OLED
  #include <Wire.h>
#endif
#if USE_RTC
  #include <RTClib.h>
#endif
#if USE_OLED
  #include <Adafruit_GFX.h>
  #include <Adafruit_SSD1306.h>
#endif

// -------------------------------------------------------------------------------------
// 1. BÍ MẬT (tạo secrets.h cạnh file .ino, KHÔNG commit)
// -------------------------------------------------------------------------------------
#if __has_include("secrets.h")
  #include "secrets.h"
#else
  #define WIFI_SSID     "YOUR_WIFI"
  #define WIFI_PASSWORD "YOUR_PASSWORD"
  #define MQTT_USER     ""
  #define MQTT_PASS     ""
#endif

// -------------------------------------------------------------------------------------
// 2. MQTT - cây topic: smartenergy/<device_id>/<kênh>
// -------------------------------------------------------------------------------------
const char* DEVICE_ID   = "node9988";
const char* MQTT_BROKER = "broker.hivemq.com";
const int   MQTT_PORT   = 1883;

const char* T_TELEMETRY = "smartenergy/node9988/telemetry";
const char* T_STATUS    = "smartenergy/node9988/status";
const char* T_STATE     = "smartenergy/node9988/state";
const char* T_EVENT     = "smartenergy/node9988/event";
const char* T_CMD       = "smartenergy/node9988/cmd";
const char* T_ACK       = "smartenergy/node9988/ack";

// -------------------------------------------------------------------------------------
// 3. PHẦN CỨNG
// -------------------------------------------------------------------------------------
const int PIN_ACS712    = 1;    // ADC1_CH0, nên qua cầu phân áp 10k/20k
const int PIN_RELAY_FAN = 12;   // Tải 1 - Quạt 12V (ưu tiên CAO), relay active LOW
const int PIN_RELAY_LED = 13;   // Tải 2 - LED 12V  (ưu tiên THẤP), relay active LOW
const int PIN_BUZZER    = 14;   // -1 nếu không lắp
const int PIN_I2C_SDA   = 8;    // DS3231 + SSD1306 dùng chung
const int PIN_I2C_SCL   = 9;
uint8_t addr_oled = 0x3C;      // tu do giua 0x3C va 0x3D luc khoi dong

const float ACS_MV_PER_A  = 185.0;
const float DIVIDER_RATIO = 1.0;    // 0.6667 nếu dùng phân áp 10k (trên) / 20k (dưới)
const float V_NOMINAL     = 12.0;
const float I_DEADBAND_A  = 0.04;

// -------------------------------------------------------------------------------------
// 4. THÔNG SỐ ĐO / ĐIỀU KHIỂN
// -------------------------------------------------------------------------------------
const unsigned long BLOCK_MS          = 250;
const int           SAMPLES_PER_BLOCK = 64;
const unsigned long TELEMETRY_MS      = 2000;
const unsigned long T_OVER_MS         = 4000;
const unsigned long T_SAFE_MS         = 15000;
const unsigned long MIN_OFF_MS        = 20000;
const unsigned long T_ALARM_MS        = 10000;
const unsigned long OFFLINE_SAFE_MS   = 30000;
const unsigned long SAVE_MS           = 60000;
const unsigned long OLED_MS           = 500;
const int           BUF_SIZE          = 600;    // ~20 phút dữ liệu đệm

float peak_limit_w = 3.0;
float hysteresis_w = 0.5;
float budget_wh    = 0.0;
bool  auto_mode    = false;

// -------------------------------------------------------------------------------------
// 5. BIẾN TRẠNG THÁI
// -------------------------------------------------------------------------------------
enum ShedReason { SHED_NONE = 0, SHED_PEAK, SHED_BUDGET };
const char* shedName(int r) { return r == SHED_PEAK ? "PEAK" : r == SHED_BUDGET ? "BUDGET" : "NONE"; }

bool fan_on = false, led_on = false;
int  led_shed = SHED_NONE;
unsigned long led_switch_ms = 0;

float zero_mv = 2500.0, last_mv = 0, diff_mv = 0;
unsigned long zero_track_ms = 0;
float current_a = 0, power_w = 0, demand_w = 0;
double sum_block_p = 0; int n_block = 0;
double energy_today_wh = 0, energy_total_wh = 0;
float  peak_today_w = 0;
long   day_key = 0;

unsigned long over_since = 0, safe_since = 0;
float led_est_w = 0, p_before_switch = -1;
bool learn_pending = false;
bool alarm_over = false, alarm_budget = false, budget_warned = false;

bool safe_mode = false;
unsigned long mqtt_lost_ms = 0;
unsigned long last_block = 0, last_tele = 0, last_save = 0, last_mqtt_try = 0,
              last_wifi_try = 0, last_oled = 0, last_flush = 0;
unsigned long seq = 0;

// Bộ đệm vòng khi mất kết nối
struct Rec { uint32_t ts; float i, p, e; uint8_t flags; };
Rec buf[BUF_SIZE];
int buf_head = 0, buf_count = 0;

bool have_rtc = false, have_oled = false;
const char* time_src = "none";

WiFiClient net;
PubSubClient mqtt(net);
Preferences prefs;
String client_id;
#if USE_RTC
  RTC_DS3231 rtc;
#endif
#if USE_OLED
  Adafruit_SSD1306 oled(128, 64, &Wire, -1);
#endif

// -------------------------------------------------------------------------------------
uint64_t epochMs() {
  struct timeval tv; gettimeofday(&tv, nullptr);
  if (tv.tv_sec < 1700000000) return 0;
  return (uint64_t)tv.tv_sec * 1000ULL + tv.tv_usec / 1000;
}
uint32_t epochS() { time_t t = time(nullptr); return t > 1700000000 ? (uint32_t)t : 0; }

long todayKey() {
  time_t now = time(nullptr); if (now < 1700000000) return 0;
  struct tm t; localtime_r(&now, &t);
  return (t.tm_year + 1900) * 10000L + (t.tm_mon + 1) * 100L + t.tm_mday;
}
void clockStr(char* out, size_t n) {
  time_t now = time(nullptr);
  if (now < 1700000000) { snprintf(out, n, "--:--:--"); return; }
  struct tm t; localtime_r(&now, &t);
  snprintf(out, n, "%02d:%02d:%02d", t.tm_hour, t.tm_min, t.tm_sec);
}

const char* mqttErr(int rc) {
  switch (rc) {
    case -4: return "het thoi gian cho broker tra loi";
    case -3: return "mat ket noi mang";
    case -2: return "KHONG KET NOI DUOC TCP (mang chan cong 1883?)";
    case -1: return "broker tu choi / ngat ket noi";
    case  0: return "OK";
    case  1: return "broker khong ho tro phien ban MQTT";
    case  2: return "client_id bi tu choi";
    case  3: return "broker dang ban";
    case  4: return "sai user/password";
    case  5: return "khong duoc phep ket noi";
    default: return "khong ro";
  }
}

const char* wifiErr(int st) {
  switch (st) {
    case WL_NO_SSID_AVAIL: return "KHONG TIM THAY TEN WIFI (sai SSID?)";
    case WL_CONNECT_FAILED: return "SAI MAT KHAU WIFI";
    case WL_CONNECTION_LOST: return "mat song";
    case WL_DISCONNECTED: return "dang ket noi...";
    case WL_IDLE_STATUS: return "dang cho";
    case WL_CONNECTED: return "da ket noi";
    default: return "khong ro";
  }
}

void setRelay(int pin, bool on) { digitalWrite(pin, on ? LOW : HIGH); }
void buzzer(bool on) { if (PIN_BUZZER >= 0) digitalWrite(PIN_BUZZER, on ? HIGH : LOW); }

void publishJson(const char* topic, JsonDocument& doc, bool retained = false) {
  if (!mqtt.connected()) return;
  char b[768];
  size_t n = serializeJson(doc, b, sizeof(b));
  mqtt.publish(topic, (const uint8_t*)b, n, retained);
}

void publishEvent(const char* type, const char* detail) {
  Serial.printf("[EVENT] %s %s | P=%.2fW limit=%.2fW\n", type, detail, demand_w, peak_limit_w);
  StaticJsonDocument<384> d;
  d["dev"] = DEVICE_ID; d["ts"] = epochMs(); d["type"] = type; d["detail"] = detail;
  d["power_w"] = demand_w; d["limit_w"] = peak_limit_w; d["energy_today_wh"] = energy_today_wh;
  publishJson(T_EVENT, d);
}

void fillState(JsonDocument& d) {
  d["dev"] = DEVICE_ID; d["ts"] = epochMs();
  d["fan"] = fan_on; d["led"] = led_on; d["led_shed"] = shedName(led_shed);
  d["auto_mode"] = auto_mode; d["safe_mode"] = safe_mode;
  d["peak_limit_w"] = peak_limit_w; d["hysteresis_w"] = hysteresis_w; d["budget_wh"] = budget_wh;
}
void publishState() { StaticJsonDocument<384> d; fillState(d); publishJson(T_STATE, d, true); }

void switchLed(bool on, int reason) {
  if (on == led_on) { led_shed = on ? SHED_NONE : reason; return; }
  p_before_switch = demand_w; learn_pending = true;
  led_on = on; led_shed = on ? SHED_NONE : reason; led_switch_ms = millis();
  setRelay(PIN_RELAY_LED, on);
  publishState();
}

// -------------------------------------------------------------------------------------
// 6. ĐỒNG HỒ THỜI GIAN THỰC
// -------------------------------------------------------------------------------------
void initRTC() {
#if USE_RTC
  if (!rtc.begin(&Wire)) { Serial.println("[RTC] khong tim thay DS3231"); return; }
  have_rtc = true;
  if (rtc.lostPower()) Serial.println("[RTC] mat nguon, gio chua dung - se chinh lai khi co NTP");
  DateTime n = rtc.now();
  if (n.unixtime() > 1700000000) {   // lấy giờ RTC làm giờ hệ thống ngay khi khởi động
    struct timeval tv; tv.tv_sec = (time_t)n.unixtime(); tv.tv_usec = 0;
    settimeofday(&tv, nullptr);
    time_src = "rtc";
    Serial.printf("[RTC] gio tu DS3231: %04d-%02d-%02d %02d:%02d:%02d\n",
                  n.year(), n.month(), n.day(), n.hour(), n.minute(), n.second());
  }
#endif
}

void syncRtcFromNtp() {
#if USE_RTC
  if (!have_rtc) return;
  uint32_t s = epochS();
  if (!s) return;
  DateTime cur = rtc.now();
  long diff = (long)cur.unixtime() - (long)s;
  if (diff > 2 || diff < -2) {                     // lệch quá 2 s mới ghi lại
    rtc.adjust(DateTime(s));
    Serial.println("[RTC] da dong bo DS3231 theo NTP");
  }
#endif
}

// -------------------------------------------------------------------------------------
// 7. OLED
// -------------------------------------------------------------------------------------
#if USE_RTC || USE_OLED
void scanI2C() {
  Serial.println("[I2C] Dang quet bus (SDA=GPIO8, SCL=GPIO9)...");
  int found = 0;
  for (uint8_t a = 1; a < 127; a++) {
    Wire.beginTransmission(a);
    if (Wire.endTransmission() == 0) {
      Serial.printf("[I2C]   tim thay thiet bi tai dia chi 0x%02X%s\n", a,
                    a == 0x3C || a == 0x3D ? "  <- OLED" : a == 0x68 ? "  <- DS3231" : "");
      found++;
      if (a == 0x3C || a == 0x3D) addr_oled = a;
    }
  }
  if (!found) Serial.println("[I2C]   KHONG THAY THIET BI NAO - kiem tra day SDA/SCL/VCC/GND");
}
#endif

void initOLED() {
#if USE_OLED
  if (!oled.begin(SSD1306_SWITCHCAPVCC, addr_oled)) {
    Serial.printf("[OLED] Khong khoi tao duoc tai 0x%02X. Kiem tra day va nguon 3V3.\n", addr_oled);
    return;
  }
  Serial.printf("[OLED] San sang tai dia chi 0x%02X\n", addr_oled);
  have_oled = true;
  oled.clearDisplay(); oled.setTextColor(SSD1306_WHITE); oled.setTextSize(1);
  oled.setCursor(0, 20); oled.println("  SMART ENERGY v22");
  oled.setCursor(0, 34); oled.println("  Dang ket noi WiFi...");
  oled.display();
#endif
}

void drawOLED() {
#if USE_OLED
  if (!have_oled) return;
  char t[16]; clockStr(t, sizeof(t));
  oled.clearDisplay();

  oled.setTextSize(1); oled.setCursor(0, 0); oled.print(t);
  oled.setCursor(70, 0);
  oled.print(WiFi.status() == WL_CONNECTED ? "W" : "-");
  oled.print(mqtt.connected() ? "M" : "-");
  if (buf_count) { oled.print(" B"); oled.print(buf_count); }
  else { oled.print(auto_mode ? " AUT" : " MAN"); }

  oled.drawFastHLine(0, 10, 128, SSD1306_WHITE);

  oled.setTextSize(2); oled.setCursor(0, 15);
  oled.print(demand_w, 2); oled.setTextSize(1); oled.print(" W");

  oled.setCursor(0, 34);
  oled.print(current_a, 3); oled.print("A  ");
  oled.print(energy_today_wh, 2); oled.print("Wh");

  oled.setCursor(0, 45);
  oled.print("Lim "); oled.print(peak_limit_w, 1); oled.print("W");
  if (alarm_over)       oled.print(" !OVER");
  else if (alarm_budget) oled.print(" !BUDG");
  else if (safe_mode)    oled.print(" SAFE");

  oled.setCursor(0, 56);
  oled.print("FAN:"); oled.print(fan_on ? "ON " : "OFF");
  oled.print(" LED:"); oled.print(led_on ? "ON" : "OFF");
  if (!led_on && led_shed != SHED_NONE) { oled.print("/"); oled.print(shedName(led_shed)); }
  oled.display();
#endif
}

// -------------------------------------------------------------------------------------
// 8. ĐO LƯỜNG
// -------------------------------------------------------------------------------------
float readMvAvg(int n) {
  uint32_t s = 0;
  for (int i = 0; i < n; i++) s += analogReadMilliVolts(PIN_ACS712);
  return (float)s / n / DIVIDER_RATIO;
}

void calibrateZero() {
  float s = 0;
  for (int i = 0; i < 20; i++) { s += readMvAvg(50); delay(10); }
  zero_mv = s / 20.0;
  Serial.printf("[CAL] zero = %.1f mV (ly thuyet ~2500 mV khi VCC = 5.0 V)\n", zero_mv);
}

void measureBlock() {
  unsigned long now = millis();
  float dt_h = (last_block ? (now - last_block) : BLOCK_MS) / 3600000.0;
  last_block = now;

  last_mv = readMvAvg(SAMPLES_PER_BLOCK);
  diff_mv = last_mv - zero_mv;

  // TRỊ TUYỆT ĐỐI: tải một chiều, nếu lỡ đấu ngược IP+/IP- thì vẫn đo đúng độ lớn
  float i = fabs(diff_mv) / ACS_MV_PER_A;
  if (i < I_DEADBAND_A) i = 0;
  current_a = i;
  power_w = V_NOMINAL * current_a;

  // TỰ HIỆU CHỈNH ĐIỂM 0: khi cả 2 tải đang TẮT, kéo zero_mv bám theo mức thực tế
  // (bù trôi do đổi nguồn USB <-> LM2596, do nhiệt độ). Hằng số thời gian ~12 giây.
  if (!fan_on && !led_on) {
    if (!zero_track_ms) zero_track_ms = now;
    if (now - zero_track_ms > 3000 && fabs(diff_mv) < 400)
      zero_mv += (last_mv - zero_mv) * 0.02f;
  } else {
    zero_track_ms = 0;
  }

  energy_today_wh += power_w * dt_h;
  energy_total_wh += power_w * dt_h;
  sum_block_p += power_w; n_block++;
}

// -------------------------------------------------------------------------------------
// 9. MÁY TRẠNG THÁI QUẢN LÝ TẢI (chạy cả khi mất mạng)
// -------------------------------------------------------------------------------------
void controlStep() {
  unsigned long now = millis();

  if (learn_pending && now - led_switch_ms >= TELEMETRY_MS) {
    float delta = fabs(demand_w - p_before_switch);
    if (delta > 0.2) led_est_w = (led_est_w <= 0) ? delta : 0.7 * led_est_w + 0.3 * delta;
    learn_pending = false;
  }

  bool over = demand_w > peak_limit_w;
  bool safe = demand_w < peak_limit_w - hysteresis_w;
  over_since = over ? (over_since ? over_since : now) : 0;
  safe_since = safe ? (safe_since ? safe_since : now) : 0;
  if (demand_w > peak_today_w) peak_today_w = demand_w;

  long k = todayKey();
  if (k && k != day_key) {
    if (day_key) { energy_today_wh = 0; peak_today_w = 0; budget_warned = false; alarm_budget = false; }
    day_key = k;
    if (led_shed == SHED_BUDGET && (auto_mode || safe_mode)) switchLed(true, SHED_NONE);
  }

  bool managed = auto_mode || safe_mode;

  if (budget_wh > 0) {
    if (!budget_warned && energy_today_wh >= 0.8 * budget_wh) { budget_warned = true; publishEvent("BUDGET_WARN", "80% ngan sach ngay"); }
    if (!alarm_budget && energy_today_wh >= budget_wh) { alarm_budget = true; publishEvent("BUDGET_EXCEEDED", "vuot ngan sach ngay"); }
  }
  if (managed && alarm_budget && led_on) {
    switchLed(false, SHED_BUDGET);
    publishEvent("SHED", "LED - vuot ngan sach ngay");
  }

  if (managed && led_on && over_since && now - over_since >= T_OVER_MS) {
    switchLed(false, SHED_PEAK);
    publishEvent("SHED", "LED - vuot nguong dinh");
  } else if (managed && !led_on && led_shed == SHED_PEAK && !alarm_budget &&
             safe_since && now - safe_since >= T_SAFE_MS &&
             now - led_switch_ms >= MIN_OFF_MS &&
             demand_w + led_est_w < peak_limit_w) {
    switchLed(true, SHED_NONE);
    publishEvent("RESTORE", "LED - dieu kien an toan on dinh");
  }

  bool should_alarm = over_since && now - over_since >= T_ALARM_MS && !led_on;
  if (should_alarm && !alarm_over) { alarm_over = true; publishEvent("ALARM_OVER_LIMIT", "van vuot nguong sau khi sa thai"); }
  if (!over && alarm_over) { alarm_over = false; publishEvent("ALARM_CLEAR", "cong suat da ve duoi nguong"); }
  buzzer(alarm_over);
}

// -------------------------------------------------------------------------------------
// 10. TELEMETRY + BỘ ĐỆM OFFLINE
// -------------------------------------------------------------------------------------
void bufferPush() {
  uint32_t ts = epochS();
  if (!ts) return;                       // không có mốc thời gian đáng tin thì không đệm
  buf[buf_head] = { ts, current_a, demand_w, (float)energy_today_wh,
                    (uint8_t)((fan_on ? 1 : 0) | (led_on ? 2 : 0) | (auto_mode ? 4 : 0) | (safe_mode ? 8 : 0)) };
  buf_head = (buf_head + 1) % BUF_SIZE;
  if (buf_count < BUF_SIZE) buf_count++;
}

void bufferFlush(int max_msgs) {
  while (buf_count > 0 && max_msgs-- > 0 && mqtt.connected()) {
    int idx = (buf_head - buf_count + BUF_SIZE) % BUF_SIZE;
    Rec& r = buf[idx];
    StaticJsonDocument<384> d;
    d["dev"] = DEVICE_ID; d["ts"] = (uint64_t)r.ts * 1000ULL; d["buffered"] = true;
    d["current_a"] = serialized(String(r.i, 3));
    d["power_w"] = serialized(String(r.p, 3));
    d["energy_today_wh"] = serialized(String(r.e, 4));
    d["fan"] = (bool)(r.flags & 1); d["led"] = (bool)(r.flags & 2);
    d["auto_mode"] = (bool)(r.flags & 4); d["safe_mode"] = (bool)(r.flags & 8);
    d["peak_limit_w"] = peak_limit_w;
    publishJson(T_TELEMETRY, d);
    buf_count--;
  }
}

void publishTelemetry() {
  seq++;
  StaticJsonDocument<768> d;
  d["dev"] = DEVICE_ID; d["ts"] = epochMs(); d["seq"] = seq;
  d["current_a"] = serialized(String(current_a, 3));
  d["power_w"] = serialized(String(demand_w, 3));
  d["energy_today_wh"] = serialized(String(energy_today_wh, 4));
  d["energy_total_wh"] = serialized(String(energy_total_wh, 3));
  d["peak_today_w"] = serialized(String(peak_today_w, 3));
  d["fan"] = fan_on; d["led"] = led_on; d["led_shed"] = shedName(led_shed);
  d["auto_mode"] = auto_mode; d["safe_mode"] = safe_mode;
  d["peak_limit_w"] = peak_limit_w; d["hysteresis_w"] = hysteresis_w; d["budget_wh"] = budget_wh;
  d["led_est_w"] = serialized(String(led_est_w, 2));
  d["alarm_over"] = alarm_over; d["alarm_budget"] = alarm_budget;
  d["sensor_mv"] = serialized(String(last_mv, 1)); d["zero_mv"] = serialized(String(zero_mv, 1));
  d["diff_mv"] = serialized(String(diff_mv, 1));
  d["rssi"] = WiFi.RSSI(); d["uptime_s"] = millis() / 1000;
  d["time_src"] = time_src; d["rtc"] = have_rtc; d["buffered_count"] = buf_count;
  bool sent = mqtt.connected();
  publishJson(T_TELEMETRY, d);

  char t[16]; clockStr(t, sizeof(t));
  Serial.printf("[#%lu %s] %.1fmV (lech %+.1fmV) I=%.3fA P=%.2fW E=%.3fWh | FAN:%s LED:%s(%s) | %s%s | MQTT:%s buf=%d\n",
    seq, t, last_mv, diff_mv, current_a, demand_w, energy_today_wh, fan_on ? "ON" : "OFF", led_on ? "ON" : "OFF",
    shedName(led_shed), auto_mode ? "AUTO" : "MANUAL", safe_mode ? " SAFE" : "",
    sent ? "DA GUI" : "CHUA GUI", buf_count);
}
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
void loop() {
  unsigned long now = millis();

  if (now - last_block >= BLOCK_MS) measureBlock();

  if (now - last_tele >= TELEMETRY_MS) {
    last_tele = now;
    demand_w = n_block ? sum_block_p / n_block : 0;
    sum_block_p = 0; n_block = 0;
    controlStep();                       // điều khiển cục bộ trước
    if (mqtt.connected()) publishTelemetry();
    else bufferPush();                   // mất mạng: đệm lại để gửi bù
  }

  if (now - last_oled >= OLED_MS) { last_oled = now; drawOLED(); }

  if (now - last_save >= SAVE_MS) {
    last_save = now;
    prefs.putDouble("e_today", energy_today_wh);
    prefs.putDouble("e_total", energy_total_wh);
    prefs.putLong("day", day_key);
  }

  networkTask();
}

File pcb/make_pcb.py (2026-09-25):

#!/usr/bin/env python3
"""
Sinh mạch in 1 lớp (chỉ BOTTOM) cho Project 03 - Smart Energy.
Toàn bộ linh kiện là loại cắm (through-hole), module relay để NGOÀI, chỉ cắm hàng rào.

Xuất ra:
  smart_energy.kicad_pcb            mở bằng KiCad 7/8/9
  BOTTOM_mirrored_iron.pdf          bản in 1:1 ĐÃ LẬT GƯƠNG để ủi đồng
  BOTTOM_normal_check.pdf           bản không lật, để đối chiếu khi dò mạch
  TOP_placement.pdf                 sơ đồ cắm linh kiện (nhìn từ mặt linh kiện)
  preview.png                       ảnh xem nhanh
  DRC_REPORT.txt                    kết quả tự kiểm tra khoảng cách

Chạy: python3 make_pcb.py
"""
import math
import os

W, H = 100.0, 80.0          # kích thước board (mm)
CLR = 0.4                    # khoảng cách đồng tối thiểu (mm)
POUR_CLR = 0.5               # khoảng cách của vùng phủ đồng GND
EDGE_KEEPOUT = 1.0

# ---------------------------------------------------------------- linh kiện
# pad: (tên, x, y, net, drill, dia, shape)  shape: 'circle' | 'rect'
PADS = []
COMPS = []                   # (ref, value, mô tả, [chỉ số pad])
SILK = []                    # (text, x, y, size, rot, layer)


def comp(ref, value, desc, pads):
    idx = []
    for name, x, y, net, drill, dia, shape in pads:
        idx.append(len(PADS))
        PADS.append(dict(ref=ref, name=name, x=x, y=y, net=net, drill=drill, dia=dia, shape=shape))
    COMPS.append(dict(ref=ref, value=value, desc=desc, pads=idx))


def header(ref, value, desc, x, y0, nets, pitch=2.54, drill=1.0, dia=2.0):
    pads = []
    for i, n in enumerate(nets):
        pads.append((str(i + 1), x, y0 + i * pitch, n, drill, dia, 'rect' if i == 0 else 'circle'))
    comp(ref, value, desc, pads)


NC = ''   # không nối

# ---- ESP32-S3-DevKitC-1 (2 hàng 1x22, cách nhau 22.86 mm = 0.9 inch) --------
# Thứ tự chân theo tài liệu Espressif (J1 trái, J3 phải), pin 1 ở phía cổng USB.
J1_NETS = ['+3V3', NC, NC, NC, NC, NC, NC, NC, NC, NC, NC, 'SDA', NC, NC, 'SCL',
           NC, NC, 'IN1', 'IN2', 'BUZZ', '+5V', 'GND']
J1_LBL = ['3V3', '3V3', 'RST', 'IO4', 'IO5', 'IO6', 'IO7', 'IO15', 'IO16', 'IO17', 'IO18',
          'IO8', 'IO3', 'IO46', 'IO9', 'IO10', 'IO11', 'IO12', 'IO13', 'IO14', '5V', 'GND']
J3_NETS = ['GND', NC, NC, 'ADC', NC, NC, NC, NC, NC, NC, NC, NC, NC, NC, NC, NC, NC,
           NC, NC, NC, 'GND', 'GND']
J3_LBL = ['GND', 'TX', 'RX', 'IO1', 'IO2', 'IO42', 'IO41', 'IO40', 'IO39', 'IO38', 'IO37',
          'IO36', 'IO35', 'IO0', 'IO45', 'IO48', 'IO47', 'IO21', 'IO20', 'IO19', 'GND', 'GND']

header('J1', '1x22', 'ESP32-S3 DevKitC hàng TRÁI', 40.0, 10.0, J1_NETS)
header('J3', '1x22', 'ESP32-S3 DevKitC hàng PHẢI', 62.86, 10.0, J3_NETS)

# ---- module I2C ------------------------------------------------------------
header('J4', '1x4', 'DS3231 (RTC)', 14.0, 15.08, ['+3V3', 'SDA', 'SCL', 'GND'])
header('J5', '1x4', 'OLED SSD1306', 24.0, 15.08, ['+3V3', 'SDA', 'SCL', 'GND'])

# ---- module relay 2 kênh (ĐỂ NGOÀI, chỉ cắm rào) ---------------------------
header('J6', '1x5', 'Relay 2 kênh (module ngoài)', 20.0, 40.0,
       ['IN1', 'IN2', '+3V3', '+5V', 'GND'])

# ---- module ACS712 + cầu phân áp ------------------------------------------
header('J7', '1x3', 'ACS712-05B', 88.0, 14.0, ['+5V', 'ACS_OUT', 'GND'])
comp('R1', '10k', 'Phân áp trên', [('1', 76.0, 16.54, 'ADC', 0.9, 1.9, 'rect'),
                                   ('2', 86.16, 16.54, 'ACS_OUT', 0.9, 1.9, 'circle')])
comp('R2', '20k', 'Phân áp dưới', [('1', 76.0, 20.0, 'ADC', 0.9, 1.9, 'rect'),
                                   ('2', 76.0, 30.16, 'GND', 0.9, 1.9, 'circle')])
comp('C2', '100nF', 'Lọc nhiễu ADC', [('1', 70.0, 20.0, 'ADC', 0.9, 1.9, 'rect'),
                                      ('2', 70.0, 25.08, 'GND', 0.9, 1.9, 'circle')])

# ---- khối nguồn (cột trái) -------------------------------------------------
comp('J8', 'DOMINO', 'Ngõ ra 12V đã qua cầu chì',
     [('1', 5.0, 8.0, '+12F', 1.3, 2.6, 'rect'), ('2', 5.0, 10.54, 'GND', 1.3, 2.6, 'circle')])
comp('J9', 'DOMINO', 'Nguồn 12V vào',
     [('1', 5.0, 15.0, 'GND', 1.3, 2.6, 'rect'), ('2', 5.0, 20.08, '+12V', 1.3, 2.6, 'circle')])
comp('F1', '2A', 'Cầu chì (đế 5x20 hoặc dây)',
     [('1', 5.0, 25.0, '+12V', 1.3, 2.6, 'rect'), ('2', 5.0, 30.08, '+12F', 1.3, 2.6, 'circle')])
comp('J10', '1x2', 'LM2596 ngõ VÀO (IN+/IN-)',
     [('1', 5.0, 35.0, '+12F', 1.0, 2.0, 'rect'), ('2', 5.0, 37.54, 'GND', 1.0, 2.0, 'circle')])
comp('J11', '1x2', 'LM2596 ngõ RA (OUT+/OUT-)',
     [('1', 5.0, 42.0, '+5V', 1.0, 2.0, 'rect'), ('2', 5.0, 44.54, 'GND', 1.0, 2.0, 'circle')])
comp('C1', '100uF', 'Lọc nguồn 5V', [('1', 12.0, 54.0, '+5V', 1.0, 2.0, 'rect'),
                                     ('2', 14.5, 54.0, 'GND', 1.0, 2.0, 'circle')])
comp('C3', '100nF', 'Lọc nguồn 3V3', [('1', 15.0, 29.0, '+3V3', 0.9, 1.9, 'rect'),
                                      ('2', 15.0, 34.08, 'GND', 0.9, 1.9, 'circle')])

# ---- dây nối GND trên mặt linh kiện (bắc qua đường 5V) --------------------
comp('JW1', 'DAY NOI', 'Dây nối GND bắc qua đường 5V',
     [('1', 23.5, 58.4, 'GND', 1.0, 2.0, 'rect'), ('2', 23.5, 63.2, 'GND', 1.0, 2.0, 'circle')])
comp('JW2', 'DAY NOI', 'Dây nối GND bắc qua 2 đường IN1/IN2',
     [('1', 31.0, 51.0, 'GND', 1.0, 2.0, 'rect'), ('2', 31.0, 58.0, 'GND', 1.0, 2.0, 'circle')])

# ---- còi báo động ----------------------------------------------------------
comp('BZ1', 'BUZZER 5V', 'Còi chíp 5V active', [('1', 12.0, 64.0, '+5V', 1.0, 2.2, 'rect'),
                                                ('2', 19.62, 64.0, 'BZC', 1.0, 2.2, 'circle')])
comp('Q1', 'S8050', 'NPN lái còi (E-B-C)', [('1', 30.0, 64.0, 'GND', 0.9, 1.9, 'rect'),
                                            ('2', 30.0, 66.54, 'QB', 0.9, 1.9, 'circle'),
                                            ('3', 30.0, 69.08, 'BZC', 0.9, 1.9, 'circle')])
comp('R3', '1k', 'Điện trở cực nền', [('1', 34.0, 66.54, 'QB', 0.9, 1.9, 'rect'),
                                      ('2', 44.16, 66.54, 'BUZZ', 0.9, 1.9, 'circle')])
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
